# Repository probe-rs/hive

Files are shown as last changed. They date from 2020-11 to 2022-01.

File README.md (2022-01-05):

# hive
Compact and modular Raspberry Pi shield for testing probe-rs

## Navigation
| Directory | Contents |
| --- | --- |
| [component_library](./component_library/) | The global hive project component library for KiCad |
| [concept](./concept/) | Concept files of this project as well as testboards, preliminary part lists etc. |
| [daughterboard](./daughterboard/) | Template of target daughterboard and existing implementations |
| [renders_3dmodels](./renders_3dmodels/) | 3D models and renders of shields |
| [shields](./shields/) | Shields needed to assemble the testing hardware |

# Overview
For more information on the assembly and the testrack itself, please have a look at the [Hive wiki](https://github.com/probe-rs/hive/wiki)

## PCB

###### Probe Shield
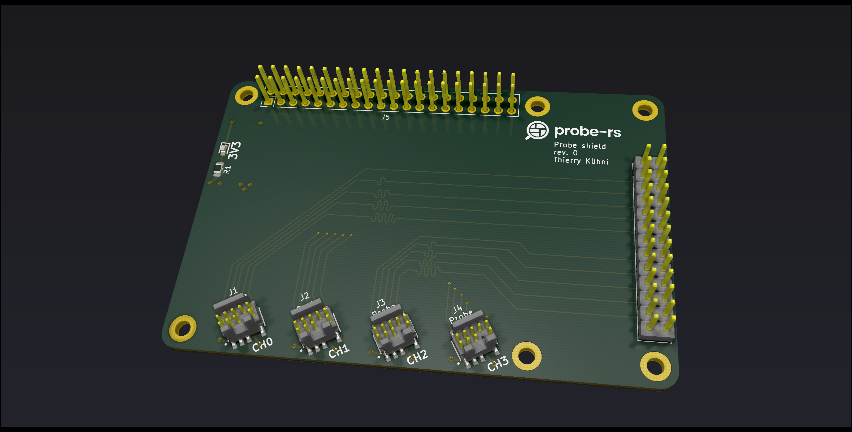
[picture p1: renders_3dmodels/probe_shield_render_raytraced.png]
Probe shield front view

###### Target Stack Shield
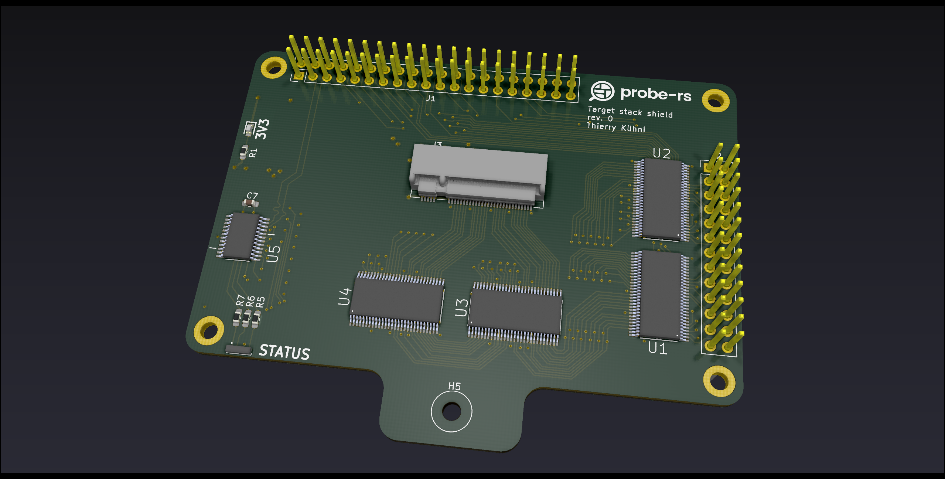
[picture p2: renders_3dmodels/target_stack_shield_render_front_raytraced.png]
Target stack shield front view

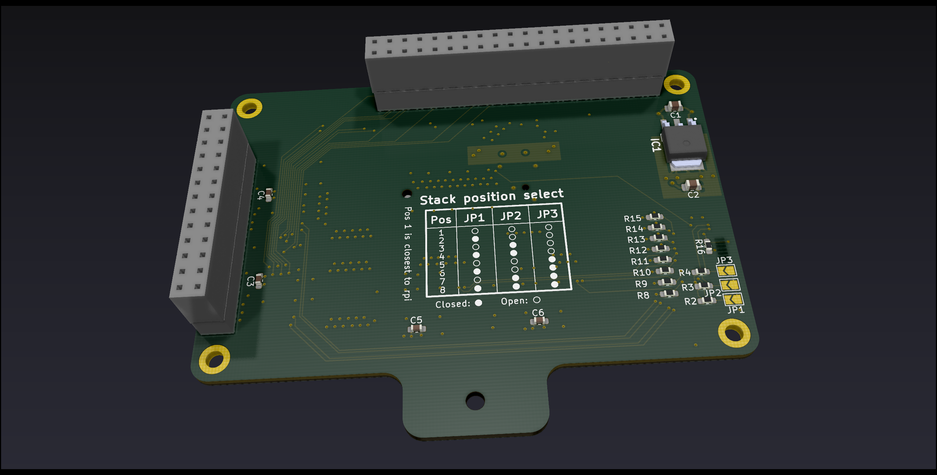
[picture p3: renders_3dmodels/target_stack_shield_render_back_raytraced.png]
Target stack shield back view


## Assembly
The full assembly consists of 1x Raspberry Pi 4 B, 1x Probe shield and up to 8x Target stack shield. Each target stack shield can hold one daughterboard with 4 targets (not included in the pictures below). Optionally you can mount a 3D printed probe holder case to put the probes in.
Full assembly view
Basic assembly front
Basic assembly top

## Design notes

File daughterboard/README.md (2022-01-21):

# Daughterboards
This Folder contains all existing implementations of Hive daughterboards. Generally the MCUs on the daughterboards are sorted by manufacturer or even by series.

If you want to create a new custom daughterboard, please refer to the [wiki page](https://github.com/probe-rs/hive/wiki/Creating-a-custom-Daughterboard) for further instructions.

| Daughterboard | MCUs |
|--|--|
| [ATSAMD_00](./ATSAMD_00/) | ATSAMD10C13A-SSUT, ATSAMD09D14A-MUT, ATSAMD51J18A-A-AU-ND, ATSAMD21E16L-AFT  |
| [ESP32_SIFIVE_00](./ESP32_SIFIVE_00/) | ESP32-S3-WROOM-1-N8R8, ESP32-S2, LoFive-R1 (FE310-G002), ESP32-C3 |
| [LPC_00](./LPC_00/) | LPC845M301JHI33Y, LPC1114FDH28/102:5, LPC55S69JBD64K, LPC1313FBD48/01,15 |
| [NRF_00](./NRF_00/) | BT40E (nRF5340), nRF52832-QFAB-T, NRF52840-USB-DONGLE, NRF51822-QFAC-R7 |
| [STM32_00](./STM32_00/) | STM32G031F4P6, STM32L151C8T6A, STM32F103C8, STM32F401CCU  |

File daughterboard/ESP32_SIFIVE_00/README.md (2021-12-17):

## Daughterboard ESP32_SIFIVE_00
This board features RISC-V and Xtensa cores.

### Targets
The following targets are implemented on this Daughterboard:
| Designation | MCU |
| --- | --- |
| target0 | ESP32-S3-WROOM-1-N8R8 |
| target1 | ESP32-S2 |
| target2 | LOFIVE-R1 (FE310-G002) |
| target3 | ESP32-C3 |

### Partlist
The partlist for this Daughterboard is available [here](https://octopart.com/bom-tool/JTwGMmL3).

### Other
The target3 and target1 devices have separate flash memory, as the currently available cores do not have any embedded flash.

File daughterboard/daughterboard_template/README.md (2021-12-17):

## Daughterboard Template
This is the Daughterboard template readme file. On implementations this text should be replaced by a short description.

More information on how to create a new Daughterboard can be found in the [wiki](https://github.com/probe-rs/hive/wiki/Creating-a-custom-Daughterboard).

### Targets
The following targets are implemented on this Daughterboard:
| Designation | MCU |
| --- | --- |
| target0 | ATSAMD21E16L-AFT |
| target1 | another MCU model |
| target2 | ... |
| target3 | ... |

### Partlist
Add a link to the partlist here. Either a link to the partlist file in the repo or an Octopart BOM.

### Other
If you need to add any more information regarding this specific Daughterboard please do so here.

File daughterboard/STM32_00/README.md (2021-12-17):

## Daughterboard STM32_00
This Daughterboard features several STM32 MCUs.

### Targets
The following targets are implemented on this Daughterboard:
| Designation | MCU |
| --- | --- |
| target0 | STM32G031F4P6 |
| target1 | STM32F401CCU6 |
| target2 | STM32L151C8T6A |
| target3 | STM32F103C8T6 |

### Partlist
The partlist for this Daughterboard is available [here](https://octopart.com/bom-tool/za3WrhSx).

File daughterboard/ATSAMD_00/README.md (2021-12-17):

## ATSAMD_00
A daughterboard which contains a selection of ATSAMD MCUs.

### Targets
The following targets are implemented on this Daughterboard:
| Designation | MCU |
| --- | --- |
| target0 | ATSAMD10C13A-SSUT |
| target1 | ATSAMD09D14A-MUT |
| target2 | ATSAMD51J18A-AU |
| target3 | ATSAMD21E16L-AFT |

### Partlist
The partlist for this Daughterboard is available [here](https://octopart.com/bom-tool/9WbPLhTP).

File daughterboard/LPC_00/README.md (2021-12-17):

## Daughterboard LPC_00
This Daughterboard features several LPC MCUs.

### Targets
The following targets are implemented on this Daughterboard:
| Designation | MCU |
| --- | --- |
| target0 | LPC845M301JHI33Y |
| target1 | LPC1114FDH28/102:5 |
| target2 | LPC55S69JBD64K |
| target3 | LPC1313FBD48/01,15 |

### Partlist
The partlist for this Daughterboard is available [here](https://octopart.com/bom-tool/fNupy8w4).

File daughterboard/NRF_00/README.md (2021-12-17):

## Daughterboard NRF_00
This Daughterboard features several nRF MCUs.

### Targets
The following targets are implemented on this Daughterboard:
| Designation | MCU |
| --- | --- |
| target0 | BT40E (nRF5340) |
| target1 | NRF52832-QFAB-T |
| target2 | NRF52840-DONGLE |
| target3 | NRF51822-QFAC-R7 |

### Partlist
The partlist for this Daughterboard is available [here](https://octopart.com/bom-tool/1QN2uwwk).

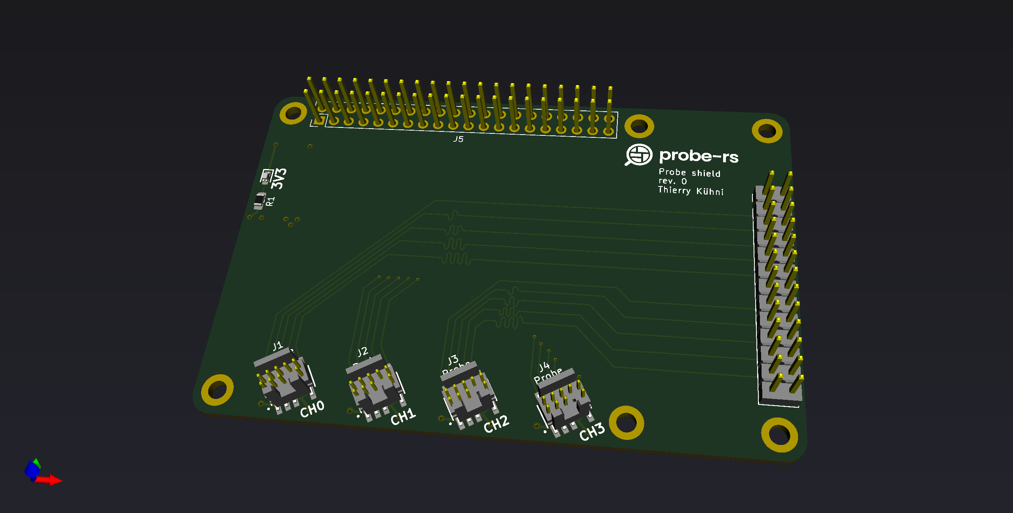
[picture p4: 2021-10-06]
renders_3dmodels/probe_shield_render.png

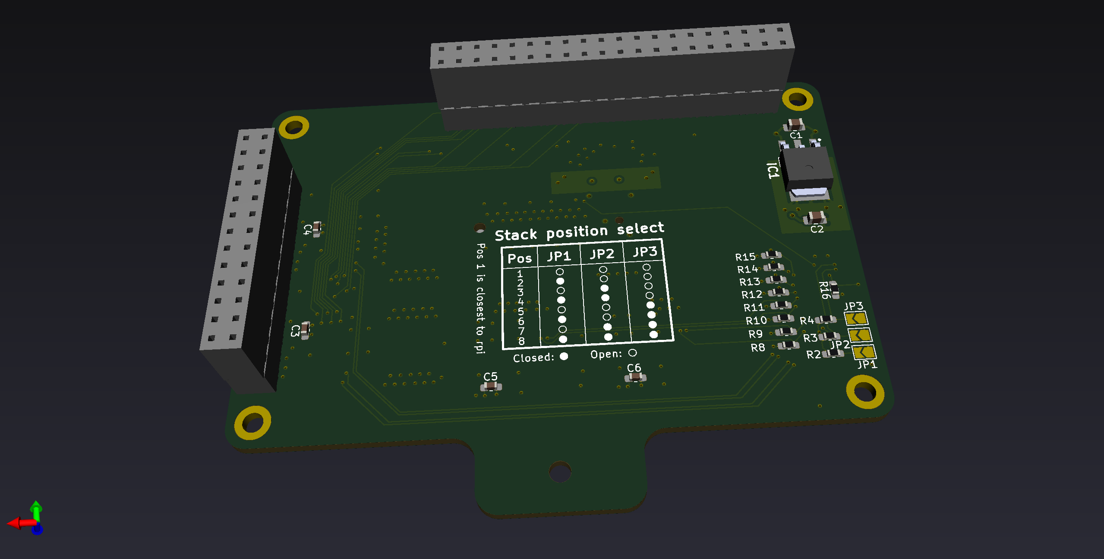
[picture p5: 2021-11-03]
renders_3dmodels/target_stack_shield_render_back.png

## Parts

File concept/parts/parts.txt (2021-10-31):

PCB Pins/Receptacles for Rpi & Probe Bus:
	https://www.samtec.com/
	ESQ-120-34-L/T-D (40Pin)
	ESQ-110-34-L/T-D (20Pin)
	
	SSQ-120-04-L/T-D (40Pin)
	SSQ-110-04-L/T-D (20Pin)
	
	TSM-120-03-F/L-DV (40Pin)
	TSM-110-03-F/L-DV (20Pin)
	with
	SSM-120-F/L-DV (40Pin)
	SSM-110-F/L-DV (20Pin)

Probe bus 23pin receptacle for probe shield:
	TSW-113-07-F/L/G-D

PCIE x4 64pin angled:
	https://www.mouser.ch/ProductDetail/Samtec/PCIE-064-02-F-D-RA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

M2 67pin:
	https://www.mouser.ch/ProductDetail/TE-Connectivity/2199230-3?qs=EQCnRgr4b6HElQOKr5ma1Q%3D%3D
	
ARM 10pin connector:
	with keying: FTSH-105-01-F-DV-007-K
	Cheaper alternative: 20021121-00010T1LF

Status LED:
	https://www.mouser.ch/ProductDetail/Kingbright/APFA2507LSURKSYKZGKC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
	https://www.mouser.ch/ProductDetail/OSRAM-Opto-Semiconductors/KRTB-AILMS1-5B5C-B1B12-0-R18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

Power OK LED:
	https://www.mouser.ch/ProductDetail/Wurth-Elektronik/150060VS75000?qs=LlUlMxKIyB1Q1Bi5mQ%2FKLw%3D%3D
	
IO expander:
	MCP23017
	PCA9535
	PCA9535CPW https://www.mouser.ch/ProductDetail/NXP-Semiconductors/PCA9535CPW118?qs=LOCUfHb8d9scuH4BeiaP2A%3D%3D
	
Digital bus switches:
	SN74CB3Q16245 (2x8Bit)
	SN74CB3T16211 (2x12Bit, 3pins required for switching, 5V to 3.3V level shift if VCC=3.3V) TVSOP-56 or TSSOP-56

Rotary DIP Switch:
	https://www.mouser.ch/ProductDetail/CUI-Devices/RDS-10S-74385-SMT?qs=zW32dvEIR3sfpstXH4BZkQ%3D%3D (10 positions, binary)

LDO 3.3V:
	https://www.mouser.ch/ProductDetail/onsemi/NCP1117DT33T5G?qs=Gev%252BmEvV0ibY9yFNc3ZYyw%3D%3D (1A, 1.2V dropout)
	https://www.mouser.ch/ProductDetail/Diodes-Incorporated/AZ1117CR-33TRG1?qs=FKu9oBikfSlEg7waHw2tMw%3D%3D (800mA, 1.3V dropout)
	
Condensator 10uF:
	https://www.mouser.ch/ProductDetail/Taiyo-Yuden/LMK212ABJ106MG-T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

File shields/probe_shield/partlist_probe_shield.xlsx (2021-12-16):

Reference | Value | Manufacturer Part number | QTY | Mouser Price (CHF) | Digikey Price (CHF) | Mouser Total | Digikey Total
> C1, C2 | Capacitor 10uF | CL21A106KPFNNNF | 2 | 0.13 | 0.15 | 0.26 | 0.3
IC1 | NCP1117DT33T5G | NCP1117DT33T5G | 1 | 0.64 | 0.62 | 0.64 | 0.62
J1 | Probe Channel 0 | FTSH-105-01-F-DV-007-K | 1 | 3.61 | 3.56 | 3.61 | 3.56
J2 | Probe Channel 1 | FTSH-105-01-F-DV-007-K | 1 | 3.61 | 3.56 | 3.61 | 3.56
J3 | Probe Channel 2 | FTSH-105-01-F-DV-007-K | 1 | 3.61 | 3.56 | 3.61 | 3.56
J4 | Probe Channel 3 | FTSH-105-01-F-DV-007-K | 1 | 3.61 | 3.56 | 3.61 | 3.56
J5 | GPIO shield connector 40pin | Adafruit 1979 | 1 | 2.77 | 2.74 | 2.77 | 2.74
J6 | probe shield connector 26pin | TSW-113-07-L-D | 1 | 2.02 | 2.01 | 2.02 | 2.01
LED1 | 3.3V OK (green) | 150060VS75000 | 1 | 0.13 | 0.14 | 0.13 | 0.14
R1 | Resistor 0603 560Ohm |  | 1 | - | -
 |  |  |  |  | Total CHF | 20.26 | 20.05

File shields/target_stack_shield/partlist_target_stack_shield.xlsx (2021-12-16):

Reference | Value | Manufacturer Part number | QTY | Mouser Price (CHF) | Digikey Price (CHF) | Mouser Total | Digikey Total
> C1, C2 | Capacitor 0805 10uF | CL21A106KPFNNNF | 2 | 0.13 | 0.15 | 0.26 | 0.3
> C3-C7 | Capacitor 0603 100nF |  | 5 | - | -
IC1 | NCP1117DT33T5G | NCP1117DT33T5G | 1 | 0.64 | 0.62 | 0.64 | 0.62
J1 | GPIO shield connector 40pin | Adafruit 1979 | 1 | 2.77 | 2.74 | 2.77 | 2.74
J2 | probe shield connector 26pin | Adafruit 1112 | 1 | 1.82 | 1.81 | 1.82 | 1.81
J3 | PCIE M.2 Key B 4.2H | 2199230-3 | 1 | 1.21 | 1.2 | 1.21 | 1.2
LED1 | 3.3V OK (green) | 150060VS75000 | 1 | 0.13 | 0.14 | 0.13 | 0.14
LED2 | KRTB_AILMS1-5B5C-B1B12-0-R18 | KRTB AILMS1-5B5C-B1B12-0-R18 | 1 | 0.38 | 0.38 | 0.38 | 0.38
R1 | Resistor 0603 560Ohm |  | 1 | - | -
> R2-R4, R8-R16 | Resistor 0603 100kOhm |  | 12 | - | -
R5 | Resistor 0603 6.8kOhm |  | 2 | - | -
R6 | Resistor 0603 10kOhm |  | 1 | - | -
> U1-U4 | SN74CB3T16211DGGR | SN74CB3T16211DGGR | 4 | 2.67 | 2.64 | 10.68 | 10.56
U5 | PCA9535CPW,118 |  | 1 | 1.92 | 1.9 | 1.92 | 1.9
 |  |  |  |  | Total CHF | 19.81 | 19.65

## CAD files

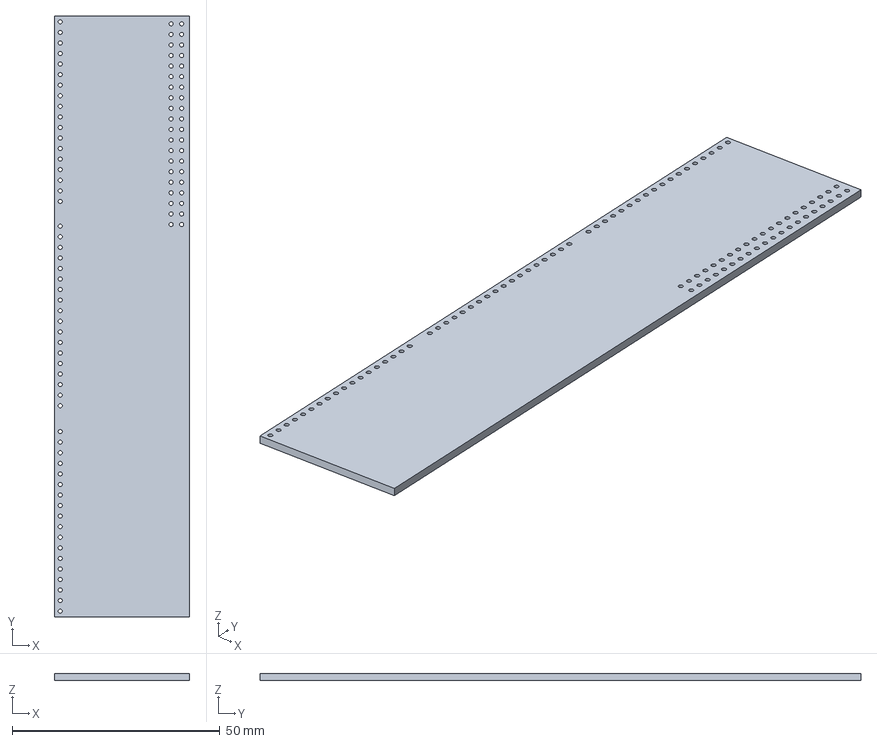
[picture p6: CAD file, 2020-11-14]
3lanes/3lanes/3lanes.step
32.5 x 144.5 x 1.60 mm

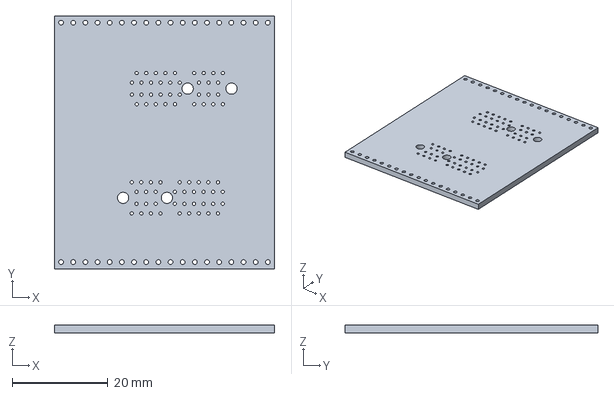
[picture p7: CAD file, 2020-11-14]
8channels/probe-rs-hive.step
46.0 x 52.8 x 1.60 mm

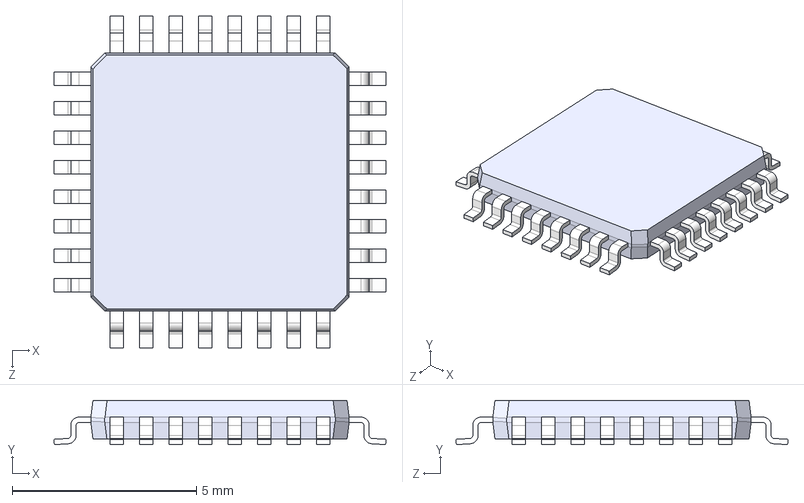
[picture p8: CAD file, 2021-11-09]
daughterboard/ATSAMD_00/component_library/3d_models/ATSAMD21E16L-AFT.step
9.00 x 1.20 x 9.00 mm

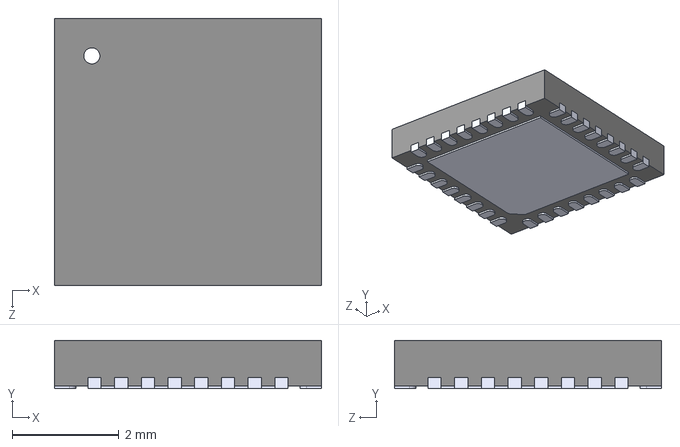
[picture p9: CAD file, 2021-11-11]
daughterboard/ESP32_SIFIVE_00/component_library/3d_models/ESP32-C3FH4.step
5.00 x 0.9 x 5.00 mm

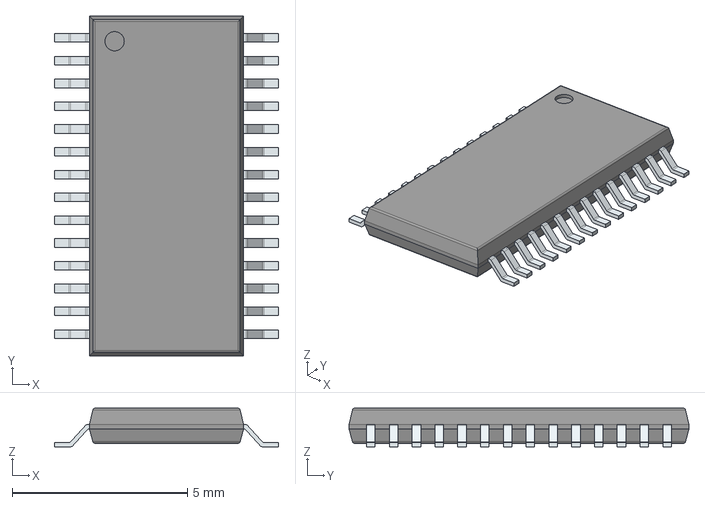
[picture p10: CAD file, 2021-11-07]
daughterboard/LPC_00/component_library/3d_models/LPC1114FDH28_102_5.stp
6.40 x 9.70 x 1.10 mm
PinsArrayLR

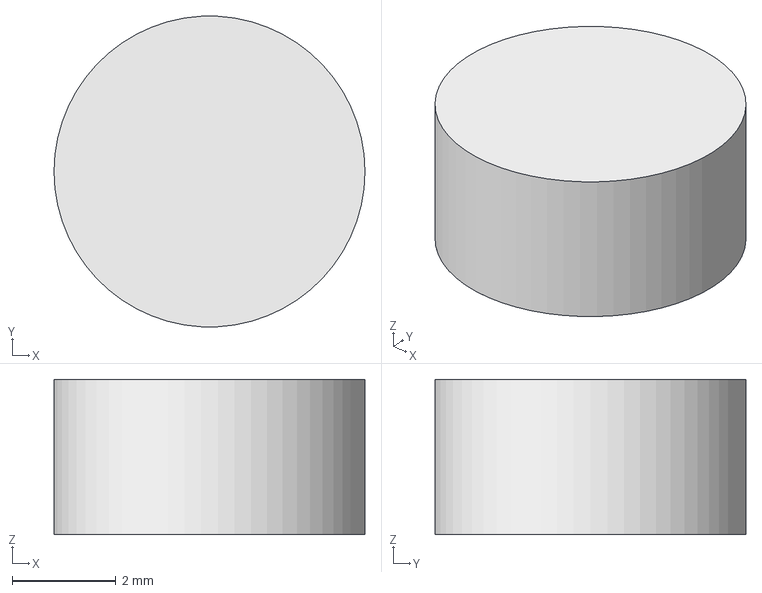
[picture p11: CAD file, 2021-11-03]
renders_3dmodels/Assembly/magnet.FCStd
6.00 x 5.99 x 3.00 mm

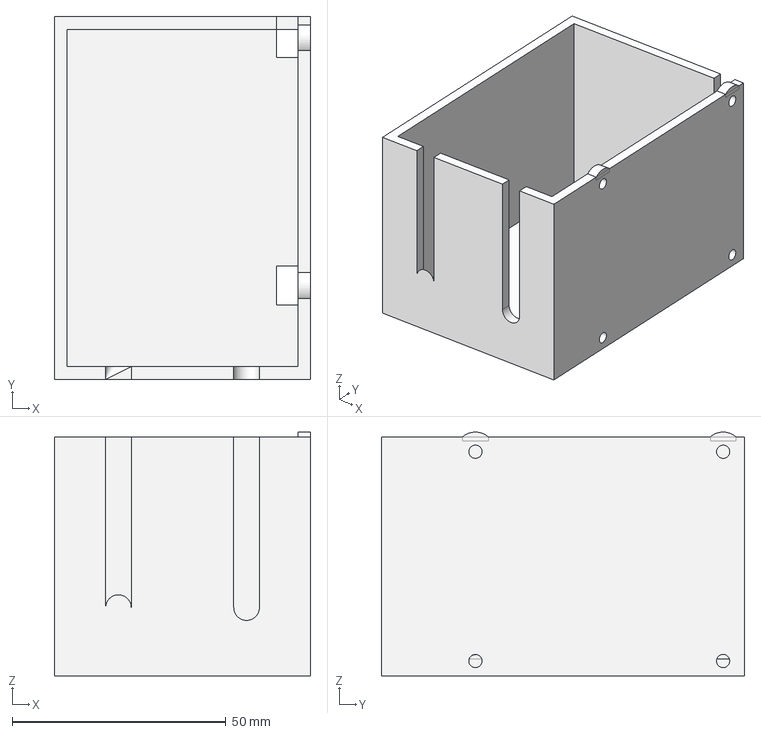
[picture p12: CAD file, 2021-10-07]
renders_3dmodels/Probe_holder/probe_holder_60mm.step
60.0 x 85.0 x 57.1 mm

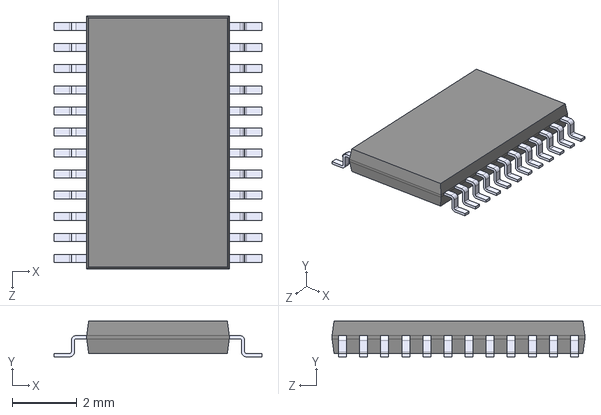
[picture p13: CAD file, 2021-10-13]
component_library/3d_models/PCA9535CPW_118.step
6.40 x 1.10 x 7.80 mm

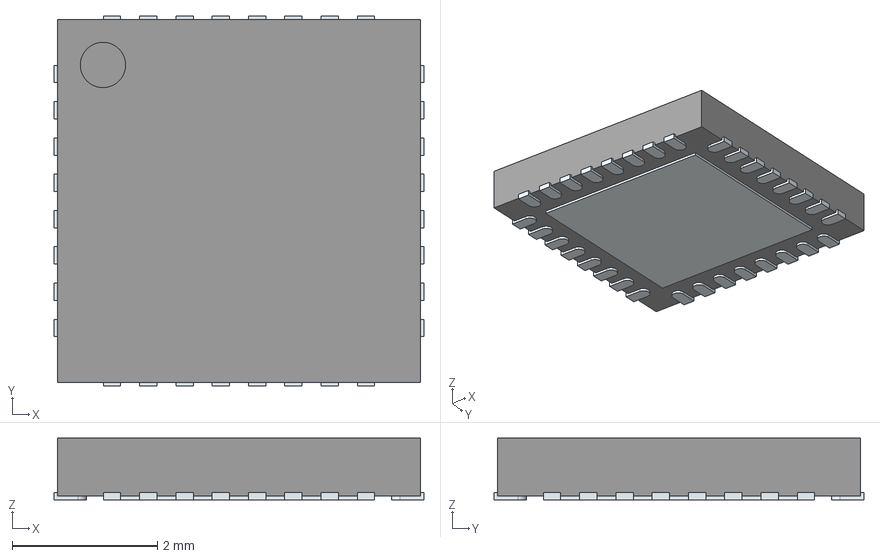
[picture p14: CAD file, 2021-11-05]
daughterboard/LPC_00/component_library/3d_models/LPC845M301JHI33Y.stp
5.10 x 5.10 x 0.85 mm
ThermalPin
PinsArrayLR
PinsArrayTB

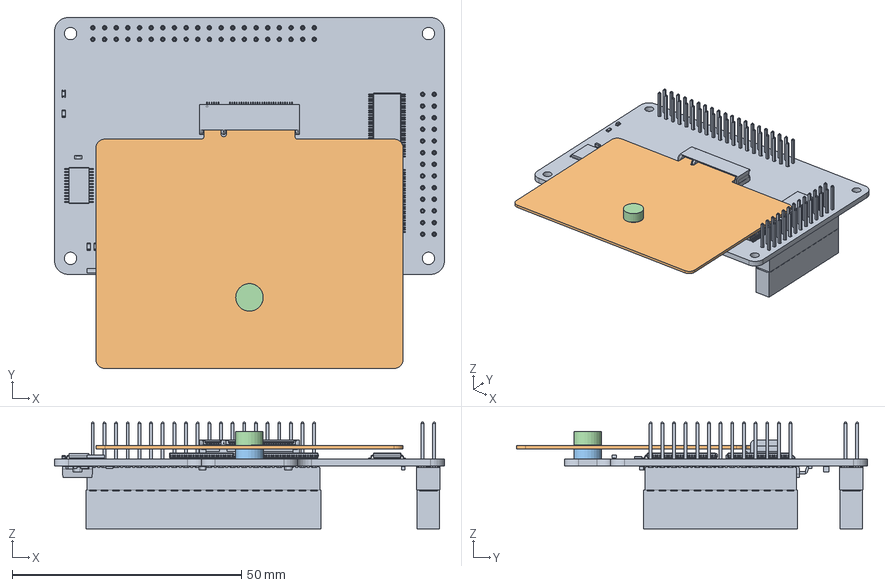
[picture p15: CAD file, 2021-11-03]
renders_3dmodels/Assembly/target_stack_shield_wDaughterboard.FCStd
85.0 x 76.5 x 23.2 mm
target_stack_shield1_001
daughterboard_template1_001
magnet_001
magnet_002

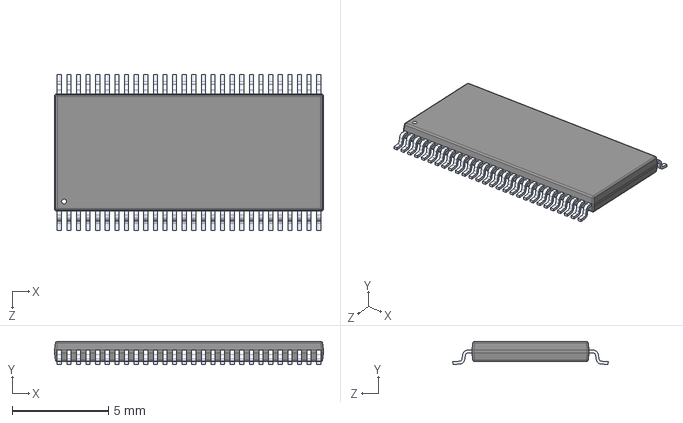
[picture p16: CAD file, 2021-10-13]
component_library/3d_models/SN74CB3T16211DGGR.step
14.0 x 1.20 x 8.10 mm

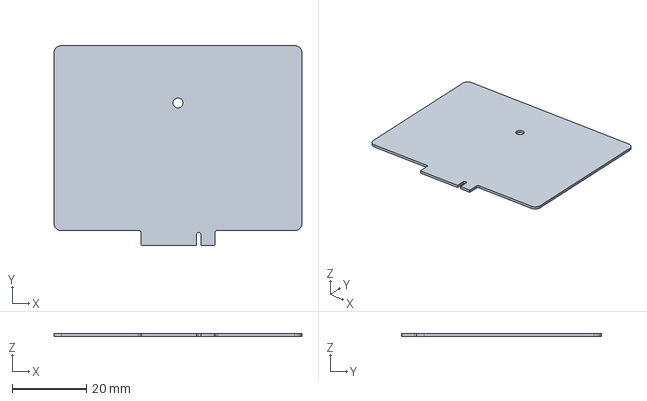
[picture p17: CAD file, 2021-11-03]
renders_3dmodels/Assembly/daughterboard_template.step
67.0 x 54.0 x 0.8 mm

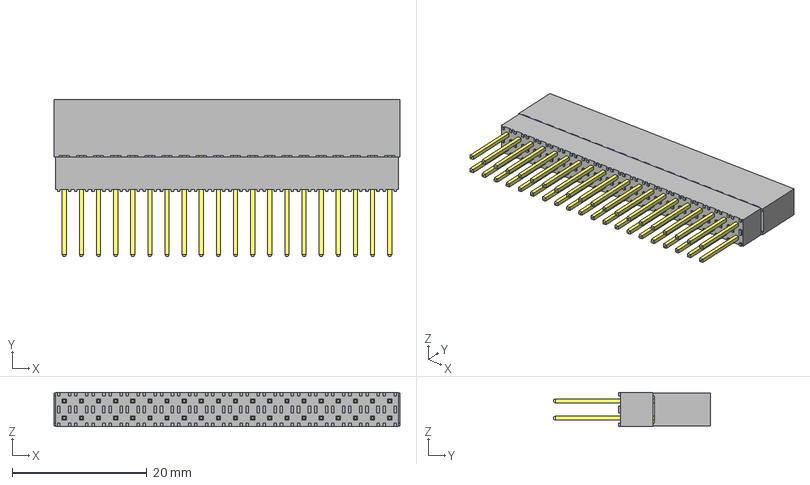
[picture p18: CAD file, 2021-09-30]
component_library/3d_models/ESQ-120-24-L-D.stp
51.3 x 23.2 x 5.08 mm
_ESQ-120-24-L-D_socket
_ESQ-120-24-L-D_pins
_ESQ-120-24-G-D-LL_bpins

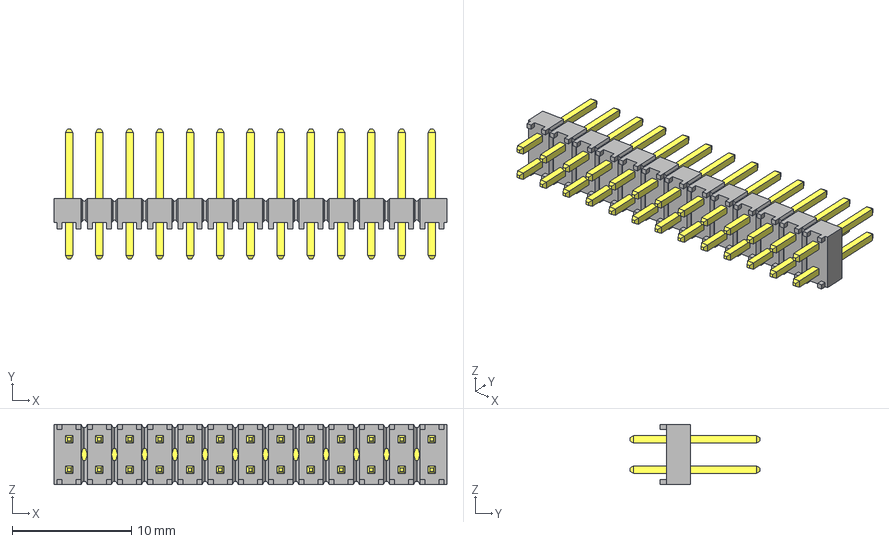
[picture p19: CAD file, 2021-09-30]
component_library/3d_models/TSW-113-07-F-D.stp
33.0 x 10.9 x 5.08 mm
_TSW-113-07-F-D_body
_T-1S6-07-TSW-1-07-13-D

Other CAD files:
renders_3dmodels/Probe_holder/probe_holder.FCStd
renders_3dmodels/Assembly/rpi4b.step
component_library/3d_models/FTSH-105-01-F-DV-007-K.stp
component_library/3d_models/ESQ-113-24-L-D.stp
component_library/3d_models/150060VS75000.stp
component_library/3d_models/2199230-3.step
component_library/3d_models/CUI_DEVICES_RDS-10S-74385-SMT.step
component_library/3d_models/KRTB_AILMS1-5B5C-B1B12-0-R18.stp
component_library/3d_models/NCP1117DT33T5G.STEP
renders_3dmodels/Assembly/m2_5_standoff_16mm.FCStd
renders_3dmodels/Assembly/m2_5_standoff_16mm.step
renders_3dmodels/Assembly/m2_5_standoff_18mm.FCStd
renders_3dmodels/Assembly/m2_5_standoff_18mm.step
renders_3dmodels/Assembly/rpi4b.FCStd

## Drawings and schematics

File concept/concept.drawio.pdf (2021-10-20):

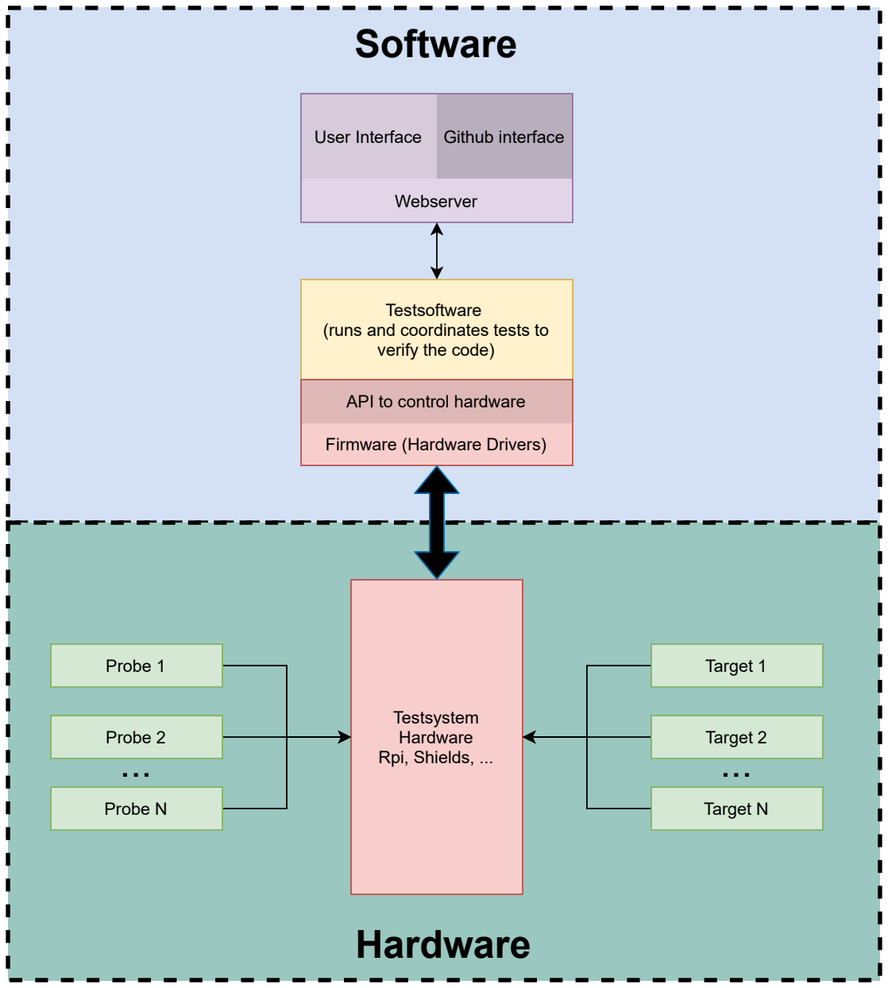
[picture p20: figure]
User Interface Github interface; Webserver; Testsoftware (runs and coordinates tests to verify the code); Firmware (Hardware Drivers); API to control hardware; Testsystem Hardware Rpi, Shields, ...; Probe 1; Probe 2; Probe N; Target 1; Target 2; Target N; Hardware; Software

# Layout

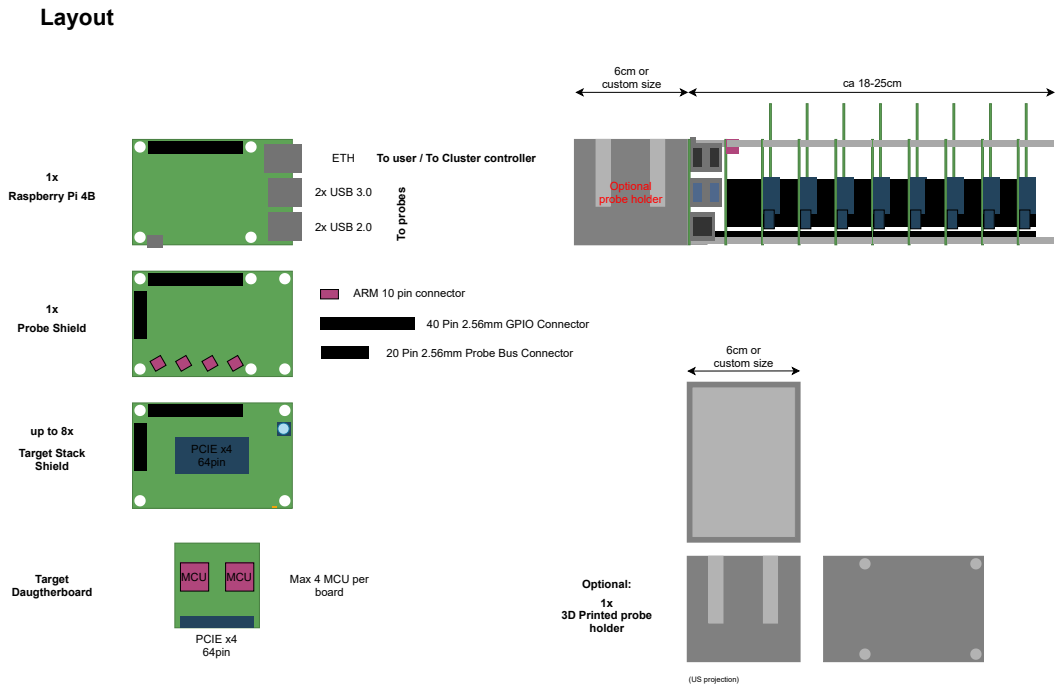
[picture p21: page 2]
PCIE x4 64pin; Raspberry Pi 4B; Probe Shield; Target Stack Shield; 2x USB 3.0; 2x USB 2.0; ETH; To probes; Target Daugtherboard; MCU; Max 4 MCU per; board; 3D Printed probe holder; Optional:; 6cm or custom size; Optional probe holder; (US projection)

To user / To Cluster controller

ARM 10 pin connector

40 Pin 2.56mm GPIO Connector

20 Pin 2.56mm Probe Bus Connector

# Connectors

ESQ-120-34-L/T-D (40Pin)
ESQ-110-34-L/T-D (20Pin)

Possible GPIO shield / Probe shield pass through connectors:

Price: ~8-10CHF
Availability: Non plated, mediocre

SSQ-120-04-L/T-D (40Pin)
SSQ-110-04-L/T-D (20Pin)

Price: ~3-6CHF
Availability: non plated ok

PCB

16.13mm

7.11mm

PCB

8.51mm

14.83mm

Board spacing ca 16mm

TSM-120-03-F/L-DV (40Pin)
TSM-110-03-F/L-DV (20Pin)
with
SSM-120-F/L-DV (40Pin)
SSM-110-F/L-DV (20Pin)

Price: ~9CHF per pair
PCB | Availability: ok

7.37mm

14.48mm

Board spacing ca 17mm

Possible ARM 10pin debug connectors:

FTSH-105-01-F-DV-007-K

Price: ~3-4CHF
Availability: ok

ESQ-120-14-L/T-D (40Pin)
ESQ-110-14-L/T-D (20Pin)

Price: ~4-7CHF
PCB | Availability: Non plated, good

11.5mm

12.19mm

Board spacing ca 16mm

Possible RPI to first shield connectors:

Adafruit 1112

Price: ~2CHF
PCB | Availability: ok

23mm

10mm

Can't be used with SSQ or

TSM/SSM

ESQ-120-14-L/T-D

Price: ~7CHF
PCB | Availability: ok

11.05mm

12.19mm

Can't be used with SSQ or

TSM/SSM

# Daughterboard PCI options

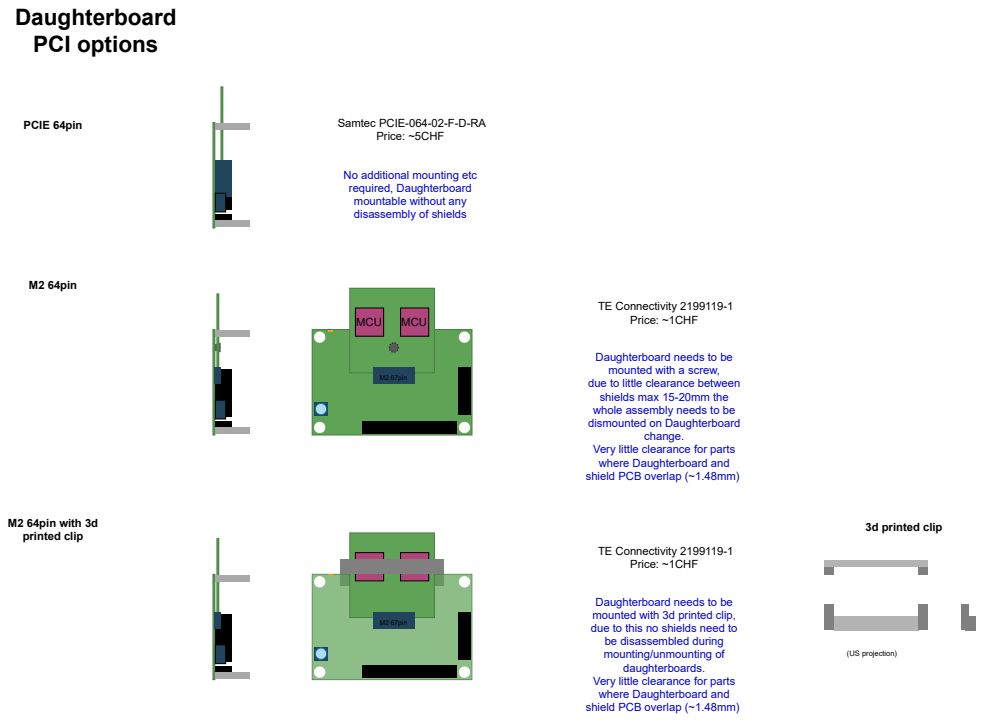
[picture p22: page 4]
PCIE 64pin; Samtec PCIE-064-02-F-D-RA; Price: ~5CHF; M2 64pin; MCU; M2 67pin; TE Connectivity 2199119-1 Price: ~1CHF; change.; M2 64pin with 3d printed clip; (US projection); 3d printed clip

No additional mounting etc
required, Daughterboard
mountable without any
disassembly of shields

Daughterboard needs to be
mounted with a screw,
due to little clearance between
shields max 15-20mm the
whole assembly needs to be
dismounted on Daughterboard

Very little clearance for parts
where Daughterboard and
shield PCB overlap (~1.48mm)

mounted with 3d printed clip,
due to this no shields need to
be disassembled during
mounting/unmounting of
daughterboards.

# Daughterboard PCI options

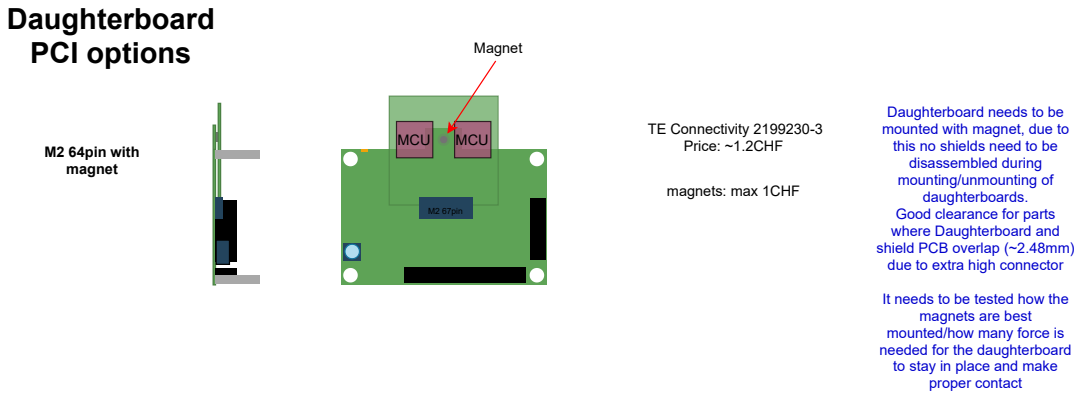
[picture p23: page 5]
M2 64pin with magnet; TE Connectivity 2199230-3; Price: ~1.2CHF MCU; MCU; M2 67pin; Magnet; magnets: max 1CHF

Daughterboard needs to be
mounted with magnet, due to
this no shields need to be
disassembled during
mounting/unmounting of
daughterboards.
Good clearance for parts
where Daughterboard and
shield PCB overlap (~2.48mm)
due to extra high connector

It needs to be tested how the
magnets are best
mounted/how many force is
needed for the daughterboard
to stay in place and make
proper contact

# Target Stack Shield

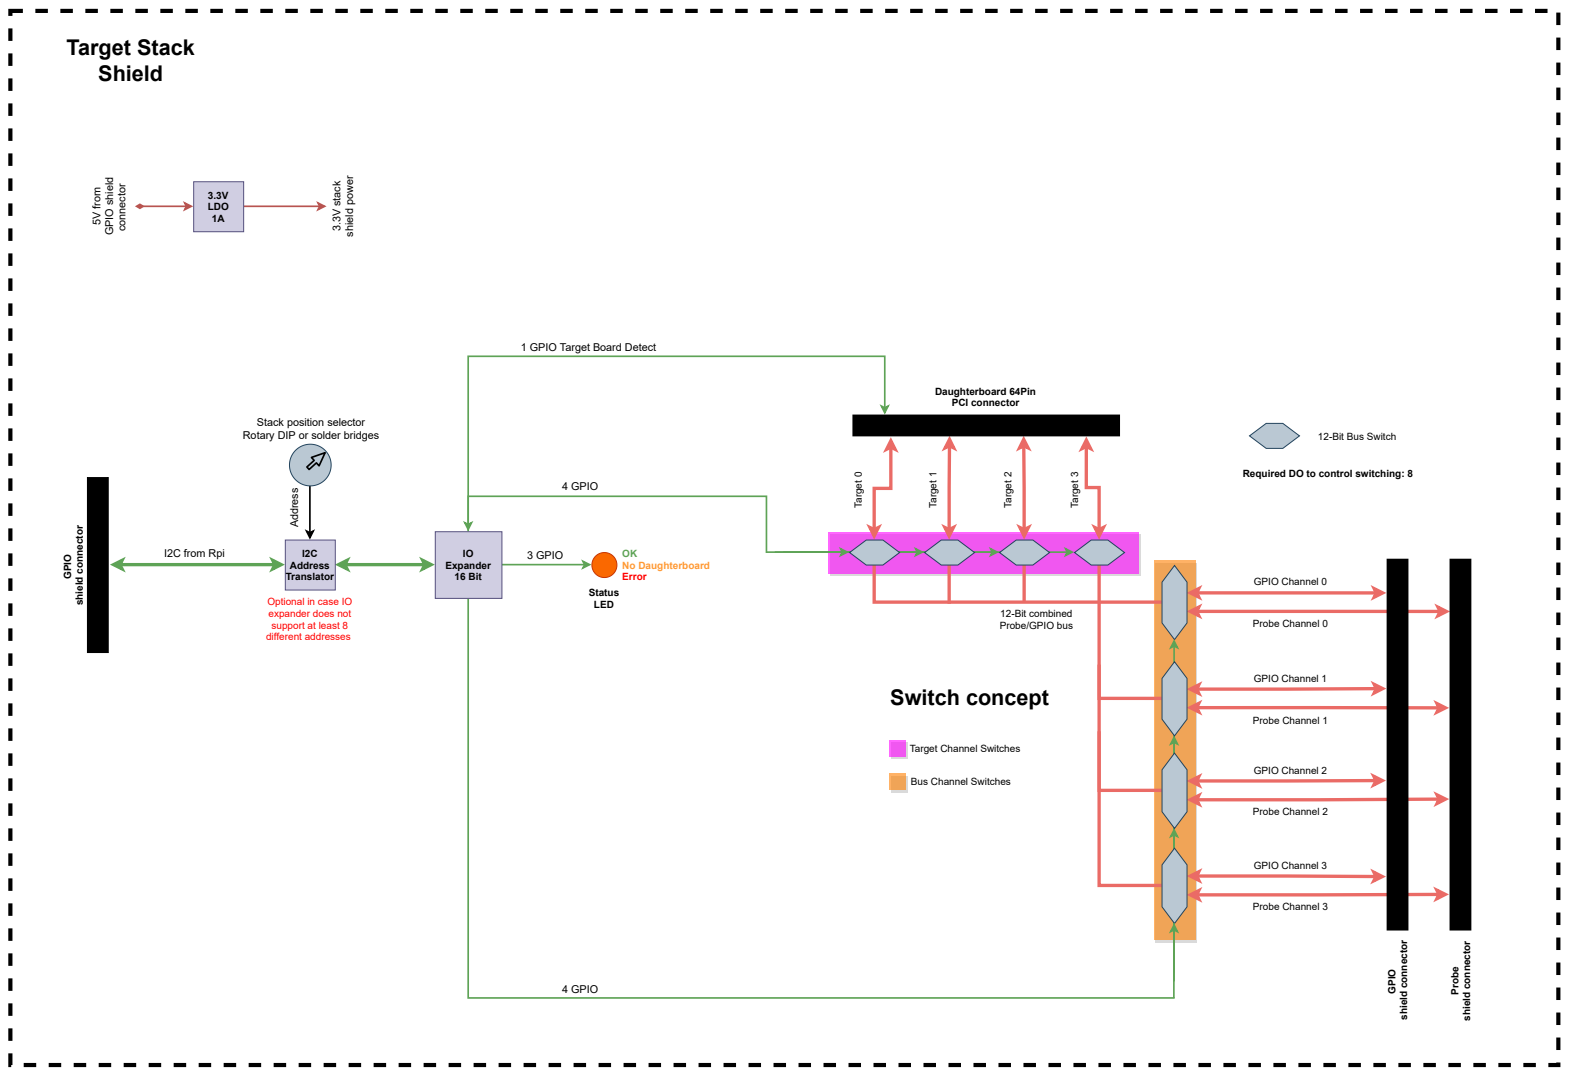
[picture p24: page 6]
I2C from Rpi; Expander 16 Bit; Switch concept; GPIO; shield connector; GPIO Channel 0; GPIO Channel 1; GPIO Channel 2; GPIO Channel 3; Target 0; Target 1; Target 2; Target 3; Daughterboard 64Pin PCI connector; 4 GPIO; I2C Address; Translator; 3.3V LDO; 5V from; GPIO shield; connector; 3.3V stack; shield power; Address; Probe; Probe Channel 0; Probe Channel 1; Probe Channel 2; Probe Channel 3; Status LED; OK No Daughterboard Error; 3 GPIO

1 GPIO Target Board Detect

Stack position selector
Rotary DIP or solder bridges

12-Bit Bus Switch

Required DO to control switching: 8

Optional in case IO
expander does not
support at least 8
different addresses

12-Bit combined
Probe/GPIO bus

Target Channel Switches

Bus Channel Switches
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

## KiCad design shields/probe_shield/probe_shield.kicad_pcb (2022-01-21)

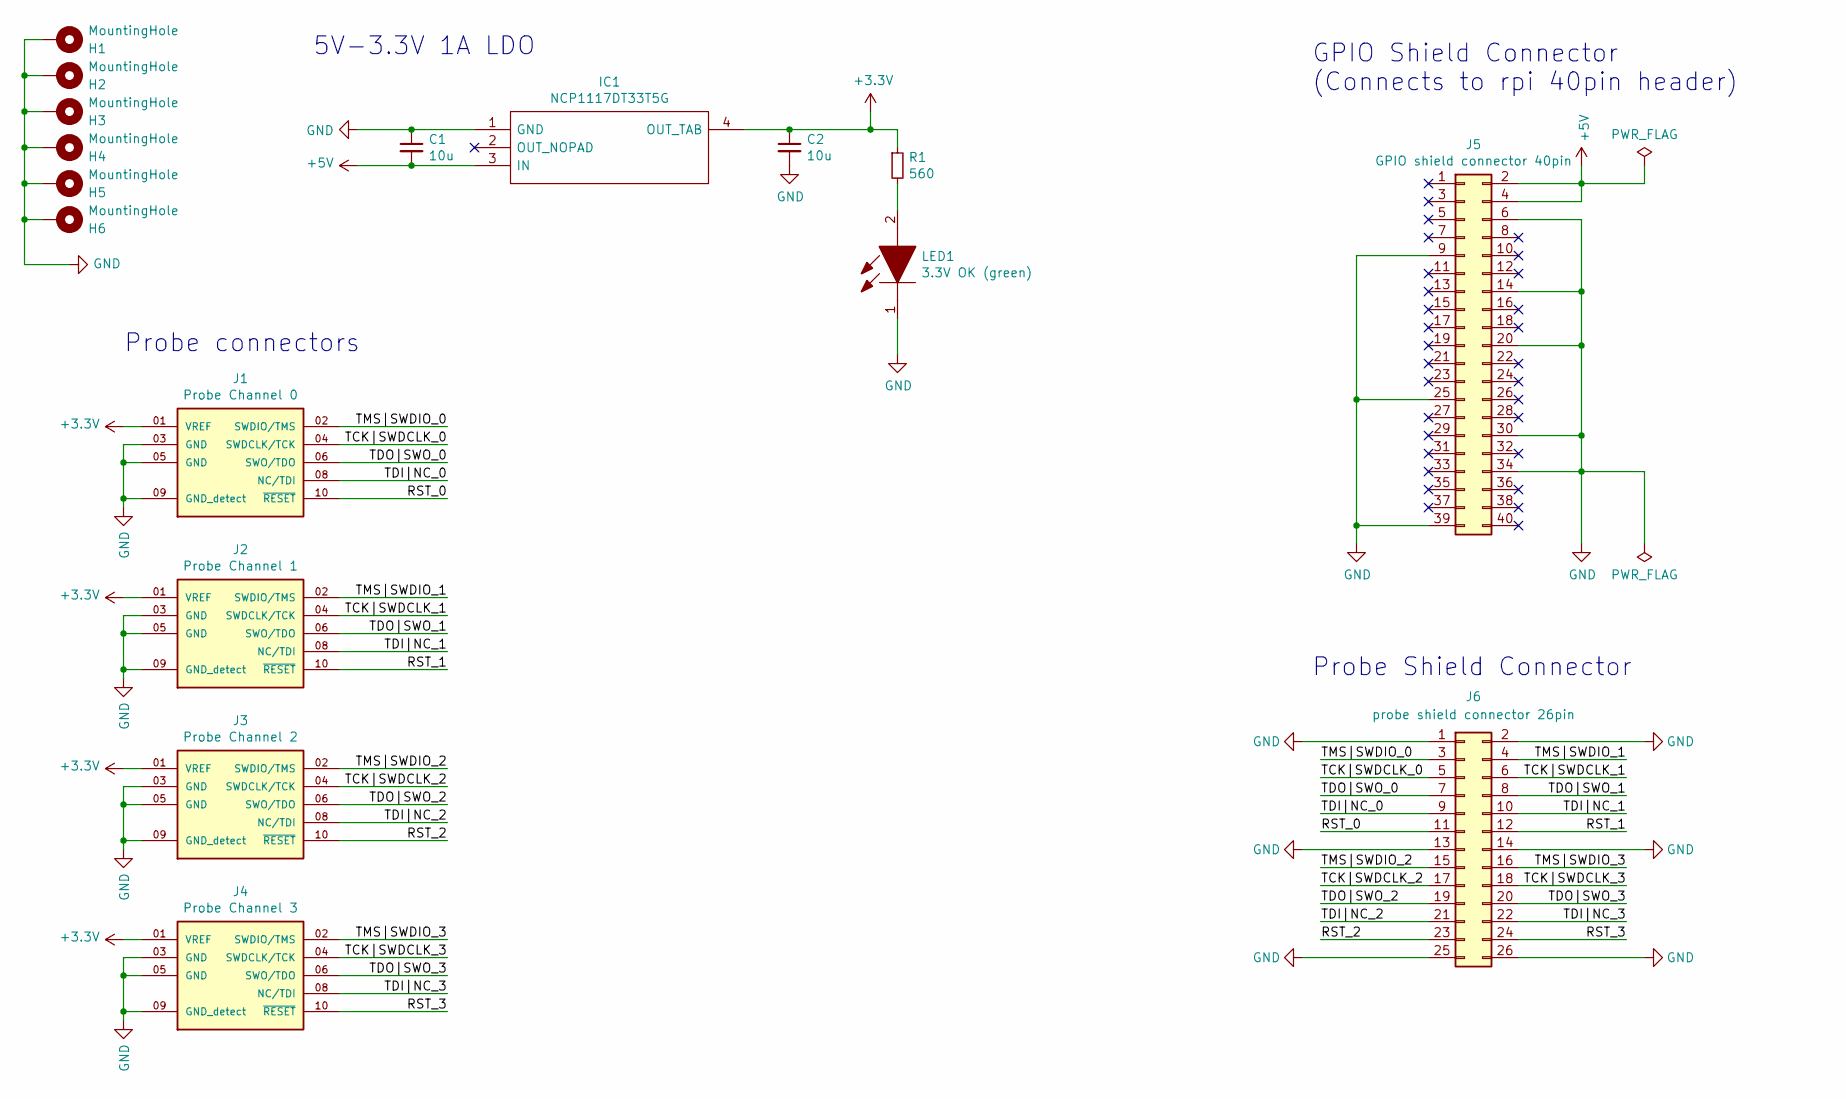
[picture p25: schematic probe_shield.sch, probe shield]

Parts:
C1, C2: 10u; C_0805_2012Metric_Pad1.15x1.40mm_HandSolder; Digikey Price (CHF) 0.15
H1, H2, H3, H4, H5, H6: MountingHole; MountingHole_2.7mm_M2.5_DIN965_Pad
IC1: NCP1117DT33T5G; TO229P990X238-4N; Mouser Part Number 863-NCP1117DT33T5G
J1: Probe Channel 0; SAMTEC_FTSH-105-01-F-DV-007; PARTREV R; Digikey Price (CHF) 3.56
J2: Probe Channel 1; SAMTEC_FTSH-105-01-F-DV-007; PARTREV R; Digikey Price (CHF) 3.56
J3: Probe Channel 2; SAMTEC_FTSH-105-01-F-DV-007; PARTREV R; Digikey Price (CHF) 3.56
J4: Probe Channel 3; SAMTEC_FTSH-105-01-F-DV-007; PARTREV R; Digikey Price (CHF) 3.56
J5: GPIO shield connector 40pin; PinHeader_2x20_P2.54mm_Vertical_gpio_shield; Manufacturer_Part_Number Adafruit 1979; Digikey Price (CHF) 2.74
J6: probe shield connector 26pin; PinHeader_2x13_P2.54mm_Vertical_probe_shield_male; Manufacturer_Part_Number TSW-113-07-L-D; Digikey Price (CHF) 2.01
LED1: 3.3V OK (green); LEDC1608X80N; Mouser Part Number 710-150060VS75000
R1: 560; R_0805_2012Metric_Pad1.15x1.40mm_HandSolder

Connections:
+3V3: C2.1, IC1.4 (OUT_TAB), J1.01 (VREF), J2.01 (VREF), J3.01 (VREF), J4.01 (VREF), R1.1
+5V: C1.2, IC1.3 (IN), J5.2, J5.4
/RST_0: J1.10 (~RESET~), J6.11
/RST_1: J2.10 (~RESET~), J6.12
/RST_2: J3.10 (~RESET~), J6.23
/RST_3: J4.10 (~RESET~), J6.24
/TCK|SWDCLK_0: J1.04 (SWDCLK/TCK), J6.5
/TCK|SWDCLK_1: J2.04 (SWDCLK/TCK), J6.6
/TCK|SWDCLK_2: J3.04 (SWDCLK/TCK), J6.17
/TCK|SWDCLK_3: J4.04 (SWDCLK/TCK), J6.18
/TDI|NC_0: J1.08 (NC/TDI), J6.9
/TDI|NC_1: J2.08 (NC/TDI), J6.10
/TDI|NC_2: J3.08 (NC/TDI), J6.21
/TDI|NC_3: J4.08 (NC/TDI), J6.22
/TDO|SWO_0: J1.06 (SWO/TDO), J6.7
/TDO|SWO_1: J2.06 (SWO/TDO), J6.8
/TDO|SWO_2: J3.06 (SWO/TDO), J6.19
/TDO|SWO_3: J4.06 (SWO/TDO), J6.20
/TMS|SWDIO_0: J1.02 (SWDIO/TMS), J6.3
/TMS|SWDIO_1: J2.02 (SWDIO/TMS), J6.4
/TMS|SWDIO_2: J3.02 (SWDIO/TMS), J6.15
/TMS|SWDIO_3: J4.02 (SWDIO/TMS), J6.16
GND: C1.1, C2.2, H1.1, H2.1, H3.1, H4.1, H5.1, H6.1, IC1.1 (GND), J1.03 (GND), J1.05 (GND), J1.09 (GND_detect), J2.03 (GND), J2.05 (GND), J2.09 (GND_detect), J3.03 (GND), J3.05 (GND), J3.09 (GND_detect), J4.03 (GND), J4.05 (GND), J4.09 (GND_detect), J5.6, J5.9, J5.14, J5.20, J5.25, J5.30, J5.34, J5.39, J6.1, J6.2, J6.13, J6.14, J6.25, J6.26, LED1.1
unnamed: LED1.2, R1.2

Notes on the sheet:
5V-3.3V 1A LDO
Probe connectors
GPIO Shield Connector (Connects to rpi 40pin header)
Probe Shield Connector

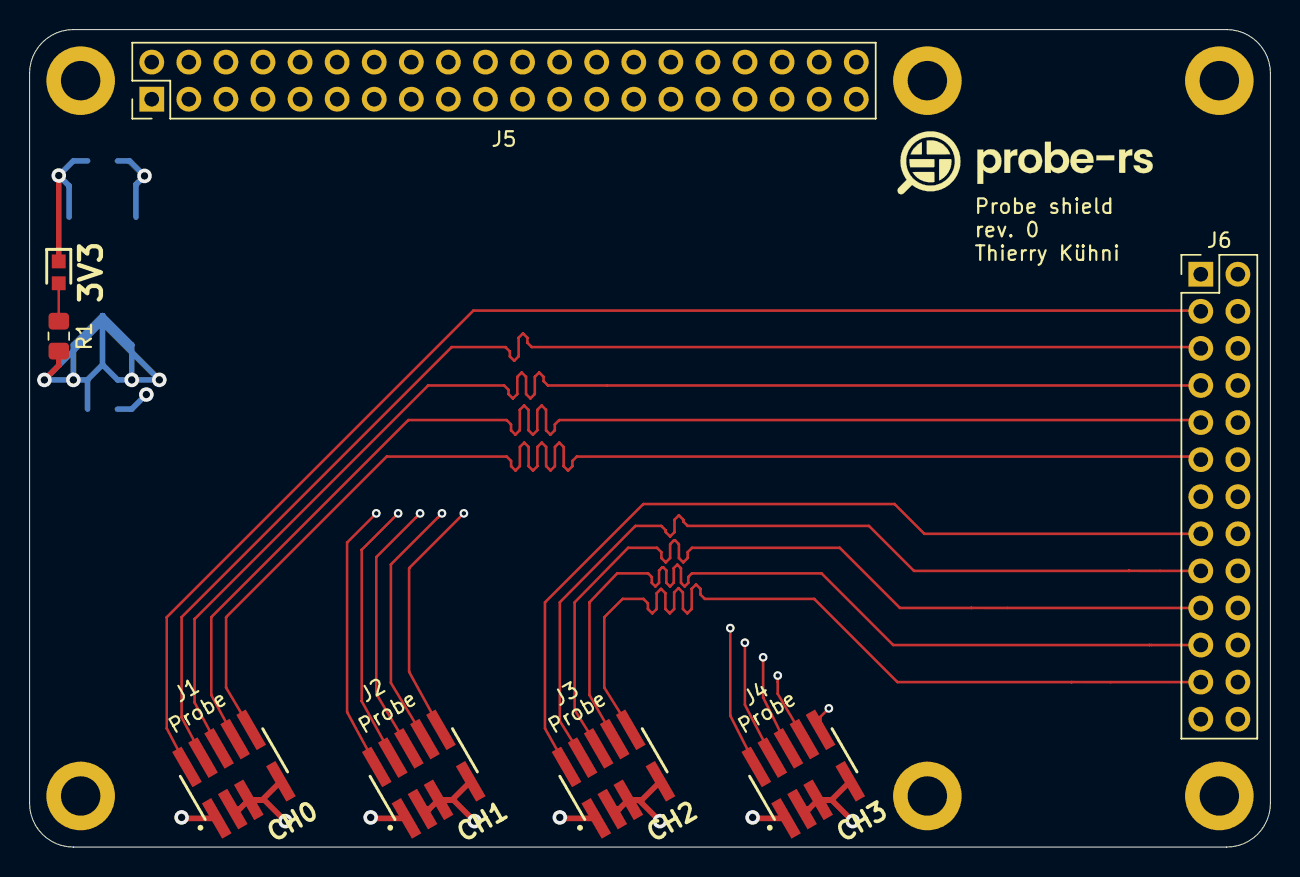
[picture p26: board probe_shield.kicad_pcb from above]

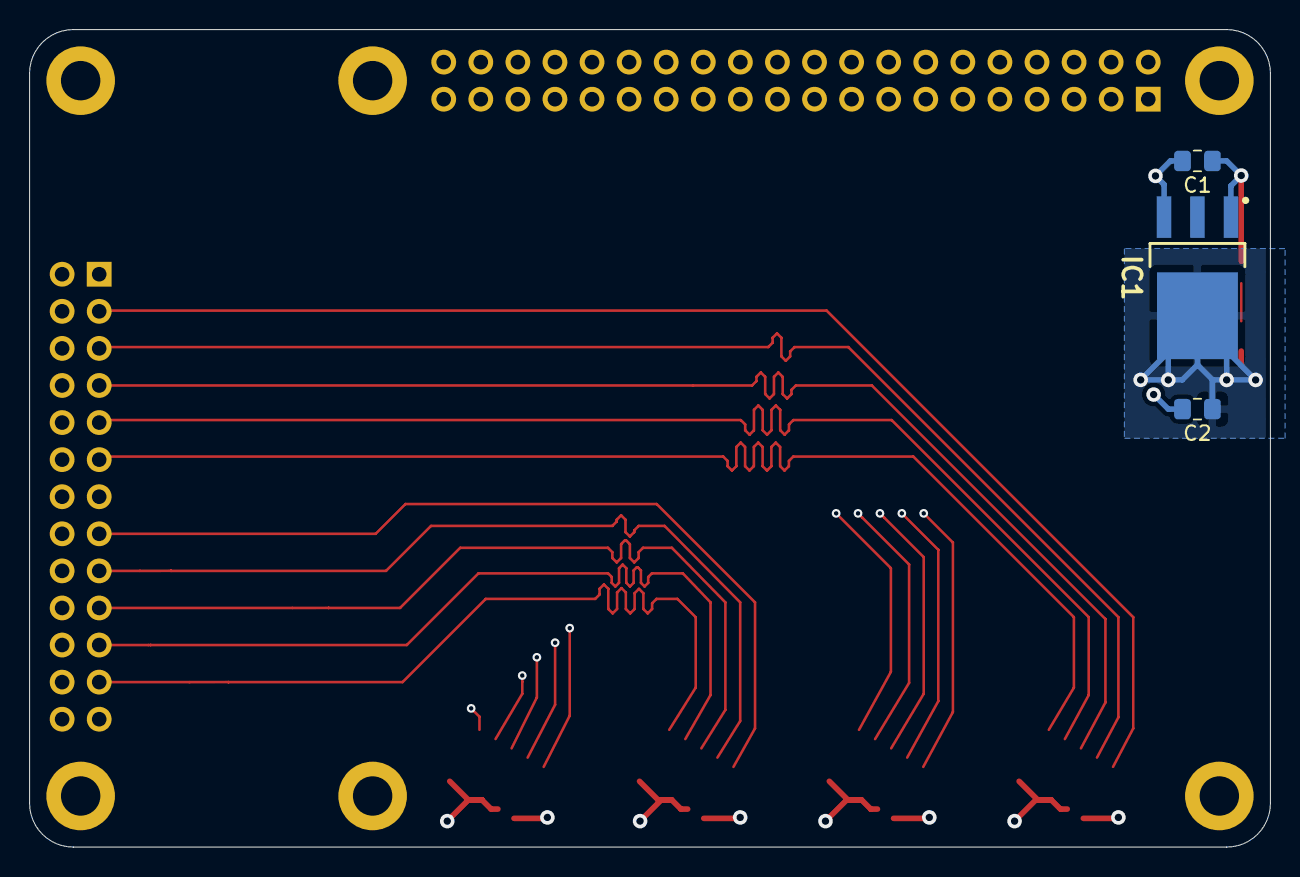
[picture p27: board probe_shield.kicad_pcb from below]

Board: 4 copper layers, 85.0 x 56.0 mm, 17 parts (3 on the bottom side), 24 nets.

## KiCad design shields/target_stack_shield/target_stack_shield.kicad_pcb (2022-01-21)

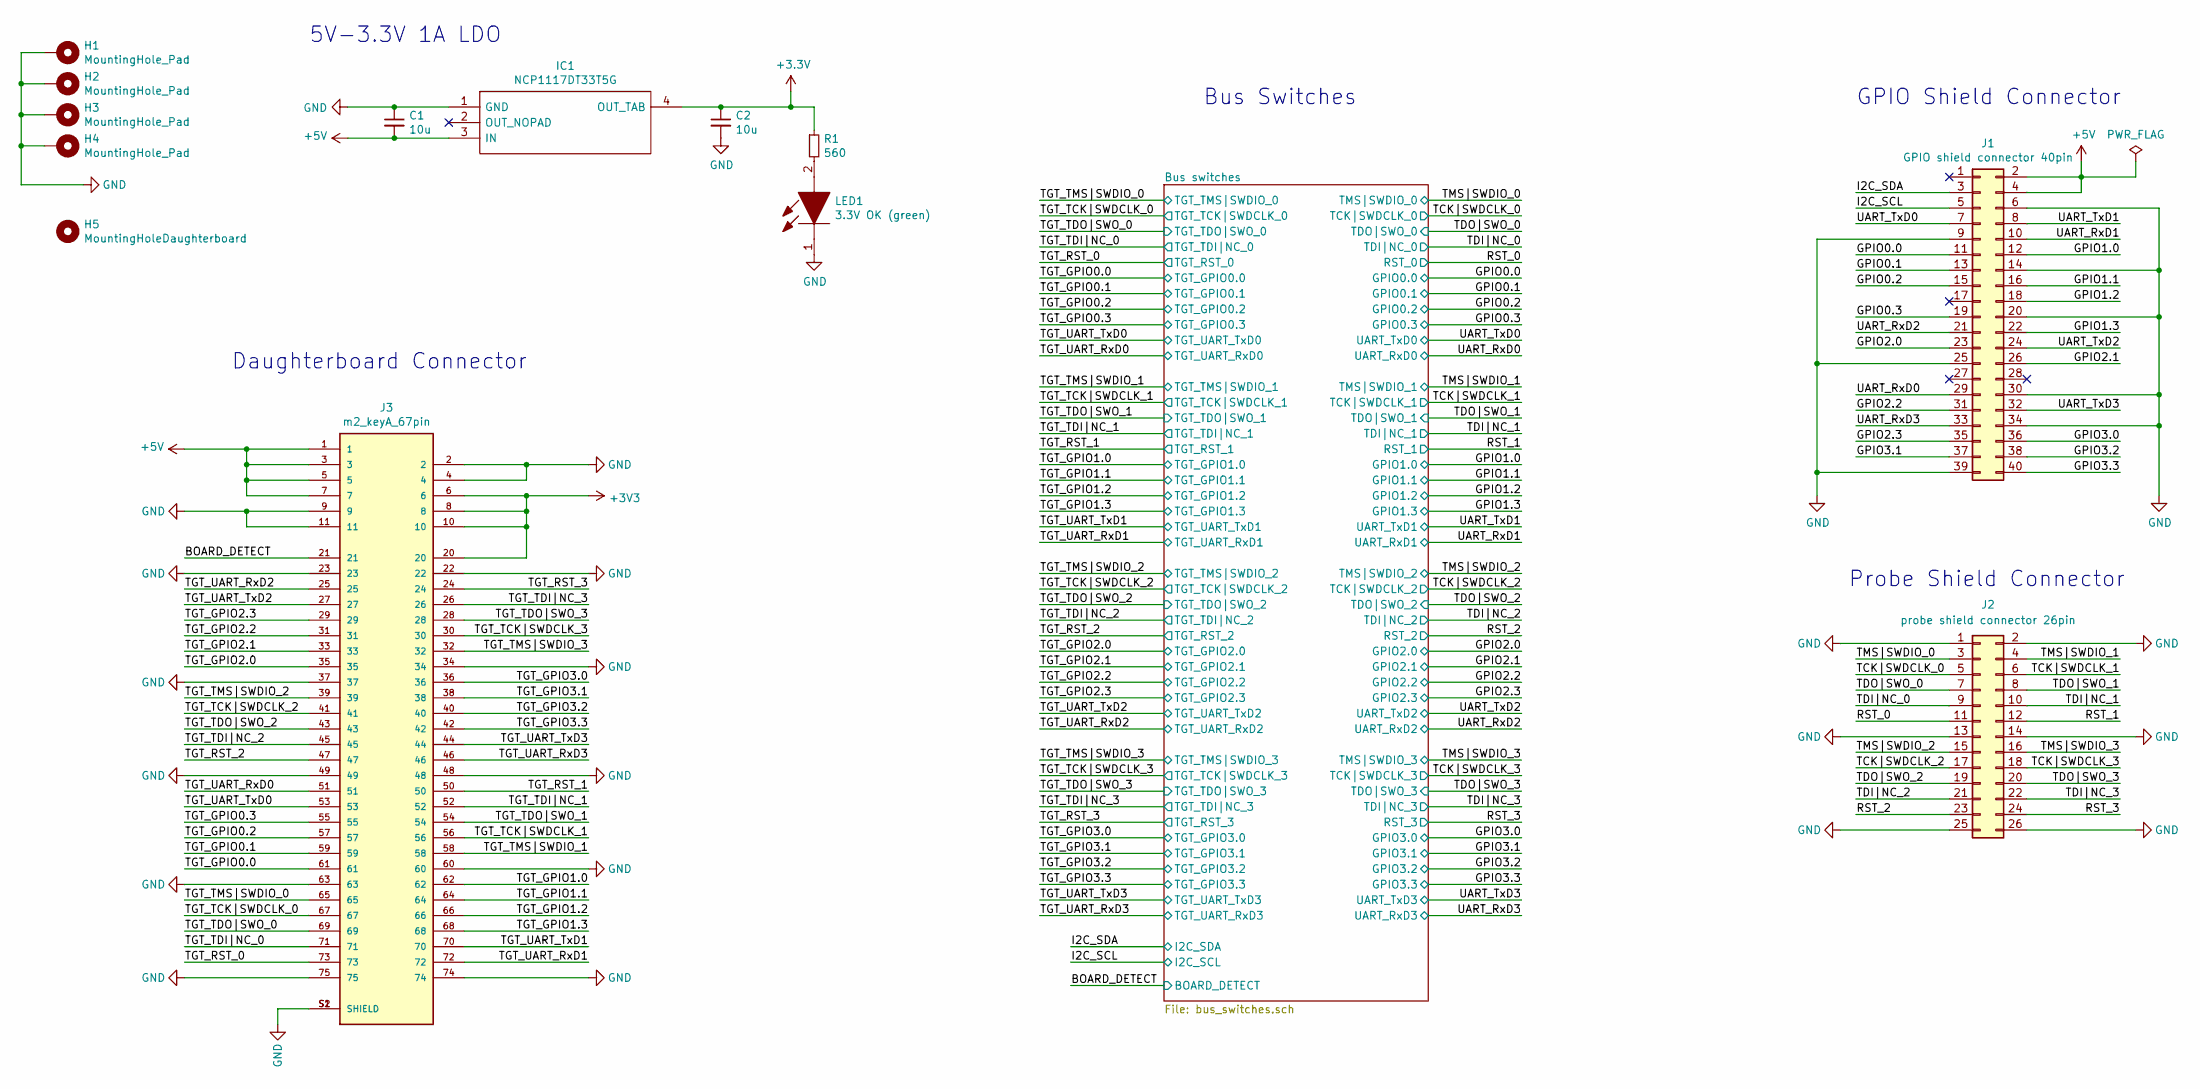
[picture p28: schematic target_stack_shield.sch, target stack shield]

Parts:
C1, C2: 10u; C_0805_2012Metric_Pad1.15x1.40mm_HandSolder; Manufacturer_Part_Number LMK212ABJ106MG-T; Digikey Price (CHF) 0.15
H1, H2, H3, H4: MountingHole_Pad; MountingHole_2.7mm_M2.5_DIN965_Pad
H5: MountingHoleDaughterboard; MountingHole_2.7mm_M2.5
IC1: NCP1117DT33T5G; TO229P990X238-4N; Mouser Part Number 863-NCP1117DT33T5G
J1: GPIO shield connector 40pin; PinHeader_2x20_P2.54mm_Vertical_gpio_shield; Manufacturer_Part_Number Adafruit 1979; Mouser Price (CHF) 2.77
J2: probe shield connector 26pin; PinHeader_2x13_P2.54mm_Vertical_probe_shield; Manufacturer_Part_Number Adafruit 1112; Digikey Price (CHF) 1.81
J3: m2_keyA_67pin; TE_2199230-3
LED1: 3.3V OK (green); LEDC1608X80N; Mouser Part Number 710-150060VS75000
R1: 560; R_0603_1608Metric_Pad1.05x0.95mm_HandSolder

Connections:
+5V: C1.2, IC1.3 (IN), J1.2, J1.4, J3.1, J3.3, J3.5, J3.7
/BOARD_DETECT: J3.21; also elsewhere on the board
/GPIO0.0: J1.11; also elsewhere on the board
/GPIO0.1: J1.13; also elsewhere on the board
/GPIO0.2: J1.15; also elsewhere on the board
/GPIO0.3: J1.19; also elsewhere on the board
/GPIO1.0: J1.12; also elsewhere on the board
/GPIO1.1: J1.16; also elsewhere on the board
/GPIO1.2: J1.18; also elsewhere on the board
/GPIO1.3: J1.22; also elsewhere on the board
/GPIO2.0: J1.23; also elsewhere on the board
/GPIO2.1: J1.26; also elsewhere on the board
/GPIO2.2: J1.31; also elsewhere on the board
/GPIO2.3: J1.35; also elsewhere on the board
/GPIO3.0: J1.36; also elsewhere on the board
/GPIO3.1: J1.37; also elsewhere on the board
/GPIO3.2: J1.38; also elsewhere on the board
/GPIO3.3: J1.40; also elsewhere on the board
/I2C_SCL: J1.5; also elsewhere on the board
/I2C_SDA: J1.3; also elsewhere on the board
/RST_0: J2.11; also elsewhere on the board
/RST_1: J2.12; also elsewhere on the board
/RST_2: J2.23; also elsewhere on the board
/RST_3: J2.24; also elsewhere on the board
/TCK|SWDCLK_0: J2.5; also elsewhere on the board
/TCK|SWDCLK_1: J2.6; also elsewhere on the board
/TCK|SWDCLK_2: J2.17; also elsewhere on the board
/TCK|SWDCLK_3: J2.18; also elsewhere on the board
/TDI|NC_0: J2.9; also elsewhere on the board
/TDI|NC_1: J2.10; also elsewhere on the board
/TDI|NC_2: J2.21; also elsewhere on the board
/TDI|NC_3: J2.22; also elsewhere on the board
/TDO|SWO_0: J2.7; also elsewhere on the board
/TDO|SWO_1: J2.8; also elsewhere on the board
/TDO|SWO_2: J2.19; also elsewhere on the board
/TDO|SWO_3: J2.20; also elsewhere on the board
/TGT_GPIO0.0: J3.61; also elsewhere on the board
/TGT_GPIO0.1: J3.59; also elsewhere on the board
/TGT_GPIO0.2: J3.57; also elsewhere on the board
/TGT_GPIO0.3: J3.55; also elsewhere on the board
/TGT_GPIO1.0: J3.62; also elsewhere on the board
/TGT_GPIO1.1: J3.64; also elsewhere on the board
/TGT_GPIO1.2: J3.66; also elsewhere on the board
/TGT_GPIO1.3: J3.68; also elsewhere on the board
/TGT_GPIO2.0: J3.35; also elsewhere on the board
/TGT_GPIO2.1: J3.33; also elsewhere on the board
/TGT_GPIO2.2: J3.31; also elsewhere on the board
/TGT_GPIO2.3: J3.29; also elsewhere on the board
/TGT_GPIO3.0: J3.36; also elsewhere on the board
/TGT_GPIO3.1: J3.38; also elsewhere on the board
/TGT_GPIO3.2: J3.40; also elsewhere on the board
/TGT_GPIO3.3: J3.42; also elsewhere on the board
/TGT_RST_0: J3.73; also elsewhere on the board
/TGT_RST_1: J3.50; also elsewhere on the board
/TGT_RST_2: J3.47; also elsewhere on the board
/TGT_RST_3: J3.24; also elsewhere on the board
/TGT_TCK|SWDCLK_0: J3.67; also elsewhere on the board
/TGT_TCK|SWDCLK_1: J3.56; also elsewhere on the board
/TGT_TCK|SWDCLK_2: J3.41; also elsewhere on the board
/TGT_TCK|SWDCLK_3: J3.30; also elsewhere on the board
/TGT_TDI|NC_0: J3.71; also elsewhere on the board
/TGT_TDI|NC_1: J3.52; also elsewhere on the board
/TGT_TDI|NC_2: J3.45; also elsewhere on the board
/TGT_TDI|NC_3: J3.26; also elsewhere on the board
/TGT_TDO|SWO_0: J3.69; also elsewhere on the board
/TGT_TDO|SWO_1: J3.54; also elsewhere on the board
/TGT_TDO|SWO_2: J3.43; also elsewhere on the board
/TGT_TDO|SWO_3: J3.28; also elsewhere on the board
/TGT_TMS|SWDIO_0: J3.65; also elsewhere on the board
/TGT_TMS|SWDIO_1: J3.58; also elsewhere on the board
/TGT_TMS|SWDIO_2: J3.39; also elsewhere on the board
/TGT_TMS|SWDIO_3: J3.32; also elsewhere on the board
/TGT_UART_RxD0: J3.51; also elsewhere on the board
/TGT_UART_RxD1: J3.72; also elsewhere on the board
/TGT_UART_RxD2: J3.25; also elsewhere on the board
/TGT_UART_RxD3: J3.46; also elsewhere on the board
/TGT_UART_TxD0: J3.53; also elsewhere on the board
/TGT_UART_TxD1: J3.70; also elsewhere on the board
/TGT_UART_TxD2: J3.27; also elsewhere on the board
/TGT_UART_TxD3: J3.44; also elsewhere on the board
/TMS|SWDIO_0: J2.3; also elsewhere on the board
/TMS|SWDIO_1: J2.4; also elsewhere on the board
/TMS|SWDIO_2: J2.15; also elsewhere on the board
/TMS|SWDIO_3: J2.16; also elsewhere on the board
/UART_RxD0: J1.29; also elsewhere on the board
/UART_RxD1: J1.10; also elsewhere on the board
/UART_RxD2: J1.21; also elsewhere on the board
/UART_RxD3: J1.33; also elsewhere on the board
/UART_TxD0: J1.7; also elsewhere on the board
/UART_TxD1: J1.8; also elsewhere on the board
/UART_TxD2: J1.24; also elsewhere on the board
/UART_TxD3: J1.32; also elsewhere on the board
GND: C1.1, C2.2, H1.1, H2.1, H3.1, H4.1, IC1.1 (GND), J1.6, J1.9, J1.14, J1.20, J1.25, J1.30, J1.34, J1.39, J2.1, J2.2, J2.13, J2.14, J2.25, J2.26, J3.2, J3.4, J3.9, J3.11, J3.22, J3.23, J3.34, J3.37, J3.48, J3.49, J3.60, J3.63, J3.74, J3.75, J3.S1 (SHIELD), J3.S2 (SHIELD), LED1.1; also elsewhere on the board
unnamed: LED1.2, R1.2

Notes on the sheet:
5V-3.3V 1A LDO
GPIO Shield Connector
Probe Shield Connector
Daughterboard Connector
Bus Switches

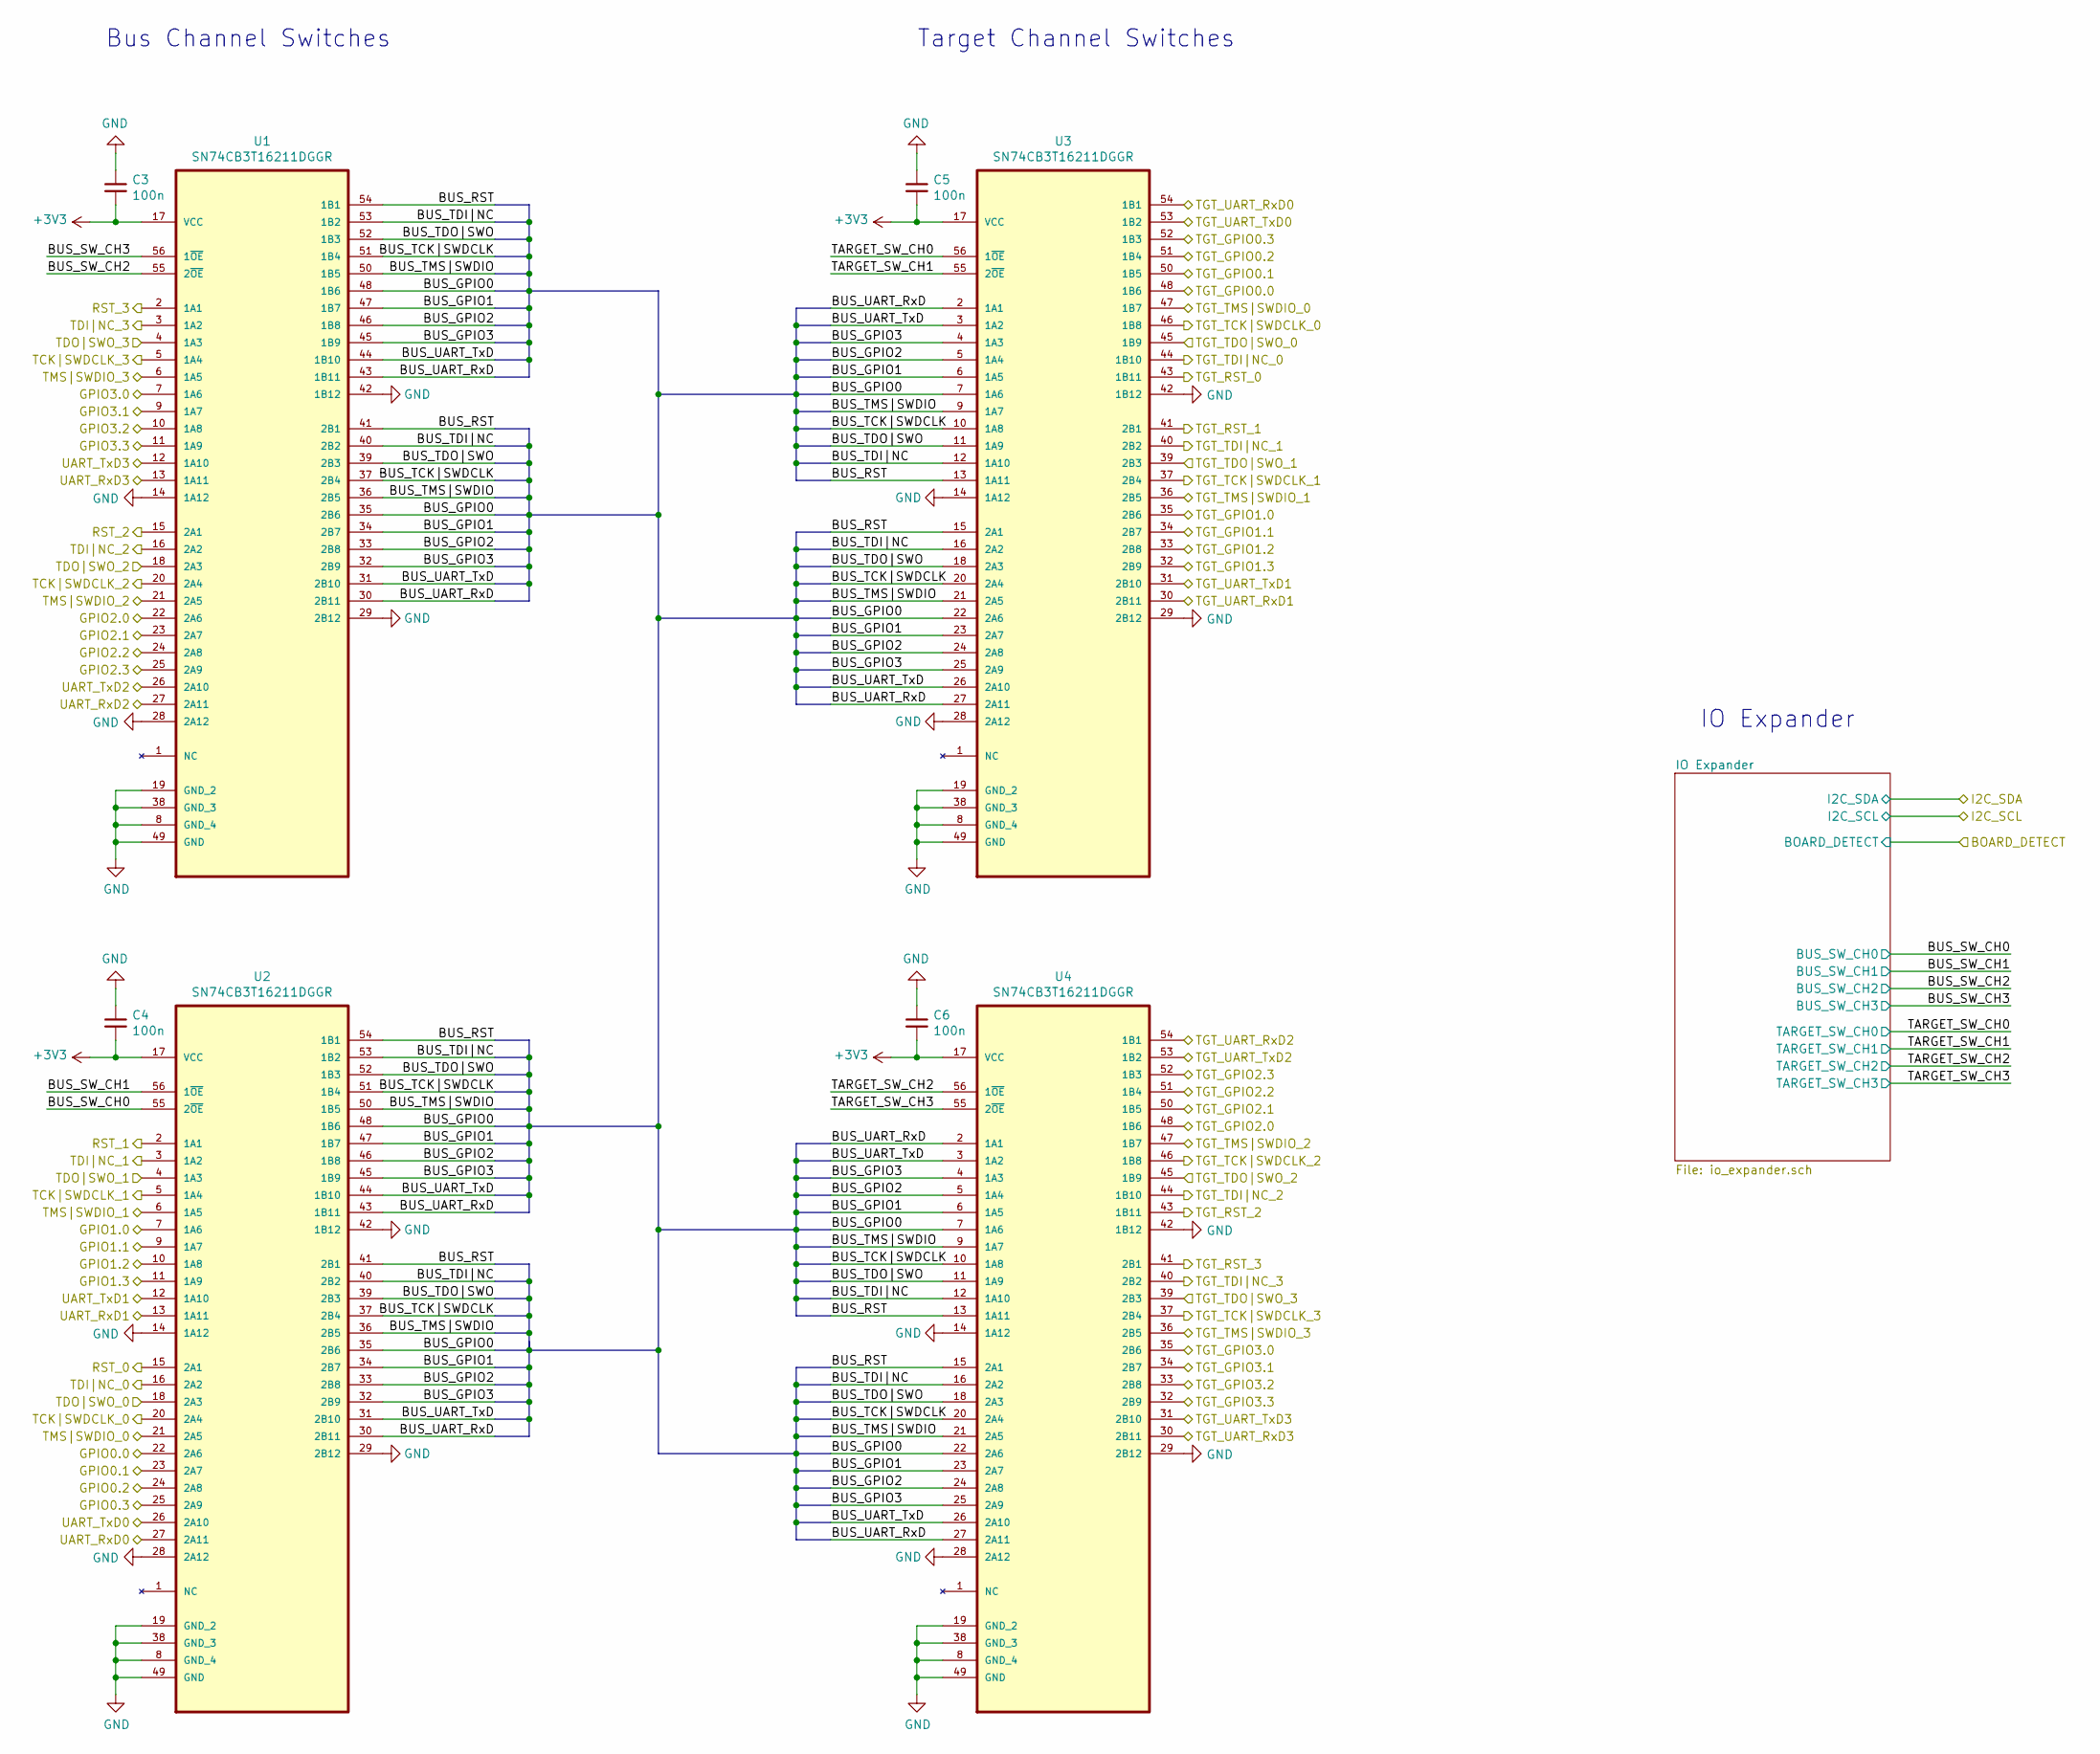
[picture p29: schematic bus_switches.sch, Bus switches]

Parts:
C3, C4, C5, C6: 100n; C_0603_1608Metric_Pad1.05x0.95mm_HandSolder
U1, U2, U3, U4: SN74CB3T16211DGGR; SOP50P810X120-56N; MPN SN74CB3T16211DGGR; Digikey Price (CHF) 2.64

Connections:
/Bus switches/BUS_GPIO0: U1.35 (2B6), U1.48 (1B6), U2.35 (2B6), U2.48 (1B6), U3.7 (1A6), U3.22 (2A6), U4.7 (1A6), U4.22 (2A6)
/Bus switches/BUS_GPIO1: U1.34 (2B7), U1.47 (1B7), U2.34 (2B7), U2.47 (1B7), U3.6 (1A5), U3.23 (2A7), U4.6 (1A5), U4.23 (2A7)
/Bus switches/BUS_GPIO2: U1.33 (2B8), U1.46 (1B8), U2.33 (2B8), U2.46 (1B8), U3.5 (1A4), U3.24 (2A8), U4.5 (1A4), U4.24 (2A8)
/Bus switches/BUS_GPIO3: U1.32 (2B9), U1.45 (1B9), U2.32 (2B9), U2.45 (1B9), U3.4 (1A3), U3.25 (2A9), U4.4 (1A3), U4.25 (2A9)
/Bus switches/BUS_RST: U1.41 (2B1), U1.54 (1B1), U2.41 (2B1), U2.54 (1B1), U3.13 (1A11), U3.15 (2A1), U4.13 (1A11), U4.15 (2A1)
/Bus switches/BUS_SW_CH0: U2.55 (2~OE); also elsewhere on the board
/Bus switches/BUS_SW_CH1: U2.56 (1~OE); also elsewhere on the board
/Bus switches/BUS_SW_CH2: U1.55 (2~OE); also elsewhere on the board
/Bus switches/BUS_SW_CH3: U1.56 (1~OE); also elsewhere on the board
/Bus switches/BUS_TCK|SWDCLK: U1.37 (2B4), U1.51 (1B4), U2.37 (2B4), U2.51 (1B4), U3.10 (1A8), U3.20 (2A4), U4.10 (1A8), U4.20 (2A4)
/Bus switches/BUS_TDI|NC: U1.40 (2B2), U1.53 (1B2), U2.40 (2B2), U2.53 (1B2), U3.12 (1A10), U3.16 (2A2), U4.12 (1A10), U4.16 (2A2)
/Bus switches/BUS_TDO|SWO: U1.39 (2B3), U1.52 (1B3), U2.39 (2B3), U2.52 (1B3), U3.11 (1A9), U3.18 (2A3), U4.11 (1A9), U4.18 (2A3)
/Bus switches/BUS_TMS|SWDIO: U1.36 (2B5), U1.50 (1B5), U2.36 (2B5), U2.50 (1B5), U3.9 (1A7), U3.21 (2A5), U4.9 (1A7), U4.21 (2A5)
/Bus switches/BUS_UART_RxD: U1.30 (2B11), U1.43 (1B11), U2.30 (2B11), U2.43 (1B11), U3.2 (1A1), U3.27 (2A11), U4.2 (1A1), U4.27 (2A11)
/Bus switches/BUS_UART_TxD: U1.31 (2B10), U1.44 (1B10), U2.31 (2B10), U2.44 (1B10), U3.3 (1A2), U3.26 (2A10), U4.3 (1A2), U4.26 (2A10)
/Bus switches/TARGET_SW_CH0: U3.56 (1~OE); also elsewhere on the board
/Bus switches/TARGET_SW_CH1: U3.55 (2~OE); also elsewhere on the board
/Bus switches/TARGET_SW_CH2: U4.56 (1~OE); also elsewhere on the board
/Bus switches/TARGET_SW_CH3: U4.55 (2~OE); also elsewhere on the board
/GPIO0.0: U2.22 (2A6); also elsewhere on the board
/GPIO0.1: U2.23 (2A7); also elsewhere on the board
/GPIO0.2: U2.24 (2A8); also elsewhere on the board
/GPIO0.3: U2.25 (2A9); also elsewhere on the board
/GPIO1.0: U2.7 (1A6); also elsewhere on the board
/GPIO1.1: U2.9 (1A7); also elsewhere on the board
/GPIO1.2: U2.10 (1A8); also elsewhere on the board
/GPIO1.3: U2.11 (1A9); also elsewhere on the board
/GPIO2.0: U1.22 (2A6); also elsewhere on the board
/GPIO2.1: U1.23 (2A7); also elsewhere on the board
/GPIO2.2: U1.24 (2A8); also elsewhere on the board
/GPIO2.3: U1.25 (2A9); also elsewhere on the board
/GPIO3.0: U1.7 (1A6); also elsewhere on the board
/GPIO3.1: U1.9 (1A7); also elsewhere on the board
/GPIO3.2: U1.10 (1A8); also elsewhere on the board
/GPIO3.3: U1.11 (1A9); also elsewhere on the board
/RST_0: U2.15 (2A1); also elsewhere on the board
/RST_1: U2.2 (1A1); also elsewhere on the board
/RST_2: U1.15 (2A1); also elsewhere on the board
/RST_3: U1.2 (1A1); also elsewhere on the board
/TCK|SWDCLK_0: U2.20 (2A4); also elsewhere on the board
/TCK|SWDCLK_1: U2.5 (1A4); also elsewhere on the board
/TCK|SWDCLK_2: U1.20 (2A4); also elsewhere on the board
/TCK|SWDCLK_3: U1.5 (1A4); also elsewhere on the board
/TDI|NC_0: U2.16 (2A2); also elsewhere on the board
/TDI|NC_1: U2.3 (1A2); also elsewhere on the board
/TDI|NC_2: U1.16 (2A2); also elsewhere on the board
/TDI|NC_3: U1.3 (1A2); also elsewhere on the board
/TDO|SWO_0: U2.18 (2A3); also elsewhere on the board
/TDO|SWO_1: U2.4 (1A3); also elsewhere on the board
/TDO|SWO_2: U1.18 (2A3); also elsewhere on the board
/TDO|SWO_3: U1.4 (1A3); also elsewhere on the board
/TGT_GPIO0.0: U3.48 (1B6); also elsewhere on the board
/TGT_GPIO0.1: U3.50 (1B5); also elsewhere on the board
/TGT_GPIO0.2: U3.51 (1B4); also elsewhere on the board
/TGT_GPIO0.3: U3.52 (1B3); also elsewhere on the board
/TGT_GPIO1.0: U3.35 (2B6); also elsewhere on the board
/TGT_GPIO1.1: U3.34 (2B7); also elsewhere on the board
/TGT_GPIO1.2: U3.33 (2B8); also elsewhere on the board
/TGT_GPIO1.3: U3.32 (2B9); also elsewhere on the board
/TGT_GPIO2.0: U4.48 (1B6); also elsewhere on the board
/TGT_GPIO2.1: U4.50 (1B5); also elsewhere on the board
/TGT_GPIO2.2: U4.51 (1B4); also elsewhere on the board
/TGT_GPIO2.3: U4.52 (1B3); also elsewhere on the board
/TGT_GPIO3.0: U4.35 (2B6); also elsewhere on the board
/TGT_GPIO3.1: U4.34 (2B7); also elsewhere on the board
/TGT_GPIO3.2: U4.33 (2B8); also elsewhere on the board
/TGT_GPIO3.3: U4.32 (2B9); also elsewhere on the board
/TGT_RST_0: U3.43 (1B11); also elsewhere on the board
/TGT_RST_1: U3.41 (2B1); also elsewhere on the board
/TGT_RST_2: U4.43 (1B11); also elsewhere on the board
/TGT_RST_3: U4.41 (2B1); also elsewhere on the board
/TGT_TCK|SWDCLK_0: U3.46 (1B8); also elsewhere on the board
/TGT_TCK|SWDCLK_1: U3.37 (2B4); also elsewhere on the board
/TGT_TCK|SWDCLK_2: U4.46 (1B8); also elsewhere on the board
/TGT_TCK|SWDCLK_3: U4.37 (2B4); also elsewhere on the board
/TGT_TDI|NC_0: U3.44 (1B10); also elsewhere on the board
/TGT_TDI|NC_1: U3.40 (2B2); also elsewhere on the board
/TGT_TDI|NC_2: U4.44 (1B10); also elsewhere on the board
/TGT_TDI|NC_3: U4.40 (2B2); also elsewhere on the board
/TGT_TDO|SWO_0: U3.45 (1B9); also elsewhere on the board
/TGT_TDO|SWO_1: U3.39 (2B3); also elsewhere on the board
/TGT_TDO|SWO_2: U4.45 (1B9); also elsewhere on the board
/TGT_TDO|SWO_3: U4.39 (2B3); also elsewhere on the board
/TGT_TMS|SWDIO_0: U3.47 (1B7); also elsewhere on the board
/TGT_TMS|SWDIO_1: U3.36 (2B5); also elsewhere on the board
/TGT_TMS|SWDIO_2: U4.47 (1B7); also elsewhere on the board
/TGT_TMS|SWDIO_3: U4.36 (2B5); also elsewhere on the board
/TGT_UART_RxD0: U3.54 (1B1); also elsewhere on the board
/TGT_UART_RxD1: U3.30 (2B11); also elsewhere on the board
/TGT_UART_RxD2: U4.54 (1B1); also elsewhere on the board
/TGT_UART_RxD3: U4.30 (2B11); also elsewhere on the board
/TGT_UART_TxD0: U3.53 (1B2); also elsewhere on the board
/TGT_UART_TxD1: U3.31 (2B10); also elsewhere on the board
/TGT_UART_TxD2: U4.53 (1B2); also elsewhere on the board
/TGT_UART_TxD3: U4.31 (2B10); also elsewhere on the board
/TMS|SWDIO_0: U2.21 (2A5); also elsewhere on the board
/TMS|SWDIO_1: U2.6 (1A5); also elsewhere on the board
/TMS|SWDIO_2: U1.21 (2A5); also elsewhere on the board
/TMS|SWDIO_3: U1.6 (1A5); also elsewhere on the board
/UART_RxD0: U2.27 (2A11); also elsewhere on the board
/UART_RxD1: U2.13 (1A11); also elsewhere on the board
/UART_RxD2: U1.27 (2A11); also elsewhere on the board
/UART_RxD3: U1.13 (1A11); also elsewhere on the board
/UART_TxD0: U2.26 (2A10); also elsewhere on the board
/UART_TxD1: U2.12 (1A10); also elsewhere on the board
/UART_TxD2: U1.26 (2A10); also elsewhere on the board
/UART_TxD3: U1.12 (1A10); also elsewhere on the board
GND: C3.1, C4.1, C5.1, C6.1, U1.8 (GND_4), U1.14 (1A12), U1.19 (GND_2), U1.28 (2A12), U1.29 (2B12), U1.38 (GND_3), U1.42 (1B12), U1.49 (GND), U2.8 (GND_4), U2.14 (1A12), U2.19 (GND_2), U2.28 (2A12), U2.29 (2B12), U2.38 (GND_3), U2.42 (1B12), U2.49 (GND), U3.8 (GND_4), U3.14 (1A12), U3.19 (GND_2), U3.28 (2A12), U3.29 (2B12), U3.38 (GND_3), U3.42 (1B12), U3.49 (GND), U4.8 (GND_4), U4.14 (1A12), U4.19 (GND_2), U4.28 (2A12), U4.29 (2B12), U4.38 (GND_3), U4.42 (1B12), U4.49 (GND); also elsewhere on the board

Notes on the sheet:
Bus Channel Switches
Target Channel Switches
IO Expander

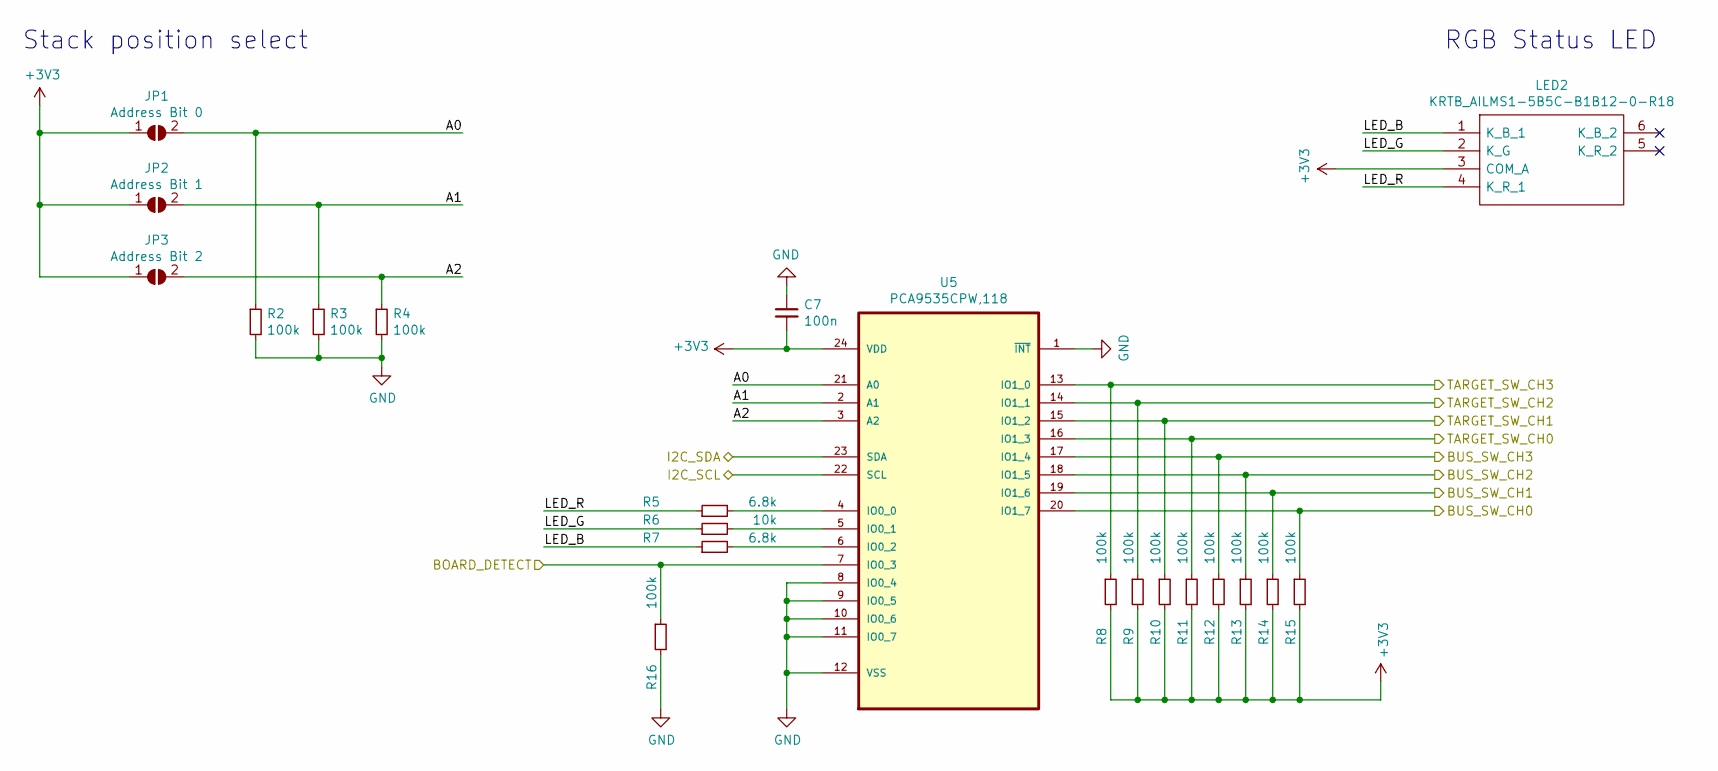
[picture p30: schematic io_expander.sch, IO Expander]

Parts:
C7: 100n; C_0603_1608Metric_Pad1.05x0.95mm_HandSolder
JP1: Address Bit 0; SolderJumper-2_P1.3mm_Open_TrianglePad1.0x1.5mm
JP2: Address Bit 1; SolderJumper-2_P1.3mm_Open_TrianglePad1.0x1.5mm
JP3: Address Bit 2; SolderJumper-2_P1.3mm_Open_TrianglePad1.0x1.5mm
LED2: KRTB_AILMS1-5B5C-B1B12-0-R18; KRTBAILMS15B5CB1B120R18; Mouser Part Number 720-KRTBAILMS1A2872
R2, R3, R4, R8, R9, R10, R11, R12, R13, R14, R15, R16: 100k; R_0603_1608Metric_Pad1.05x0.95mm_HandSolder
R5, R7: 6.8k; R_0603_1608Metric_Pad1.05x0.95mm_HandSolder
R6: 10k; R_0603_1608Metric_Pad1.05x0.95mm_HandSolder
U5: PCA9535CPW,118; SOP65P640X110-24N; MPN PCA9535CPW,118; Digikey Price (CHF) 1.9

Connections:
/BOARD_DETECT: R16.1, U5.7 (IO0_3); also elsewhere on the board
/Bus switches/BUS_SW_CH0: R15.1, U5.20 (IO1_7); also elsewhere on the board
/Bus switches/BUS_SW_CH1: R14.1, U5.19 (IO1_6); also elsewhere on the board
/Bus switches/BUS_SW_CH2: R13.1, U5.18 (IO1_5); also elsewhere on the board
/Bus switches/BUS_SW_CH3: R12.1, U5.17 (IO1_4); also elsewhere on the board
/Bus switches/IO Expander/A0: JP1.2 (B), R2.1, U5.21 (A0)
/Bus switches/IO Expander/A1: JP2.2 (B), R3.1, U5.2 (A1)
/Bus switches/IO Expander/A2: JP3.2 (B), R4.1, U5.3 (A2)
/Bus switches/IO Expander/LED_B: LED2.1 (K_B_1), R7.1
/Bus switches/IO Expander/LED_G: LED2.2 (K_G), R6.1
/Bus switches/IO Expander/LED_R: LED2.4 (K_R_1), R5.1
/Bus switches/TARGET_SW_CH0: R11.1, U5.16 (IO1_3); also elsewhere on the board
/Bus switches/TARGET_SW_CH1: R10.1, U5.15 (IO1_2); also elsewhere on the board
/Bus switches/TARGET_SW_CH2: R9.1, U5.14 (IO1_1); also elsewhere on the board
/Bus switches/TARGET_SW_CH3: R8.1, U5.13 (IO1_0); also elsewhere on the board
/I2C_SCL: U5.22 (SCL); also elsewhere on the board
/I2C_SDA: U5.23 (SDA); also elsewhere on the board
GND: C7.1, R2.2, R3.2, R4.2, R16.2, U5.1 (~INT), U5.8 (IO0_4), U5.9 (IO0_5), U5.10 (IO0_6), U5.11 (IO0_7), U5.12 (VSS); also elsewhere on the board
unnamed: R5.2, U5.4 (IO0_0)
unnamed: R6.2, U5.5 (IO0_1)
unnamed: R7.2, U5.6 (IO0_2)

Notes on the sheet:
Stack position select
RGB Status LED

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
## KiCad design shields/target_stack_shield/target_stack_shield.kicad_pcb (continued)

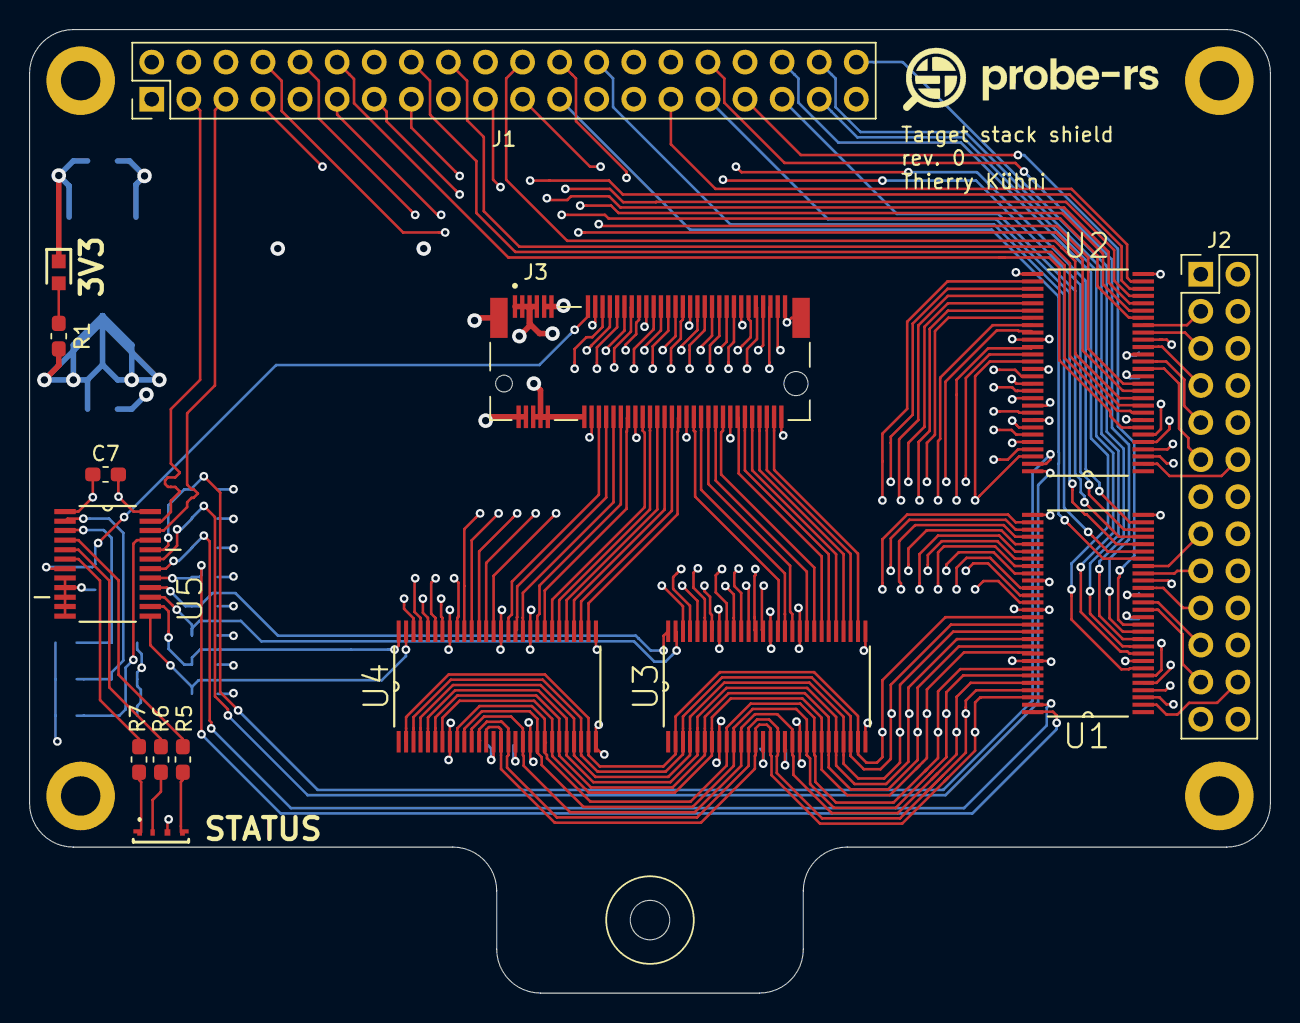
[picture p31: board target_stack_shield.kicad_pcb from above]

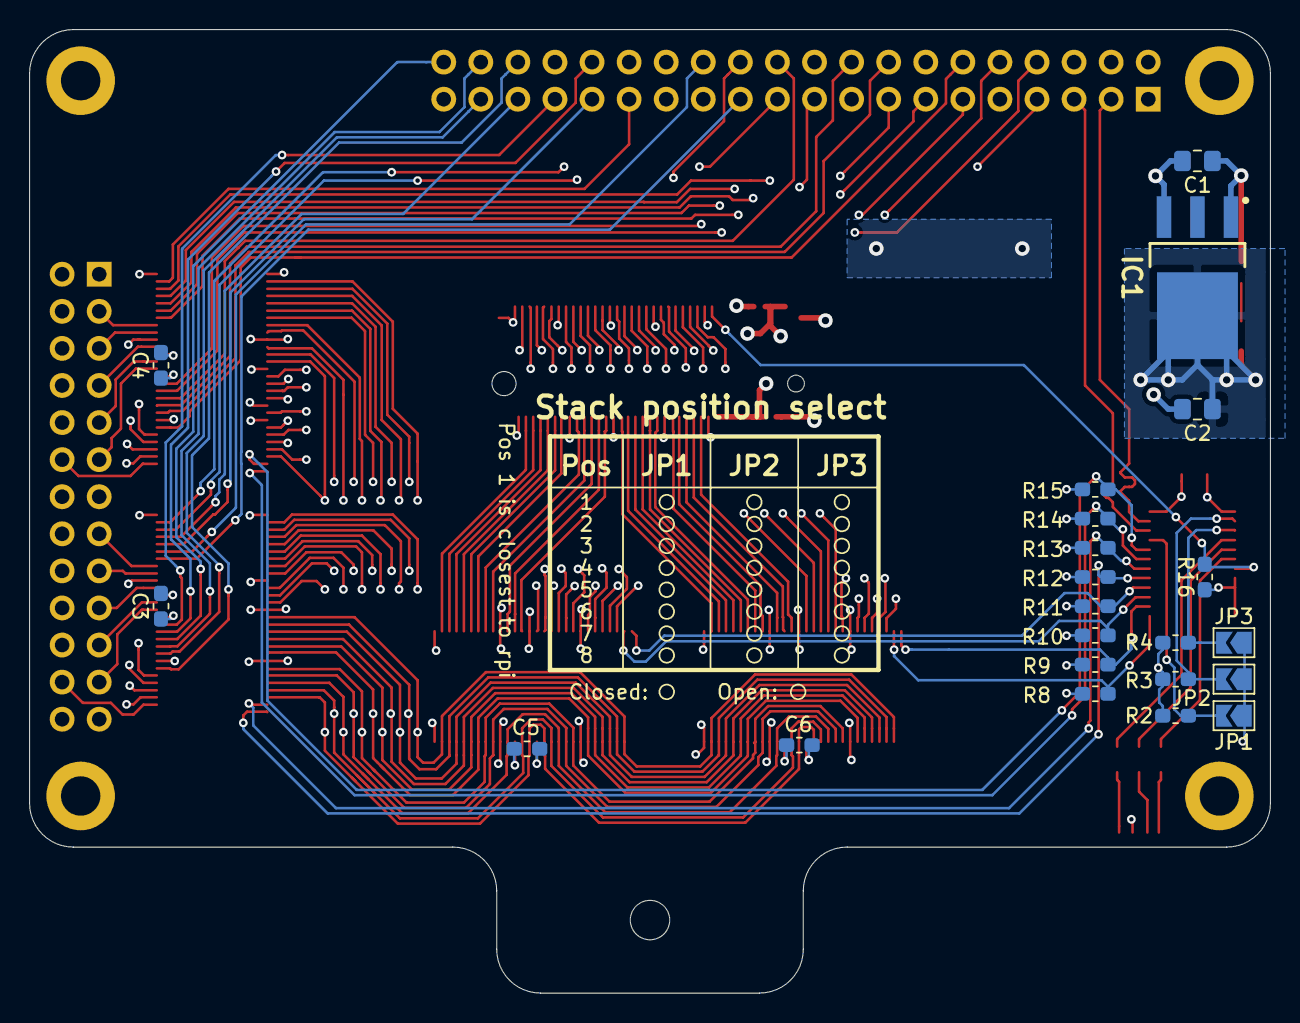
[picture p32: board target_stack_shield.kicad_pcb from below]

Board: 4 copper layers, 85.0 x 66.0 mm, 42 parts (22 on the bottom side), 123 nets.

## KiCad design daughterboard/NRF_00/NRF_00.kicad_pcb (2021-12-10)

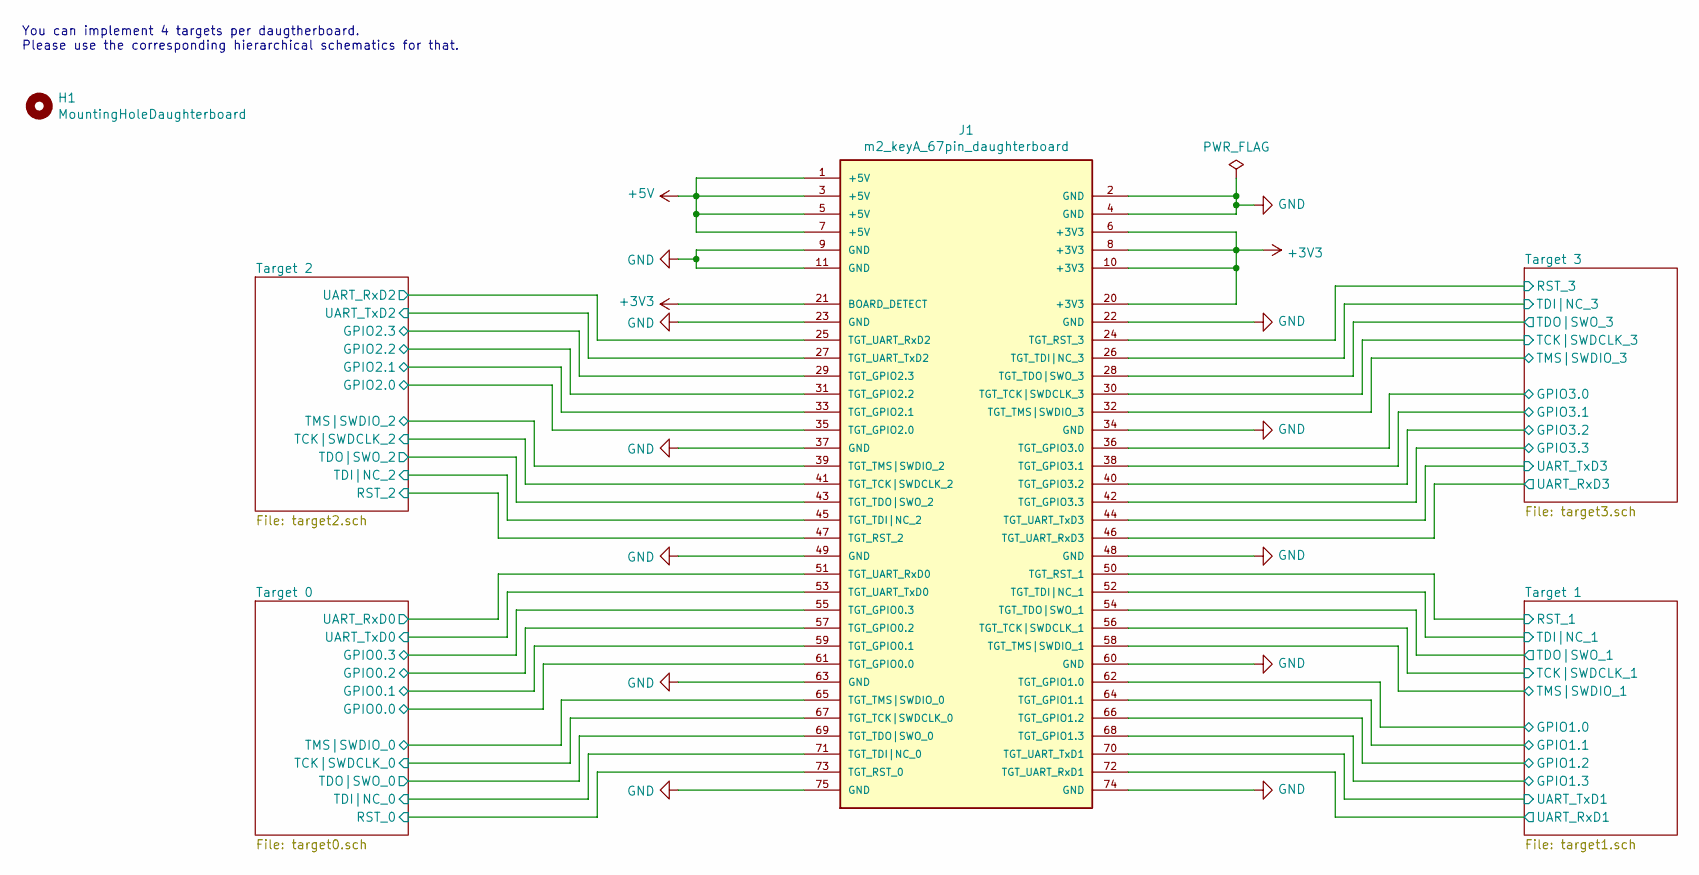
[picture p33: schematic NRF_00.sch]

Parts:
H1: MountingHoleDaughterboard; MountingHole_2.7mm_M2.5
J1: m2_keyA_67pin_daughterboard; m2_keyB

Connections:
+5V: J1.1 (+5V), J1.3 (+5V), J1.5 (+5V), J1.7 (+5V)
/Target 0/GPIO0.0: J1.61 (TGT_GPIO0.0); also elsewhere on the board
/Target 0/GPIO0.1: J1.59 (TGT_GPIO0.1); also elsewhere on the board
/Target 0/GPIO0.2: J1.57 (TGT_GPIO0.2); also elsewhere on the board
/Target 0/GPIO0.3: J1.55 (TGT_GPIO0.3); also elsewhere on the board
/Target 0/RST_0: J1.73 (TGT_RST_0); also elsewhere on the board
/Target 0/TCK|SWDCLK_0: J1.67 (TGT_TCK|SWDCLK_0); also elsewhere on the board
/Target 0/TDI|NC_0: J1.71 (TGT_TDI|NC_0); also elsewhere on the board
/Target 0/TDO|SWO_0: J1.69 (TGT_TDO|SWO_0); also elsewhere on the board
/Target 0/TMS|SWDIO_0: J1.65 (TGT_TMS|SWDIO_0); also elsewhere on the board
/Target 0/UART_RxD0: J1.51 (TGT_UART_RxD0); also elsewhere on the board
/Target 0/UART_TxD0: J1.53 (TGT_UART_TxD0); also elsewhere on the board
/Target 1/GPIO1.0: J1.62 (TGT_GPIO1.0); also elsewhere on the board
/Target 1/GPIO1.1: J1.64 (TGT_GPIO1.1); also elsewhere on the board
/Target 1/GPIO1.2: J1.66 (TGT_GPIO1.2); also elsewhere on the board
/Target 1/GPIO1.3: J1.68 (TGT_GPIO1.3); also elsewhere on the board
/Target 1/RST_1: J1.50 (TGT_RST_1); also elsewhere on the board
/Target 1/TCK|SWDCLK_1: J1.56 (TGT_TCK|SWDCLK_1); also elsewhere on the board
/Target 1/TDI|NC_1: J1.52 (TGT_TDI|NC_1); also elsewhere on the board
/Target 1/TDO|SWO_1: J1.54 (TGT_TDO|SWO_1); also elsewhere on the board
/Target 1/TMS|SWDIO_1: J1.58 (TGT_TMS|SWDIO_1); also elsewhere on the board
/Target 1/UART_RxD1: J1.72 (TGT_UART_RxD1); also elsewhere on the board
/Target 1/UART_TxD1: J1.70 (TGT_UART_TxD1); also elsewhere on the board
/Target 2/GPIO2.0: J1.35 (TGT_GPIO2.0); also elsewhere on the board
/Target 2/GPIO2.1: J1.33 (TGT_GPIO2.1); also elsewhere on the board
/Target 2/GPIO2.2: J1.31 (TGT_GPIO2.2); also elsewhere on the board
/Target 2/GPIO2.3: J1.29 (TGT_GPIO2.3); also elsewhere on the board
/Target 2/RST_2: J1.47 (TGT_RST_2); also elsewhere on the board
/Target 2/TCK|SWDCLK_2: J1.41 (TGT_TCK|SWDCLK_2); also elsewhere on the board
/Target 2/TDI|NC_2: J1.45 (TGT_TDI|NC_2); also elsewhere on the board
/Target 2/TDO|SWO_2: J1.43 (TGT_TDO|SWO_2); also elsewhere on the board
/Target 2/TMS|SWDIO_2: J1.39 (TGT_TMS|SWDIO_2); also elsewhere on the board
/Target 2/UART_RxD2: J1.25 (TGT_UART_RxD2); also elsewhere on the board
/Target 2/UART_TxD2: J1.27 (TGT_UART_TxD2); also elsewhere on the board
/Target 3/GPIO3.0: J1.36 (TGT_GPIO3.0); also elsewhere on the board
/Target 3/GPIO3.1: J1.38 (TGT_GPIO3.1); also elsewhere on the board
/Target 3/GPIO3.2: J1.40 (TGT_GPIO3.2); also elsewhere on the board
/Target 3/GPIO3.3: J1.42 (TGT_GPIO3.3); also elsewhere on the board
/Target 3/RST_3: J1.24 (TGT_RST_3); also elsewhere on the board
/Target 3/TCK|SWDCLK_3: J1.30 (TGT_TCK|SWDCLK_3); also elsewhere on the board
/Target 3/TDI|NC_3: J1.26 (TGT_TDI|NC_3); also elsewhere on the board
/Target 3/TDO|SWO_3: J1.28 (TGT_TDO|SWO_3); also elsewhere on the board
/Target 3/TMS|SWDIO_3: J1.32 (TGT_TMS|SWDIO_3); also elsewhere on the board
/Target 3/UART_RxD3: J1.46 (TGT_UART_RxD3); also elsewhere on the board
/Target 3/UART_TxD3: J1.44 (TGT_UART_TxD3); also elsewhere on the board
GND: J1.2 (GND), J1.4 (GND), J1.9 (GND), J1.11 (GND), J1.22 (GND), J1.23 (GND), J1.34 (GND), J1.37 (GND), J1.48 (GND), J1.49 (GND), J1.60 (GND), J1.63 (GND), J1.74 (GND), J1.75 (GND); also elsewhere on the board

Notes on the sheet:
You can implement 4 targets per daugtherboard. Please use the corresponding hierarchical schematics for that.

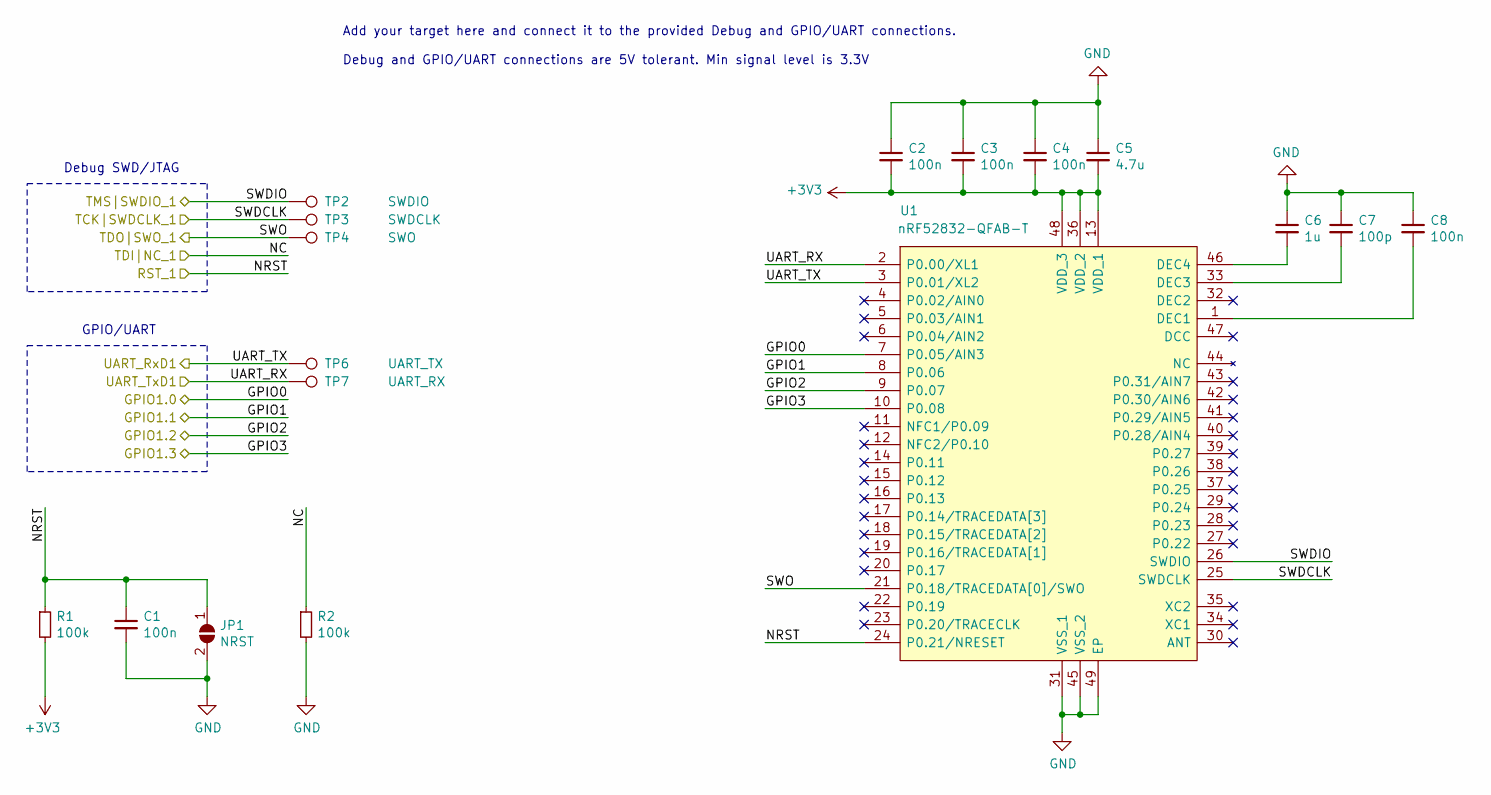
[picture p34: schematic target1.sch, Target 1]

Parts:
C1, C2, C3, C4, C8: 100n; C_0603_1608Metric_Pad1.05x0.95mm_HandSolder
C5: 4.7u; C_0603_1608Metric_Pad1.05x0.95mm_HandSolder
C6: 1u; C_0603_1608Metric_Pad1.05x0.95mm_HandSolder
C7: 100p; C_0603_1608Metric_Pad1.05x0.95mm_HandSolder
JP1: NRST; SolderJumper-2_P1.3mm_Open_TrianglePad1.0x1.5mm
R1, R2: 100k; R_0603_1608Metric_Pad1.05x0.95mm_HandSolder
TP2: SWDIO; TestPoint_Pad_1.0x1.0mm
TP3: SWDCLK; TestPoint_Pad_1.0x1.0mm
TP4: SWO; TestPoint_Pad_1.0x1.0mm
TP6: UART_TX; TestPoint_Pad_1.0x1.0mm
TP7: UART_RX; TestPoint_Pad_1.0x1.0mm
U1: nRF52832-QFAB-T; Mouser Part Number 949-NRF52832-QFAB-T

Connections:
/Target 1/GPIO1.0: U1.7 (P0.05/AIN3); also elsewhere on the board
/Target 1/GPIO1.1: U1.8 (P0.06); also elsewhere on the board
/Target 1/GPIO1.2: U1.9 (P0.07); also elsewhere on the board
/Target 1/GPIO1.3: U1.10 (P0.08); also elsewhere on the board
/Target 1/RST_1: C1.1, JP1.1 (A), R1.1, U1.24 (P0.21/NRESET); also elsewhere on the board
/Target 1/TCK|SWDCLK_1: TP3.1, U1.25 (SWDCLK); also elsewhere on the board
/Target 1/TDI|NC_1: R2.1; also elsewhere on the board
/Target 1/TDO|SWO_1: TP4.1, U1.21 (P0.18/TRACEDATA[0]/SWO); also elsewhere on the board
/Target 1/TMS|SWDIO_1: TP2.1, U1.26 (SWDIO); also elsewhere on the board
/Target 1/UART_RxD1: TP6.1, U1.3 (P0.01/XL2); also elsewhere on the board
/Target 1/UART_TxD1: TP7.1, U1.2 (P0.00/XL1); also elsewhere on the board
GND: C1.2, C2.1, C3.1, C4.1, C5.1, C6.1, C7.1, C8.1, JP1.2 (B), R2.2, U1.31 (VSS_1), U1.45 (VSS_2), U1.49 (EP); also elsewhere on the board
unnamed: C6.2, U1.46 (DEC4)
unnamed: C7.2, U1.33 (DEC3)
unnamed: C8.2, U1.1 (DEC1)

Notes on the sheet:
Debug SWD/JTAG
GPIO/UART
Add your target here and connect it to the provided Debug and GPIO/UART connections. Debug and GPIO/UART connections are 5V tolerant. Min signal level is 3.3V

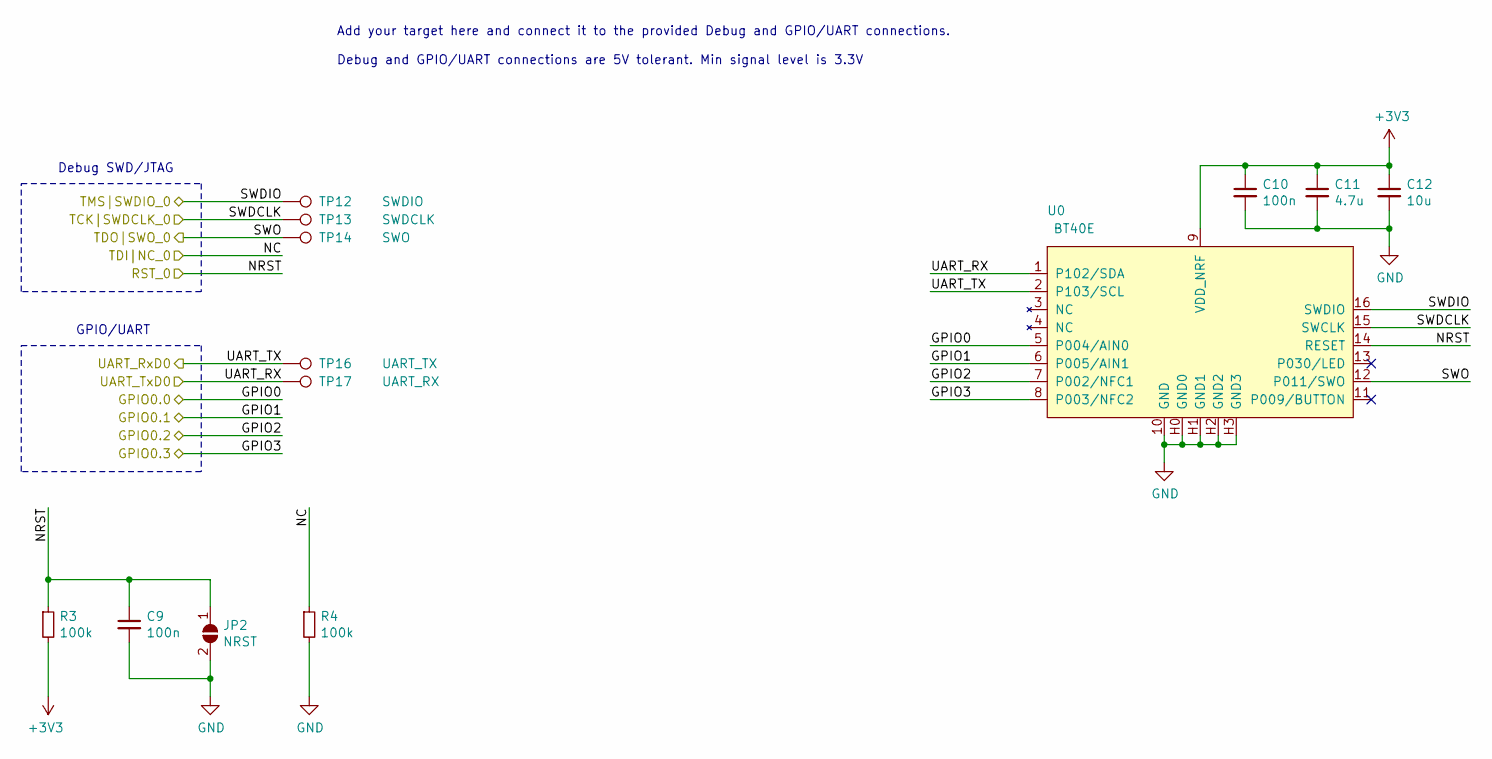
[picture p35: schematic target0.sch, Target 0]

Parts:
C9, C10: 100n; C_0603_1608Metric_Pad1.05x0.95mm_HandSolder
C11: 4.7u; C_0603_1608Metric_Pad1.05x0.95mm_HandSolder
C12: 10u; C_0603_1608Metric_Pad1.05x0.95mm_HandSolder
JP2: NRST; SolderJumper-2_P1.3mm_Open_TrianglePad1.0x1.5mm
R3, R4: 100k; R_0603_1608Metric_Pad1.05x0.95mm_HandSolder
TP12: SWDIO; TestPoint_Pad_1.0x1.0mm
TP13: SWDCLK; TestPoint_Pad_1.0x1.0mm
TP14: SWO; TestPoint_Pad_1.0x1.0mm
TP16: UART_TX; TestPoint_Pad_1.0x1.0mm
TP17: UART_RX; TestPoint_Pad_1.0x1.0mm
U0: BT40E

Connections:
/Target 0/GPIO0.0: U0.5 (P004/AIN0); also elsewhere on the board
/Target 0/GPIO0.1: U0.6 (P005/AIN1); also elsewhere on the board
/Target 0/GPIO0.2: U0.7 (P002/NFC1); also elsewhere on the board
/Target 0/GPIO0.3: U0.8 (P003/NFC2); also elsewhere on the board
/Target 0/RST_0: C9.1, JP2.1 (A), R3.1, U0.14 (RESET); also elsewhere on the board
/Target 0/TCK|SWDCLK_0: TP13.1, U0.15 (SWCLK); also elsewhere on the board
/Target 0/TDI|NC_0: R4.1; also elsewhere on the board
/Target 0/TDO|SWO_0: TP14.1, U0.12 (P011/SWO); also elsewhere on the board
/Target 0/TMS|SWDIO_0: TP12.1, U0.16 (SWDIO); also elsewhere on the board
/Target 0/UART_RxD0: TP16.1, U0.2 (P103/SCL); also elsewhere on the board
/Target 0/UART_TxD0: TP17.1, U0.1 (P102/SDA); also elsewhere on the board
GND: C9.2, C10.2, C11.2, C12.2, JP2.2 (B), R4.2, U0.10 (GND), U0.H0 (GND0), U0.H1 (GND1), U0.H2 (GND2), U0.H3 (GND3); also elsewhere on the board

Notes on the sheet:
Debug SWD/JTAG
GPIO/UART
Add your target here and connect it to the provided Debug and GPIO/UART connections. Debug and GPIO/UART connections are 5V tolerant. Min signal level is 3.3V

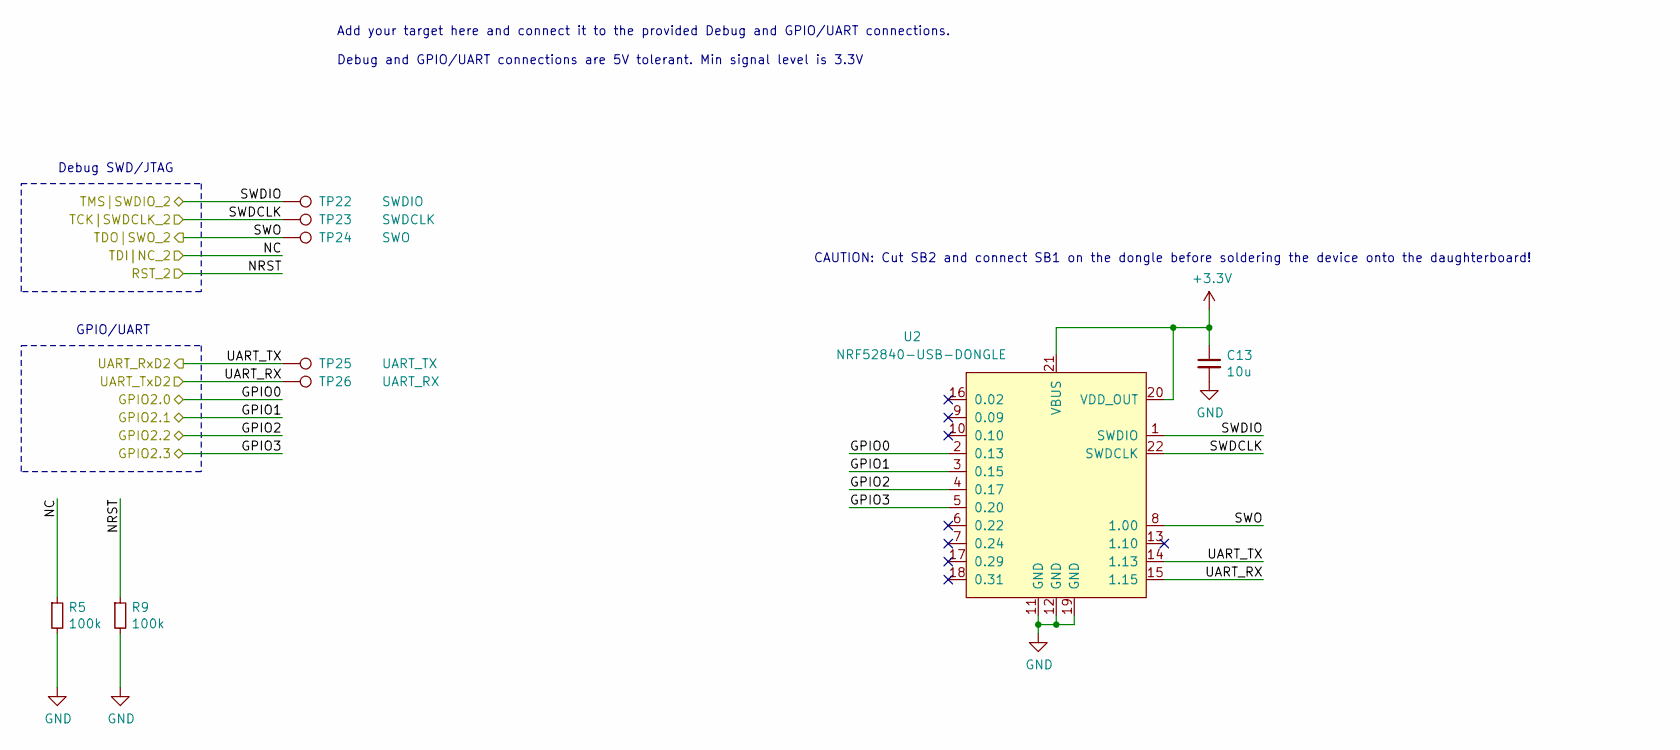
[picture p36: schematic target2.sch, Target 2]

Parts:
C13: 10u; C_0603_1608Metric_Pad1.05x0.95mm_HandSolder
R5, R9: 100k; R_0603_1608Metric_Pad1.05x0.95mm_HandSolder
TP22: SWDIO; TestPoint_Pad_1.0x1.0mm
TP23: SWDCLK; TestPoint_Pad_1.0x1.0mm
TP24: SWO; TestPoint_Pad_1.0x1.0mm
TP25: UART_TX; TestPoint_Pad_1.0x1.0mm
TP26: UART_RX; TestPoint_Pad_1.0x1.0mm
U2: NRF52840-USB-DONGLE

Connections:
/Target 2/GPIO2.0: U2.2 (0.13); also elsewhere on the board
/Target 2/GPIO2.1: U2.3 (0.15); also elsewhere on the board
/Target 2/GPIO2.2: U2.4 (0.17); also elsewhere on the board
/Target 2/GPIO2.3: U2.5 (0.20); also elsewhere on the board
/Target 2/RST_2: R9.1; also elsewhere on the board
/Target 2/TCK|SWDCLK_2: TP23.1, U2.22 (SWDCLK); also elsewhere on the board
/Target 2/TDI|NC_2: R5.1; also elsewhere on the board
/Target 2/TDO|SWO_2: TP24.1, U2.8 (1.00); also elsewhere on the board
/Target 2/TMS|SWDIO_2: TP22.1, U2.1 (SWDIO); also elsewhere on the board
/Target 2/UART_RxD2: TP25.1, U2.14 (1.13); also elsewhere on the board
/Target 2/UART_TxD2: TP26.1, U2.15 (1.15); also elsewhere on the board
GND: C13.2, R5.2, R9.2, U2.11 (GND), U2.12 (GND), U2.19 (GND); also elsewhere on the board

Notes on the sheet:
Debug SWD/JTAG
GPIO/UART
Add your target here and connect it to the provided Debug and GPIO/UART connections. Debug and GPIO/UART connections are 5V tolerant. Min signal level is 3.3V
CAUTION: Cut SB2 and connect SB1 on the dongle before soldering the device onto the daughterboard!


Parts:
C14, C15, C16, C17, C18, C19: 100n; C_0603_1608Metric_Pad1.05x0.95mm_HandSolder
C20: 4.7u; C_0603_1608Metric_Pad1.05x0.95mm_HandSolder
JP3: NRST_DEBUG; SolderJumper-3_P2.0mm_Open_TrianglePad1.0x1.5mm_NumberLabels
R6: 1k; R_0603_1608Metric_Pad1.05x0.95mm_HandSolder
R7, R8: 100k; R_0603_1608Metric_Pad1.05x0.95mm_HandSolder
TP32: SWDCLK; TestPoint_Pad_1.0x1.0mm
TP35: UART_TX; TestPoint_Pad_1.0x1.0mm
TP36: UART_RX; TestPoint_Pad_1.0x1.0mm
U3: NRF51822-QFAC-R7

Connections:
/Target 3/GPIO3.0: U3.19 (P0.13); also elsewhere on the board
/Target 3/GPIO3.1: U3.20 (P0.14); also elsewhere on the board
/Target 3/GPIO3.2: U3.21 (P0.15); also elsewhere on the board
/Target 3/GPIO3.3: U3.22 (P0.16); also elsewhere on the board
/Target 3/RST_3: JP3.1 (A); also elsewhere on the board
/Target 3/TCK|SWDCLK_3: R6.1, TP32.1, U3.24 (SWDCLK); also elsewhere on the board
/Target 3/TDI|NC_3: R7.1; also elsewhere on the board
/Target 3/TDO|SWO_3: R8.1; also elsewhere on the board
/Target 3/TMS|SWDIO_3: JP3.2 (C), U3.23 (SWDIO/~RESET); also elsewhere on the board
/Target 3/UART_RxD3: TP35.1, U3.10 (P0.06); also elsewhere on the board
/Target 3/UART_TxD3: TP36.1, U3.9 (P0.05); also elsewhere on the board
GND: C14.2, C15.1, C16.1, C17.2, C18.2, C19.2, C20.2, JP3.3 (B), R6.2, R7.2, R8.2, U3.13 (VSS1), U3.33 (VSS2), U3.34 (VSS3), U3.49 (EXP); also elsewhere on the board
unnamed: C15.2, U3.39 (DEC1)
unnamed: C16.2, U3.29 (DEC2)

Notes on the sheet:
Debug SWD/JTAG
GPIO/UART
Add your target here and connect it to the provided Debug and GPIO/UART connections. Debug and GPIO/UART connections are 5V tolerant. Min signal level is 3.3V

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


Board: 4 copper layers, 67.0 x 54.0 mm, 56 parts (32 on the bottom side), 52 nets.

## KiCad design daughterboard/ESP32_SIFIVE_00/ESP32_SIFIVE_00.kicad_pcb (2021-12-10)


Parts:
H1: MountingHoleDaughterboard; MountingHole_2.7mm_M2.5
J1: m2_keyA_67pin_daughterboard; m2_keyB

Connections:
+3V3: J1.6 (+3V3), J1.8 (+3V3), J1.10 (+3V3), J1.20 (+3V3), J1.21 (BOARD_DETECT); also elsewhere on the board
+5V: J1.1 (+5V), J1.3 (+5V), J1.5 (+5V), J1.7 (+5V); also elsewhere on the board
/Target 0/GPIO0.0: J1.61 (TGT_GPIO0.0); also elsewhere on the board
/Target 0/GPIO0.1: J1.59 (TGT_GPIO0.1); also elsewhere on the board
/Target 0/GPIO0.2: J1.57 (TGT_GPIO0.2); also elsewhere on the board
/Target 0/GPIO0.3: J1.55 (TGT_GPIO0.3); also elsewhere on the board
/Target 0/RST_0: J1.73 (TGT_RST_0); also elsewhere on the board
/Target 0/TCK|SWDCLK_0: J1.67 (TGT_TCK|SWDCLK_0); also elsewhere on the board
/Target 0/TDI|NC_0: J1.71 (TGT_TDI|NC_0); also elsewhere on the board
/Target 0/TDO|SWO_0: J1.69 (TGT_TDO|SWO_0); also elsewhere on the board
/Target 0/TMS|SWDIO_0: J1.65 (TGT_TMS|SWDIO_0); also elsewhere on the board
/Target 0/UART_RxD0: J1.51 (TGT_UART_RxD0); also elsewhere on the board
/Target 0/UART_TxD0: J1.53 (TGT_UART_TxD0); also elsewhere on the board
/Target 1/GPIO1.0: J1.62 (TGT_GPIO1.0); also elsewhere on the board
/Target 1/GPIO1.1: J1.64 (TGT_GPIO1.1); also elsewhere on the board
/Target 1/GPIO1.2: J1.66 (TGT_GPIO1.2); also elsewhere on the board
/Target 1/GPIO1.3: J1.68 (TGT_GPIO1.3); also elsewhere on the board
/Target 1/RST_1: J1.50 (TGT_RST_1); also elsewhere on the board
/Target 1/TCK|SWDCLK_1: J1.56 (TGT_TCK|SWDCLK_1); also elsewhere on the board
/Target 1/TDI|NC_1: J1.52 (TGT_TDI|NC_1); also elsewhere on the board
/Target 1/TDO|SWO_1: J1.54 (TGT_TDO|SWO_1); also elsewhere on the board
/Target 1/TMS|SWDIO_1: J1.58 (TGT_TMS|SWDIO_1); also elsewhere on the board
/Target 1/UART_RxD1: J1.72 (TGT_UART_RxD1); also elsewhere on the board
/Target 1/UART_TxD1: J1.70 (TGT_UART_TxD1); also elsewhere on the board
/Target 2/GPIO2.0: J1.35 (TGT_GPIO2.0); also elsewhere on the board
/Target 2/GPIO2.1: J1.33 (TGT_GPIO2.1); also elsewhere on the board
/Target 2/GPIO2.2: J1.31 (TGT_GPIO2.2); also elsewhere on the board
/Target 2/GPIO2.3: J1.29 (TGT_GPIO2.3); also elsewhere on the board
/Target 2/RST_2: J1.47 (TGT_RST_2); also elsewhere on the board
/Target 2/TCK|SWDCLK_2: J1.41 (TGT_TCK|SWDCLK_2); also elsewhere on the board
/Target 2/TDI|NC_2: J1.45 (TGT_TDI|NC_2); also elsewhere on the board
/Target 2/TDO|SWO_2: J1.43 (TGT_TDO|SWO_2); also elsewhere on the board
/Target 2/TMS|SWDIO_2: J1.39 (TGT_TMS|SWDIO_2); also elsewhere on the board
/Target 2/UART_RxD2: J1.25 (TGT_UART_RxD2); also elsewhere on the board
/Target 2/UART_TxD2: J1.27 (TGT_UART_TxD2); also elsewhere on the board
/Target 3/GPIO3.0: J1.36 (TGT_GPIO3.0); also elsewhere on the board
/Target 3/GPIO3.1: J1.38 (TGT_GPIO3.1); also elsewhere on the board
/Target 3/GPIO3.2: J1.40 (TGT_GPIO3.2); also elsewhere on the board
/Target 3/GPIO3.3: J1.42 (TGT_GPIO3.3); also elsewhere on the board
/Target 3/RST_3: J1.24 (TGT_RST_3); also elsewhere on the board
/Target 3/TCK|SWDCLK_3: J1.30 (TGT_TCK|SWDCLK_3); also elsewhere on the board
/Target 3/TDI|NC_3: J1.26 (TGT_TDI|NC_3); also elsewhere on the board
/Target 3/TDO|SWO_3: J1.28 (TGT_TDO|SWO_3); also elsewhere on the board
/Target 3/TMS|SWDIO_3: J1.32 (TGT_TMS|SWDIO_3); also elsewhere on the board
/Target 3/UART_RxD3: J1.46 (TGT_UART_RxD3); also elsewhere on the board
/Target 3/UART_TxD3: J1.44 (TGT_UART_TxD3); also elsewhere on the board
GND: J1.2 (GND), J1.4 (GND), J1.9 (GND), J1.11 (GND), J1.22 (GND), J1.23 (GND), J1.34 (GND), J1.37 (GND), J1.48 (GND), J1.49 (GND), J1.60 (GND), J1.63 (GND), J1.74 (GND), J1.75 (GND); also elsewhere on the board

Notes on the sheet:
You can implement 4 targets per daugtherboard. Please use the corresponding hierarchical schematics for that.

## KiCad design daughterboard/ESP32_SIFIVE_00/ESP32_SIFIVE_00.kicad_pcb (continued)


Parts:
C1, C3, C6, C7, C8, C9, C10, C11, C12: 100n; C_0603_1608Metric_Pad1.05x0.95mm_HandSolder
C2, C5: 1u; C_0603_1608Metric_Pad1.05x0.95mm_HandSolder
C4: 10u; C_0603_1608Metric_Pad1.05x0.95mm_HandSolder
IC1: W25X40CLSNIG; Mouser Part Number 454-W25X40CLSNIG
JP1: BOOT; SolderJumper-2_P1.3mm_Open_TrianglePad1.0x1.5mm
JP2: NRST; SolderJumper-2_P1.3mm_Open_TrianglePad1.0x1.5mm
R1, R5, R6, R7: 100k; R_0603_1608Metric_Pad1.05x0.95mm_HandSolder
R2, R3, R4: 10k; R_0603_1608Metric_Pad1.05x0.95mm_HandSolder
TP1: TMS; TestPoint_Pad_1.0x1.0mm
TP2: TCK; TestPoint_Pad_1.0x1.0mm
TP3: TDO; TestPoint_Pad_1.0x1.0mm
TP4: TDI; TestPoint_Pad_1.0x1.0mm
TP6: UART_TX; TestPoint_Pad_1.0x1.0mm
TP7: UART_RX; TestPoint_Pad_1.0x1.0mm
U1: ESP32-S2; MANUFACTURER_PART_NUMBE ESP32-S2

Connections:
+3V3: C4.1, C5.1, C6.1, C7.1, C8.1, C9.1, C10.1, C11.1, C12.1, R1.2, R2.2, R5.1, U1.1 (VDDA@0), U1.3 (VDD3P3@0), U1.4 (VDD3P3@1), U1.20 (VDD3P3_RTC), U1.27 (VDD3P3_RTC_IO), U1.45 (VDD3P3_CPU), U1.51 (VDDA@1), U1.54 (VDDA@2); also elsewhere on the board
/Target 1/BOOT: JP1.2 (B), R5.2, U1.5 (IO0)
/Target 1/CLK: IC1.6 (CLK), U1.34 (SPICLK)
/Target 1/CS: IC1.1 (/CS), R4.1, U1.33 (SPICS0)
/Target 1/DI: IC1.5 (DI(IO0)), U1.36 (SPID)
/Target 1/DO: IC1.2 (DO(IO1)), U1.35 (SPIQ)
/Target 1/GPIO1.0: U1.15 (IO10); also elsewhere on the board
/Target 1/GPIO1.1: U1.16 (IO11); also elsewhere on the board
/Target 1/GPIO1.2: U1.17 (IO12); also elsewhere on the board
/Target 1/GPIO1.3: U1.18 (IO13); also elsewhere on the board
/Target 1/HOLD: IC1.7 (/HOLD), U1.31 (SPIHD)
/Target 1/RST_1: C1.1, JP2.1 (A), R1.1, U1.56 (CHIP_PU); also elsewhere on the board
/Target 1/TCK|SWDCLK_1: R3.1, TP2.1, U1.43 (MTCK); also elsewhere on the board
/Target 1/TDI|NC_1: TP4.1, U1.46 (MTDI); also elsewhere on the board
/Target 1/TDO|SWO_1: TP3.1, U1.44 (MTD0); also elsewhere on the board
/Target 1/TMS|SWDIO_1: R2.1, TP1.1, U1.47 (MTMS); also elsewhere on the board
/Target 1/UART_RxD1: TP6.1, U1.48 (U0TXD); also elsewhere on the board
/Target 1/UART_TxD1: TP7.1, U1.49 (U0RXD); also elsewhere on the board
/Target 1/VDD_SPI: C2.1, C3.1, IC1.8 (VCC), R4.2, U1.30 (VDD_SPI)
/Target 1/WP: IC1.3 (/WP), U1.32 (SPIWP)
GND: C1.2, C2.2, C3.2, C4.2, C5.2, C6.2, C7.2, C8.2, C9.2, C10.2, C11.2, C12.2, IC1.4 (GND), JP1.1 (A), JP2.2 (B), R3.2, R6.1, R7.1, U1.57 (GND@0); also elsewhere on the board
unnamed: R6.2, U1.55 (IO46)
unnamed: R7.2, U1.50 (IO45)

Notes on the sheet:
Debug SWD/JTAG
GPIO/UART
Add your target here and connect it to the provided Debug and GPIO/UART connections. Debug and GPIO/UART connections are 5V tolerant. Min signal level is 3.3V
External Flash 512kB


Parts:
C13: 100n; C_0603_1608Metric_Pad1.05x0.95mm_HandSolder
C14: 10u; C_0603_1608Metric_Pad1.05x0.95mm_HandSolder
JP3: NRST; SolderJumper-2_P1.3mm_Open_TrianglePad1.0x1.5mm
R8: 100k; R_0603_1608Metric_Pad1.05x0.95mm_HandSolder
R9, R10: 10k; R_0603_1608Metric_Pad1.05x0.95mm_HandSolder
TP12: TMS; TestPoint_Pad_1.0x1.0mm
TP13: TCK; TestPoint_Pad_1.0x1.0mm
TP14: TDO; TestPoint_Pad_1.0x1.0mm
TP15: TDI; TestPoint_Pad_1.0x1.0mm
TP17: UART_TX; TestPoint_Pad_1.0x1.0mm
TP18: UART_RX; TestPoint_Pad_1.0x1.0mm
U0: ESP32-S3-WROOM-1-N8R8; XCVR_ESP32-S3-WROOM-1-N8R8; PARTREV v0.6

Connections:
+3V3: C14.1, R8.2, R9.2, U0.2 (3V3); also elsewhere on the board
/Target 0/GPIO0.0: U0.4 (IO4); also elsewhere on the board
/Target 0/GPIO0.1: U0.5 (IO5); also elsewhere on the board
/Target 0/GPIO0.2: U0.6 (IO6); also elsewhere on the board
/Target 0/GPIO0.3: U0.7 (IO7); also elsewhere on the board
/Target 0/RST_0: C13.1, JP3.1 (A), R8.1, U0.3 (EN); also elsewhere on the board
/Target 0/TCK|SWDCLK_0: R10.1, TP13.1, U0.32 (IO39); also elsewhere on the board
/Target 0/TDI|NC_0: TP15.1, U0.34 (IO41); also elsewhere on the board
/Target 0/TDO|SWO_0: TP14.1, U0.33 (IO40); also elsewhere on the board
/Target 0/TMS|SWDIO_0: R9.1, TP12.1, U0.35 (IO42); also elsewhere on the board
/Target 0/UART_RxD0: TP17.1, U0.37 (TXD0); also elsewhere on the board
/Target 0/UART_TxD0: TP18.1, U0.36 (RXD0); also elsewhere on the board
GND: C13.2, C14.2, JP3.2 (B), R10.2, U0.1 (GND), U0.40 (GND), U0.41_1 (GND), U0.41_2 (GND), U0.41_3 (GND), U0.41_4 (GND), U0.41_5 (GND), U0.41_6 (GND), U0.41_7 (GND), U0.41_8 (GND), U0.41_9 (GND); also elsewhere on the board

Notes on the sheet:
Debug SWD/JTAG
GPIO/UART
Add your target here and connect it to the provided Debug and GPIO/UART connections. Debug and GPIO/UART connections are 5V tolerant. Min signal level is 3.3V


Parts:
C15: 10u; C_0603_1608Metric_Pad1.05x0.95mm_HandSolder
R11, R12: 10k; R_0603_1608Metric_Pad1.05x0.95mm_HandSolder
TP23: TMS; TestPoint_Pad_1.0x1.0mm
TP24: TCK; TestPoint_Pad_1.0x1.0mm
TP25: TDO; TestPoint_Pad_1.0x1.0mm
TP26: TDI; TestPoint_Pad_1.0x1.0mm
TP28: UART_TX; TestPoint_Pad_1.0x1.0mm
TP29: UART_RX; TestPoint_Pad_1.0x1.0mm
U2: LoFive-R1

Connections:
+3V3: R11.2; also elsewhere on the board
+5V: C15.1, U2.1 (+5V); also elsewhere on the board
/Target 2/GPIO2.0: U2.24 (GPIO_20/PWM1.0); also elsewhere on the board
/Target 2/GPIO2.1: U2.25 (GPIO_21/PWM1.2); also elsewhere on the board
/Target 2/GPIO2.2: U2.26 (GPIO_22/PWM1.3); also elsewhere on the board
/Target 2/GPIO2.3: U2.27 (GPIO_23); also elsewhere on the board
/Target 2/RST_2: U2.4 (JTAG_TRST_N); also elsewhere on the board
/Target 2/TCK|SWDCLK_2: R12.1, TP24.1, U2.5 (JTAG_TCK); also elsewhere on the board
/Target 2/TDI|NC_2: TP26.1, U2.8 (JTAG_TDI); also elsewhere on the board
/Target 2/TDO|SWO_2: TP25.1, U2.6 (JTAG_TDO); also elsewhere on the board
/Target 2/TMS|SWDIO_2: R11.1, TP23.1, U2.7 (JTAG_TMS); also elsewhere on the board
/Target 2/UART_RxD2: TP28.1, U2.21 (GPIO_17/UART0.TX); also elsewhere on the board
/Target 2/UART_TxD2: TP29.1, U2.20 (GPIO_16/UART0.RX); also elsewhere on the board
GND: C15.2, R12.2, U2.2 (GND), U2.28 (GND); also elsewhere on the board

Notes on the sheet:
Debug SWD/JTAG
GPIO/UART
Add your target here and connect it to the provided Debug and GPIO/UART connections. Debug and GPIO/UART connections are 5V tolerant. Min signal level is 3.3V


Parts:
C16, C18, C21, C22, C23, C24, C25: 100n; C_0603_1608Metric_Pad1.05x0.95mm_HandSolder
C17, C20: 1u; C_0603_1608Metric_Pad1.05x0.95mm_HandSolder
C19: 10u; C_0603_1608Metric_Pad1.05x0.95mm_HandSolder
IC2: W25X40CLSNIG; Mouser Part Number 454-W25X40CLSNIG
JP4: NRST; SolderJumper-2_P1.3mm_Open_TrianglePad1.0x1.5mm
JP5: BOOT; SolderJumper-2_P1.3mm_Open_TrianglePad1.0x1.5mm
R13, R17, R18, R19: 100k; R_0603_1608Metric_Pad1.05x0.95mm_HandSolder
R14, R15, R16: 10k; R_0603_1608Metric_Pad1.05x0.95mm_HandSolder
TP34: TMS; TestPoint_Pad_1.0x1.0mm
TP35: TCK; TestPoint_Pad_1.0x1.0mm
TP36: TDO; TestPoint_Pad_1.0x1.0mm
TP37: TDI; TestPoint_Pad_1.0x1.0mm
TP39: UART_TX; TestPoint_Pad_1.0x1.0mm
TP40: UART_RX; TestPoint_Pad_1.0x1.0mm
U3: ESP32-C3; PARTREV V1.0

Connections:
+3V3: C19.1, C20.1, C21.1, C22.1, C23.1, C24.1, C25.1, R13.2, R14.2, R17.1, R18.1, U3.2 (VDD3P3), U3.3 (VDD3P3), U3.11 (VDD3P3_RTC), U3.17 (VDD3P3_CPU), U3.31 (VDDA), U3.32 (VDDA); also elsewhere on the board
/Target 3/BOOT: JP5.2 (B), R18.2, U3.15 (GPIO9)
/Target 3/CLK: IC2.6 (CLK), U3.22 (SPICLK)
/Target 3/CS: IC2.1 (/CS), R16.1, U3.21 (SPICS0)
/Target 3/DI: IC2.5 (DI(IO0)), U3.23 (SPID)
/Target 3/DO: IC2.2 (DO(IO1)), U3.24 (SPIQ)
/Target 3/GPIO3.0: U3.6 (GPIO2); also elsewhere on the board
/Target 3/GPIO3.1: U3.8 (GPIO3); also elsewhere on the board
/Target 3/GPIO3.2: U3.25 (GPIO18); also elsewhere on the board
/Target 3/GPIO3.3: U3.26 (GPIO19); also elsewhere on the board
/Target 3/HOLD: IC2.7 (/HOLD), U3.19 (SPIHD)
/Target 3/RST_3: C16.1, JP4.1 (A), R13.1, U3.7 (CHIP_EN); also elsewhere on the board
/Target 3/TCK|SWDCLK_3: R15.1, TP35.1, U3.12 (MTCK); also elsewhere on the board
/Target 3/TDI|NC_3: TP37.1, U3.10 (MTDI); also elsewhere on the board
/Target 3/TDO|SWO_3: TP36.1, U3.13 (MTDO); also elsewhere on the board
/Target 3/TMS|SWDIO_3: R14.1, TP34.1, U3.9 (MTMS); also elsewhere on the board
/Target 3/UART_RxD3: TP39.1, U3.28 (U0TXD); also elsewhere on the board
/Target 3/UART_TxD3: TP40.1, U3.27 (U0RXD); also elsewhere on the board
/Target 3/VDD_SPI: C17.1, C18.1, IC2.8 (VCC), R16.2, U3.18 (VDD_SPI)
/Target 3/WP: IC2.3 (/WP), U3.20 (SPIWP)
GND: C16.2, C17.2, C18.2, C19.2, C20.2, C21.2, C22.2, C23.2, C24.2, C25.2, IC2.4 (GND), JP4.2 (B), JP5.1 (A), R15.2, R19.1, U3.33 (GND); also elsewhere on the board
unnamed: R17.2, U3.14 (GPIO8)
unnamed: R19.2, U3.16 (GPIO10)

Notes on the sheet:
Debug SWD/JTAG
GPIO/UART
Add your target here and connect it to the provided Debug and GPIO/UART connections. Debug and GPIO/UART connections are 5V tolerant. Min signal level is 3.3V
External Flash 512kB



Board: 4 copper layers, 67.0 x 54.0 mm, 81 parts (56 on the bottom side), 67 nets.

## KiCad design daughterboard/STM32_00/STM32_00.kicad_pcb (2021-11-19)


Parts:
H1: MountingHoleDaughterboard; MountingHole_2.7mm_M2.5
J1: m2_keyA_67pin_daughterboard; m2_keyB

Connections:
+3V3: J1.6 (+3V3), J1.8 (+3V3), J1.10 (+3V3), J1.20 (+3V3), J1.21 (BOARD_DETECT); also elsewhere on the board
+5V: J1.1 (+5V), J1.3 (+5V), J1.5 (+5V), J1.7 (+5V)
/Target 0/GPIO0.0: J1.61 (TGT_GPIO0.0); also elsewhere on the board
/Target 0/GPIO0.1: J1.59 (TGT_GPIO0.1); also elsewhere on the board
/Target 0/GPIO0.2: J1.57 (TGT_GPIO0.2); also elsewhere on the board
/Target 0/GPIO0.3: J1.55 (TGT_GPIO0.3); also elsewhere on the board
/Target 0/RST_0: J1.73 (TGT_RST_0); also elsewhere on the board
/Target 0/TCK|SWDCLK_0: J1.67 (TGT_TCK|SWDCLK_0); also elsewhere on the board
/Target 0/TDI|NC_0: J1.71 (TGT_TDI|NC_0); also elsewhere on the board
/Target 0/TDO|SWO_0: J1.69 (TGT_TDO|SWO_0); also elsewhere on the board
/Target 0/TMS|SWDIO_0: J1.65 (TGT_TMS|SWDIO_0); also elsewhere on the board
/Target 0/UART_RxD0: J1.51 (TGT_UART_RxD0); also elsewhere on the board
/Target 0/UART_TxD0: J1.53 (TGT_UART_TxD0); also elsewhere on the board
/Target 1/GPIO1.0: J1.62 (TGT_GPIO1.0); also elsewhere on the board
/Target 1/GPIO1.1: J1.64 (TGT_GPIO1.1); also elsewhere on the board
/Target 1/GPIO1.2: J1.66 (TGT_GPIO1.2); also elsewhere on the board
/Target 1/GPIO1.3: J1.68 (TGT_GPIO1.3); also elsewhere on the board
/Target 1/RST_1: J1.50 (TGT_RST_1); also elsewhere on the board
/Target 1/TCK|SWDCLK_1: J1.56 (TGT_TCK|SWDCLK_1); also elsewhere on the board
/Target 1/TDI|NC_1: J1.52 (TGT_TDI|NC_1); also elsewhere on the board
/Target 1/TDO|SWO_1: J1.54 (TGT_TDO|SWO_1); also elsewhere on the board
/Target 1/TMS|SWDIO_1: J1.58 (TGT_TMS|SWDIO_1); also elsewhere on the board
/Target 1/UART_RxD1: J1.72 (TGT_UART_RxD1); also elsewhere on the board
/Target 1/UART_TxD1: J1.70 (TGT_UART_TxD1); also elsewhere on the board
/Target 2/GPIO2.0: J1.35 (TGT_GPIO2.0); also elsewhere on the board
/Target 2/GPIO2.1: J1.33 (TGT_GPIO2.1); also elsewhere on the board
/Target 2/GPIO2.2: J1.31 (TGT_GPIO2.2); also elsewhere on the board
/Target 2/GPIO2.3: J1.29 (TGT_GPIO2.3); also elsewhere on the board
/Target 2/RST_2: J1.47 (TGT_RST_2); also elsewhere on the board
/Target 2/TCK|SWDCLK_2: J1.41 (TGT_TCK|SWDCLK_2); also elsewhere on the board
/Target 2/TDI|NC_2: J1.45 (TGT_TDI|NC_2); also elsewhere on the board
/Target 2/TDO|SWO_2: J1.43 (TGT_TDO|SWO_2); also elsewhere on the board
/Target 2/TMS|SWDIO_2: J1.39 (TGT_TMS|SWDIO_2); also elsewhere on the board
/Target 2/UART_RxD2: J1.25 (TGT_UART_RxD2); also elsewhere on the board
/Target 2/UART_TxD2: J1.27 (TGT_UART_TxD2); also elsewhere on the board
/Target 3/GPIO3.0: J1.36 (TGT_GPIO3.0); also elsewhere on the board
/Target 3/GPIO3.1: J1.38 (TGT_GPIO3.1); also elsewhere on the board
/Target 3/GPIO3.2: J1.40 (TGT_GPIO3.2); also elsewhere on the board
/Target 3/GPIO3.3: J1.42 (TGT_GPIO3.3); also elsewhere on the board
/Target 3/RST_3: J1.24 (TGT_RST_3); also elsewhere on the board
/Target 3/TCK|SWDCLK_3: J1.30 (TGT_TCK|SWDCLK_3); also elsewhere on the board
/Target 3/TDI|NC_3: J1.26 (TGT_TDI|NC_3); also elsewhere on the board
/Target 3/TDO|SWO_3: J1.28 (TGT_TDO|SWO_3); also elsewhere on the board
/Target 3/TMS|SWDIO_3: J1.32 (TGT_TMS|SWDIO_3); also elsewhere on the board
/Target 3/UART_RxD3: J1.46 (TGT_UART_RxD3); also elsewhere on the board
/Target 3/UART_TxD3: J1.44 (TGT_UART_TxD3); also elsewhere on the board
GND: J1.2 (GND), J1.4 (GND), J1.9 (GND), J1.11 (GND), J1.22 (GND), J1.23 (GND), J1.34 (GND), J1.37 (GND), J1.48 (GND), J1.49 (GND), J1.60 (GND), J1.63 (GND), J1.74 (GND), J1.75 (GND); also elsewhere on the board

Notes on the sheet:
You can implement 4 targets per daugtherboard. Please use the corresponding hierarchical schematics for that.


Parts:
C1, C4, C5, C6, C7: 100n; C_0603_1608Metric_Pad1.05x0.95mm_HandSolder
C2, C3: 4.7u; C_0603_1608Metric_Pad1.05x0.95mm_HandSolder
JP1: NRST1; SolderJumper-2_P1.3mm_Open_TrianglePad1.0x1.5mm
JP2: NJRST1; SolderJumper-2_P1.3mm_Open_TrianglePad1.0x1.5mm
R1: 100k; R_0603_1608Metric_Pad1.05x0.95mm_HandSolder
TP1: JTMS-SWDIO; TestPoint_Pad_1.0x1.0mm
TP2: JTCK-SWCLK; TestPoint_Pad_1.0x1.0mm
TP3: JTDO-SWO; TestPoint_Pad_1.0x1.0mm
TP4: JTDI; TestPoint_Pad_1.0x1.0mm
TP6: USART1_TX; TestPoint_Pad_1.0x1.0mm
TP7: USART1_RX; TestPoint_Pad_1.0x1.0mm
U1: STM32F401CCUx; QFN-48-1EP_7x7mm_P0.5mm_EP5.6x5.6mm

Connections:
+3V3: C3.1, C4.1, C5.1, C6.1, C7.1, U1.1 (VBAT), U1.9 (VREF+), U1.24 (VDD), U1.36 (VDD), U1.48 (VDD); also elsewhere on the board
/Target 1/GPIO1.0: U1.10 (PA0); also elsewhere on the board
/Target 1/GPIO1.1: U1.11 (PA1); also elsewhere on the board
/Target 1/GPIO1.2: U1.12 (PA2); also elsewhere on the board
/Target 1/GPIO1.3: U1.13 (PA3); also elsewhere on the board
/Target 1/RST_1: C1.1, JP1.2 (B), U1.7 (NRST); also elsewhere on the board
/Target 1/TCK|SWDCLK_1: TP2.1, U1.37 (PA14); also elsewhere on the board
/Target 1/TDI|NC_1: TP4.1, U1.38 (PA15); also elsewhere on the board
/Target 1/TDO|SWO_1: TP3.1, U1.39 (PB3); also elsewhere on the board
/Target 1/TMS|SWDIO_1: TP1.1, U1.34 (PA13); also elsewhere on the board
/Target 1/UART_RxD1: TP6.1, U1.30 (PA9); also elsewhere on the board
/Target 1/UART_TxD1: TP7.1, U1.31 (PA10); also elsewhere on the board
GND: C1.2, C2.1, C3.2, C4.2, C5.2, C6.2, C7.2, JP1.1 (A), JP2.1 (A), R1.2, U1.2 (PC13), U1.3 (PC14), U1.4 (PC15), U1.5 (PH0), U1.6 (PH1), U1.8 (VSSA), U1.14 (PA4), U1.15 (PA5), U1.16 (PA6), U1.17 (PA7), U1.18 (PB0), U1.19 (PB1), U1.20 (PB2), U1.21 (PB10), U1.23 (VSS), U1.25 (PB12), U1.26 (PB13), U1.27 (PB14), U1.28 (PB15), U1.29 (PA8), U1.32 (PA11), U1.33 (PA12), U1.35 (VSS), U1.41 (PB5), U1.42 (PB6), U1.43 (PB7), U1.45 (PB8), U1.46 (PB9), U1.47 (VSS), U1.49 (VSS); also elsewhere on the board
unnamed: C2.2, U1.22 (VCAP1)
unnamed: JP2.2 (B), U1.40 (PB4)
unnamed: R1.1, U1.44 (BOOT0)

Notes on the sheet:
Debug SWD/JTAG
GPIO/UART
Add your target here and connect it to the provided Debug and GPIO/UART connections. Debug and GPIO/UART connections are 5V tolerant. Min signal level is 3.3V

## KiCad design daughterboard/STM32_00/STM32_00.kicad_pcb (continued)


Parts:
C9, C10: 100n; C_0603_1608Metric_Pad1.05x0.95mm_HandSolder
C11: 4.7u; C_0603_1608Metric_Pad1.05x0.95mm_HandSolder
JP3: NRST0; SolderJumper-2_P1.3mm_Open_TrianglePad1.0x1.5mm
R2, R3: 100k; R_0603_1608Metric_Pad1.05x0.95mm_HandSolder
TP12: SWDIO; TestPoint_Pad_1.0x1.0mm
TP13: SWCLK; TestPoint_Pad_1.0x1.0mm
TP16: USART1_TX; TestPoint_Pad_1.0x1.0mm
TP17: USART1_RX; TestPoint_Pad_1.0x1.0mm
U0: STM32G031F4P6; SOP65P640X120-20N

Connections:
+3V3: C10.1, C11.1, U0.4 (VDD/VDDA); also elsewhere on the board
/Target 0/GPIO0.0: U0.7 (PA0); also elsewhere on the board
/Target 0/GPIO0.1: U0.8 (PA1); also elsewhere on the board
/Target 0/GPIO0.2: U0.9 (PA2); also elsewhere on the board
/Target 0/GPIO0.3: U0.10 (PA3); also elsewhere on the board
/Target 0/RST_0: C9.1, JP3.2 (B), U0.6 (PF2-NRST); also elsewhere on the board
/Target 0/TCK|SWDCLK_0: TP13.1, U0.19 (PA15/PA14-BOOT0); also elsewhere on the board
/Target 0/TDI|NC_0: R3.1; also elsewhere on the board
/Target 0/TDO|SWO_0: R2.1; also elsewhere on the board
/Target 0/TMS|SWDIO_0: TP12.1, U0.18 (PA13); also elsewhere on the board
/Target 0/UART_RxD0: TP16.1, U0.20 (PB3/PB4/PB5/PB6); also elsewhere on the board
/Target 0/UART_TxD0: TP17.1, U0.1 (PB7/PB8); also elsewhere on the board
GND: C9.2, C10.2, C11.2, JP3.1 (A), R2.2, R3.2, U0.2 (PB9/PC14-OSC32_IN), U0.3 (PC15-OSC32_OUT), U0.5 (VSS/VSSA), U0.11 (PA4), U0.12 (PA5), U0.13 (PA6), U0.14 (PA7), U0.15 (PB0/PB1/PB2/PA8), U0.16 (PA11[PA9]), U0.17 (PA12[PA10]); also elsewhere on the board

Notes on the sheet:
Debug SWD/JTAG
GPIO/UART
Add your target here and connect it to the provided Debug and GPIO/UART connections. Debug and GPIO/UART connections are 5V tolerant. Min signal level is 3.3V
Not connected


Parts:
C12, C14, C15, C16: 100n; C_0603_1608Metric_Pad1.05x0.95mm_HandSolder
C13: 10u; C_0603_1608Metric_Pad1.05x0.95mm_HandSolder
JP4: NRST2; SolderJumper-2_P1.3mm_Open_TrianglePad1.0x1.5mm
JP5: NJRST2; SolderJumper-2_P1.3mm_Open_TrianglePad1.0x1.5mm
R4: 100k; R_0603_1608Metric_Pad1.05x0.95mm_HandSolder
TP22: JTMS-SWDIO; TestPoint_Pad_1.0x1.0mm
TP23: JTCK-SWCLK; TestPoint_Pad_1.0x1.0mm
TP24: JTDO-SWO; TestPoint_Pad_1.0x1.0mm
TP25: JTDI; TestPoint_Pad_1.0x1.0mm
TP27: USART1_TX; TestPoint_Pad_1.0x1.0mm
TP28: USART1_RX; TestPoint_Pad_1.0x1.0mm
U2: STM32L151C8TxA; LQFP-48_7x7mm_P0.5mm

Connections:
+3V3: C13.1, C14.1, C15.1, C16.1, U2.9 (VDDA), U2.24 (VDD), U2.36 (VDD), U2.48 (VDD); also elsewhere on the board
/Target 2/GPIO2.0: U2.10 (PA0); also elsewhere on the board
/Target 2/GPIO2.1: U2.11 (PA1); also elsewhere on the board
/Target 2/GPIO2.2: U2.12 (PA2); also elsewhere on the board
/Target 2/GPIO2.3: U2.13 (PA3); also elsewhere on the board
/Target 2/RST_2: C12.1, JP4.2 (B), U2.7 (NRST); also elsewhere on the board
/Target 2/TCK|SWDCLK_2: TP23.1, U2.37 (PA14); also elsewhere on the board
/Target 2/TDI|NC_2: TP25.1, U2.38 (PA15); also elsewhere on the board
/Target 2/TDO|SWO_2: TP24.1, U2.39 (PB3); also elsewhere on the board
/Target 2/TMS|SWDIO_2: TP22.1, U2.34 (PA13); also elsewhere on the board
/Target 2/UART_RxD2: TP27.1, U2.30 (PA9); also elsewhere on the board
/Target 2/UART_TxD2: TP28.1, U2.31 (PA10); also elsewhere on the board
GND: C12.2, C13.2, C14.2, C15.2, C16.2, JP4.1 (A), JP5.1 (A), R4.2, U2.2 (PC13), U2.3 (PC14), U2.4 (PC15), U2.5 (PH0), U2.6 (PH1), U2.8 (VSSA), U2.14 (PA4), U2.15 (PA5), U2.16 (PA6), U2.17 (PA7), U2.18 (PB0), U2.19 (PB1), U2.20 (PB2), U2.21 (PB10), U2.22 (PB11), U2.23 (VSS), U2.25 (PB12), U2.26 (PB13), U2.27 (PB14), U2.28 (PB15), U2.29 (PA8), U2.32 (PA11), U2.33 (PA12), U2.35 (VSS), U2.41 (PB5), U2.42 (PB6), U2.43 (PB7), U2.45 (PB8), U2.46 (PB9), U2.47 (VSS); also elsewhere on the board
unnamed: JP5.2 (B), U2.40 (PB4)
unnamed: R4.1, U2.44 (BOOT0)

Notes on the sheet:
Debug SWD/JTAG
GPIO/UART
Add your target here and connect it to the provided Debug and GPIO/UART connections. Debug and GPIO/UART connections are 5V tolerant. Min signal level is 3.3V


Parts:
C18, C20, C21, C22, C23: 100n; C_0603_1608Metric_Pad1.05x0.95mm_HandSolder
C19: 4.7u; C_0603_1608Metric_Pad1.05x0.95mm_HandSolder
JP6: NRST3; SolderJumper-2_P1.3mm_Open_TrianglePad1.0x1.5mm
JP7: NJRST3; SolderJumper-2_P1.3mm_Open_TrianglePad1.0x1.5mm
R5: 100k; R_0603_1608Metric_Pad1.05x0.95mm_HandSolder
TP33: JTMS-SWDIO; TestPoint_Pad_1.0x1.0mm
TP34: JTCK-SWCLK; TestPoint_Pad_1.0x1.0mm
TP35: JTDO-SWO; TestPoint_Pad_1.0x1.0mm
TP36: JTDI; TestPoint_Pad_1.0x1.0mm
TP38: USART1_TX; TestPoint_Pad_1.0x1.0mm
TP39: USART1_RX; TestPoint_Pad_1.0x1.0mm
U3: STM32F103C8Tx; LQFP-48_7x7mm_P0.5mm

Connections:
+3V3: C19.1, C20.1, C21.1, C22.1, C23.1, U3.1 (VBAT), U3.9 (VDDA), U3.24 (VDD), U3.36 (VDD), U3.48 (VDD); also elsewhere on the board
/Target 3/GPIO3.0: U3.10 (PA0); also elsewhere on the board
/Target 3/GPIO3.1: U3.11 (PA1); also elsewhere on the board
/Target 3/GPIO3.2: U3.12 (PA2); also elsewhere on the board
/Target 3/GPIO3.3: U3.13 (PA3); also elsewhere on the board
/Target 3/RST_3: C18.1, JP6.2 (B), U3.7 (NRST); also elsewhere on the board
/Target 3/TCK|SWDCLK_3: TP34.1, U3.37 (PA14); also elsewhere on the board
/Target 3/TDI|NC_3: TP36.1, U3.38 (PA15); also elsewhere on the board
/Target 3/TDO|SWO_3: TP35.1, U3.39 (PB3); also elsewhere on the board
/Target 3/TMS|SWDIO_3: TP33.1, U3.34 (PA13); also elsewhere on the board
/Target 3/UART_RxD3: TP38.1, U3.30 (PA9); also elsewhere on the board
/Target 3/UART_TxD3: TP39.1, U3.31 (PA10); also elsewhere on the board
GND: C18.2, C19.2, C20.2, C21.2, C22.2, C23.2, JP6.1 (A), JP7.1 (A), R5.2, U3.2 (PC13), U3.3 (PC14), U3.4 (PC15), U3.5 (PD0), U3.6 (PD1), U3.8 (VSSA), U3.14 (PA4), U3.15 (PA5), U3.16 (PA6), U3.17 (PA7), U3.18 (PB0), U3.19 (PB1), U3.20 (PB2), U3.21 (PB10), U3.22 (PB11), U3.23 (VSS), U3.25 (PB12), U3.26 (PB13), U3.27 (PB14), U3.28 (PB15), U3.29 (PA8), U3.32 (PA11), U3.33 (PA12), U3.35 (VSS), U3.41 (PB5), U3.42 (PB6), U3.43 (PB7), U3.45 (PB8), U3.46 (PB9), U3.47 (VSS); also elsewhere on the board
unnamed: JP7.2 (B), U3.40 (PB4)
unnamed: R5.1, U3.44 (BOOT0)

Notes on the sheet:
Debug SWD/JTAG
GPIO/UART
Add your target here and connect it to the provided Debug and GPIO/UART connections. Debug and GPIO/UART connections are 5V tolerant. Min signal level is 3.3V



Board: 4 copper layers, 67.0 x 54.0 mm, 61 parts (33 on the bottom side), 54 nets.

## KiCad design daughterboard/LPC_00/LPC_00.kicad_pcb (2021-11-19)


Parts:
H1: MountingHoleDaughterboard; MountingHole_2.7mm_M2.5
J1: m2_keyA_67pin_daughterboard; m2_keyB

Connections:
+3V3: J1.6 (+3V3), J1.8 (+3V3), J1.10 (+3V3), J1.20 (+3V3), J1.21 (BOARD_DETECT); also elsewhere on the board
+5V: J1.1 (+5V), J1.3 (+5V), J1.5 (+5V), J1.7 (+5V)
/Target 0/GPIO0.0: J1.61 (TGT_GPIO0.0); also elsewhere on the board
/Target 0/GPIO0.1: J1.59 (TGT_GPIO0.1); also elsewhere on the board
/Target 0/GPIO0.2: J1.57 (TGT_GPIO0.2); also elsewhere on the board
/Target 0/GPIO0.3: J1.55 (TGT_GPIO0.3); also elsewhere on the board
/Target 0/RST_0: J1.73 (TGT_RST_0); also elsewhere on the board
/Target 0/TCK|SWDCLK_0: J1.67 (TGT_TCK|SWDCLK_0); also elsewhere on the board
/Target 0/TDI|NC_0: J1.71 (TGT_TDI|NC_0); also elsewhere on the board
/Target 0/TDO|SWO_0: J1.69 (TGT_TDO|SWO_0); also elsewhere on the board
/Target 0/TMS|SWDIO_0: J1.65 (TGT_TMS|SWDIO_0); also elsewhere on the board
/Target 0/UART_RxD0: J1.51 (TGT_UART_RxD0); also elsewhere on the board
/Target 0/UART_TxD0: J1.53 (TGT_UART_TxD0); also elsewhere on the board
/Target 1/GPIO1.0: J1.62 (TGT_GPIO1.0); also elsewhere on the board
/Target 1/GPIO1.1: J1.64 (TGT_GPIO1.1); also elsewhere on the board
/Target 1/GPIO1.2: J1.66 (TGT_GPIO1.2); also elsewhere on the board
/Target 1/GPIO1.3: J1.68 (TGT_GPIO1.3); also elsewhere on the board
/Target 1/RST_1: J1.50 (TGT_RST_1); also elsewhere on the board
/Target 1/TCK|SWDCLK_1: J1.56 (TGT_TCK|SWDCLK_1); also elsewhere on the board
/Target 1/TDI|NC_1: J1.52 (TGT_TDI|NC_1); also elsewhere on the board
/Target 1/TDO|SWO_1: J1.54 (TGT_TDO|SWO_1); also elsewhere on the board
/Target 1/TMS|SWDIO_1: J1.58 (TGT_TMS|SWDIO_1); also elsewhere on the board
/Target 1/UART_RxD1: J1.72 (TGT_UART_RxD1); also elsewhere on the board
/Target 1/UART_TxD1: J1.70 (TGT_UART_TxD1); also elsewhere on the board
/Target 2/GPIO2.0: J1.35 (TGT_GPIO2.0); also elsewhere on the board
/Target 2/GPIO2.1: J1.33 (TGT_GPIO2.1); also elsewhere on the board
/Target 2/GPIO2.2: J1.31 (TGT_GPIO2.2); also elsewhere on the board
/Target 2/GPIO2.3: J1.29 (TGT_GPIO2.3); also elsewhere on the board
/Target 2/RST_2: J1.47 (TGT_RST_2); also elsewhere on the board
/Target 2/TCK|SWDCLK_2: J1.41 (TGT_TCK|SWDCLK_2); also elsewhere on the board
/Target 2/TDI|NC_2: J1.45 (TGT_TDI|NC_2); also elsewhere on the board
/Target 2/TDO|SWO_2: J1.43 (TGT_TDO|SWO_2); also elsewhere on the board
/Target 2/TMS|SWDIO_2: J1.39 (TGT_TMS|SWDIO_2); also elsewhere on the board
/Target 2/UART_RxD2: J1.25 (TGT_UART_RxD2); also elsewhere on the board
/Target 2/UART_TxD2: J1.27 (TGT_UART_TxD2); also elsewhere on the board
/Target 3/GPIO3.0: J1.36 (TGT_GPIO3.0); also elsewhere on the board
/Target 3/GPIO3.1: J1.38 (TGT_GPIO3.1); also elsewhere on the board
/Target 3/GPIO3.2: J1.40 (TGT_GPIO3.2); also elsewhere on the board
/Target 3/GPIO3.3: J1.42 (TGT_GPIO3.3); also elsewhere on the board
/Target 3/RST_3: J1.24 (TGT_RST_3); also elsewhere on the board
/Target 3/TCK|SWDCLK_3: J1.30 (TGT_TCK|SWDCLK_3); also elsewhere on the board
/Target 3/TDI|NC_3: J1.26 (TGT_TDI|NC_3); also elsewhere on the board
/Target 3/TDO|SWO_3: J1.28 (TGT_TDO|SWO_3); also elsewhere on the board
/Target 3/TMS|SWDIO_3: J1.32 (TGT_TMS|SWDIO_3); also elsewhere on the board
/Target 3/UART_RxD3: J1.46 (TGT_UART_RxD3); also elsewhere on the board
/Target 3/UART_TxD3: J1.44 (TGT_UART_TxD3); also elsewhere on the board
GND: J1.2 (GND), J1.4 (GND), J1.9 (GND), J1.11 (GND), J1.22 (GND), J1.23 (GND), J1.34 (GND), J1.37 (GND), J1.48 (GND), J1.49 (GND), J1.60 (GND), J1.63 (GND), J1.74 (GND), J1.75 (GND); also elsewhere on the board

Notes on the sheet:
You can implement 4 targets per daugtherboard. Please use the corresponding hierarchical schematics for that.


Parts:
C1: 4.7u; C_0603_1608Metric_Pad1.05x0.95mm_HandSolder
C2, C3: 100n; C_0603_1608Metric_Pad1.05x0.95mm_HandSolder
JP1: NRST; SolderJumper-2_P1.3mm_Open_TrianglePad1.0x1.5mm
R1, R2, R3: 100k; R_0603_1608Metric_Pad1.05x0.95mm_HandSolder
TP1: SWDIO; TestPoint_Pad_1.0x1.0mm
TP2: SWCLK; TestPoint_Pad_1.0x1.0mm
TP5: USART_TX; TestPoint_Pad_1.0x1.0mm
TP6: USART_RX; TestPoint_Pad_1.0x1.0mm
U1: LPC1114FDH28_102_5; LPC1114FDH28_1025; Mouser Part Number 771-LPC1114FDH28/102

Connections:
+3V3: C1.1, C2.1, C3.1, R1.2, U1.7 (VDDA), U1.21 (VDD); also elsewhere on the board
/Target 1/GPIO1.0: U1.24 (PIO0_1/CLKOUT/CT32B0_MAT2); also elsewhere on the board
/Target 1/GPIO1.1: U1.25 (PIO0_2/SSEL0/CT16B0_CAP0); also elsewhere on the board
/Target 1/GPIO1.2: U1.26 (PIO0_3); also elsewhere on the board
/Target 1/GPIO1.3: U1.27 (PIO0_4/SCL); also elsewhere on the board
/Target 1/RST_1: JP1.1 (A), R1.1, U1.23 (~RESET~/PIO0_0); also elsewhere on the board
/Target 1/TCK|SWDCLK_1: TP2.1, U1.3 (SWCLK/PIO0_10/SCK0/CT16B0_MAT2); also elsewhere on the board
/Target 1/TDI|NC_1: R2.1; also elsewhere on the board
/Target 1/TDO|SWO_1: R3.1; also elsewhere on the board
/Target 1/TMS|SWDIO_1: TP1.1, U1.12 (SWDIO/PIO1_3/AD4/CT32B1_MAT2); also elsewhere on the board
/Target 1/UART_RxD1: TP5.1, U1.16 (PIO1_7/TXD/CT32B0_MAT1); also elsewhere on the board
/Target 1/UART_TxD1: TP6.1, U1.15 (PIO1_6/RXD/CT32B0_MAT0); also elsewhere on the board
GND: C1.2, C2.2, C3.2, JP1.2 (B), R2.2, R3.2, U1.8 (VSSA), U1.20 (XTALIN), U1.22 (VSS); also elsewhere on the board

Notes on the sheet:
Debug SWD/JTAG
GPIO/UART
Add your target here and connect it to the provided Debug and GPIO/UART connections. Debug and GPIO/UART connections are 5V tolerant. Min signal level is 3.3V


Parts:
C4: 4.7u; C_0603_1608Metric_Pad1.05x0.95mm_HandSolder
C5, C6: 100n; C_0603_1608Metric_Pad1.05x0.95mm_HandSolder
JP2: NRST; SolderJumper-2_P1.3mm_Open_TrianglePad1.0x1.5mm
JP3: NJRST; SolderJumper-2_P1.3mm_Open_TrianglePad1.0x1.5mm
R4: 100k; R_0603_1608Metric_Pad1.05x0.95mm_HandSolder
R5, R6: 10k; R_0603_1608Metric_Pad1.05x0.95mm_HandSolder
TP11: SWDIO-TMS; TestPoint_Pad_1.0x1.0mm
TP12: SWCLK-TCLK; TestPoint_Pad_1.0x1.0mm
TP13: TDO; TestPoint_Pad_1.0x1.0mm
TP14: TDI; TestPoint_Pad_1.0x1.0mm
TP16: USART_TX; TestPoint_Pad_1.0x1.0mm
TP17: USART_RX; TestPoint_Pad_1.0x1.0mm
U0: LPC845M301JHI33Y; Mouser Part Number 771-LPC845M301JHI33Y

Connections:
+3V3: C4.1, C5.1, C6.1, R4.2, R5.2, U0.19 (VDD), U0.21 (VREFP); also elsewhere on the board
/Target 0/GPIO0.0: U0.11 (PIO0_27); also elsewhere on the board
/Target 0/GPIO0.1: U0.12 (PIO0_26); also elsewhere on the board
/Target 0/GPIO0.2: U0.13 (PIO0_25); also elsewhere on the board
/Target 0/GPIO0.3: U0.14 (PIO0_24); also elsewhere on the board
/Target 0/RST_0: JP2.1 (A), R4.1, U0.3 (PIO0_5/~RESET); also elsewhere on the board
/Target 0/TCK|SWDCLK_0: R6.1, TP12.1, U0.6 (SWCLK/PIO0_3/TCK); also elsewhere on the board
/Target 0/TDI|NC_0: TP14.1, U0.16 (PIO0_1/ACMP_I2/CLKINTDI); also elsewhere on the board
/Target 0/TDO|SWO_0: TP13.1, U0.24 (PIO0_0/ACMP_I1/TDO); also elsewhere on the board
/Target 0/TMS|SWDIO_0: R5.1, TP11.1, U0.7 (SWDIO/PIO0_2/TMS); also elsewhere on the board
/Target 0/UART_RxD0: TP16.1, U0.1 (PIO0_13/ADC_10); also elsewhere on the board
/Target 0/UART_TxD0: TP17.1, U0.2 (PIO0_12); also elsewhere on the board
GND: C4.2, C5.2, C6.2, JP2.2 (B), JP3.2 (B), R6.2, U0.20 (VREFN), U0.33 (VSS); also elsewhere on the board
unnamed: JP3.1 (A), U0.4 (PIO0_4/ADC_11/~TRST~/~WAKEUP)

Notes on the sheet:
Debug SWD/JTAG
GPIO/UART
Add your target here and connect it to the provided Debug and GPIO/UART connections. Debug and GPIO/UART connections are 5V tolerant. Min signal level is 3.3V

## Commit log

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2020-11-14 pretty much done with routing
    [3lanes.kicad_pcb, 3lanes.sch, 3lanes.step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]
2020-11-14 Fix DRC
    [probe-rs-hive.kicad_pcb]
2020-11-14 Add 3d model and structure diagram
    [PCI-E x1.stp, probe-rs-hive.kicad_pcb]
2020-11-14 Make PCB connections sturdier by making the PCB extend under the connectors
    [3lanes.kicad_pcb, probe-rs-hive.kicad_pcb]
2020-11-14 Add a line buffer/multiplexer to RST
    [3lanes.iam, 8channels.iam, hive.iam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]
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2020-11-15 Add caps & get rid of the jumpers & add two more GND lanes to the connector & remove two OE select signals
    [8channels.kicad_pcb, 8channels.sch]
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2020-11-21 Now with LDO per 8 channel board
    [8channels.kicad_pcb, 8channels.sch]
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2020-11-21 Silk fix
    [8channels.kicad_pcb, 8lanes.kicad_pcb]
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2020-11-21 Add a daughterboard template
    [daughterboard_template.kicad_pcb, daughterboard_template.sch]
2020-11-21 Use an angled connector
    [8channels.iam, 8channels.kicad_pcb, 8lanes.kicad_pcb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]
2020-11-22 Update the 3d assembly
    [hive.iam]
2020-11-22 More distance between lanes
    [8lanes.kicad_pcb]
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2021-09-18 replaced STDC14 with ARM 10pin
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2021-09-22 added component library & testboard schematics
    [NCP1117DT33T5G.STEP, testboard.kicad_pcb, testboard.sch]
2021-09-22 started design of testboard
    [PCA9535CPW_118.step, SN74CB3T16211DGGR.step, testboard.sch]
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2021-09-23 added projects for probe&target shields
    [probe_shield.kicad_pcb, probe_shield.sch, target_stack_shield.kicad_pcb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]
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2021-09-24 Testboard layout edits to comply to manufacturer
    [testboard.kicad_pcb]
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2021-09-25 finished probe shield schematics
    [probe_shield.sch]
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2021-09-25 added power LED + corrections on probe shield schematics
    [150060VS75000.stp, probe_shield.sch]
2021-09-25 started with target stack shield schematics
    [bus_switches.sch, io_expander.sch, target_stack_shield.sch]
2021-09-26 further work on target stack shield schematics
    [KRTB_AILMS1-5B5C-B1B12-0-R18.stp, bus_switches.sch, io_expander.sch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]
2021-09-29 schematic updates, start of probe shield layout
    [probe_shield.kicad_pcb, probe_shield.sch, target_stack_shield-OLD.kicad_pcb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]
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2021-09-30 implemented changes according to feedback, finished target shield schematics
    [bus_switches.sch, io_expander.sch, probe_shield.sch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]
2021-09-30 further work on probe shield layout
    [probe_shield.kicad_pcb]
2021-09-30 added probe male connector, added 3d models and footprints for shield connectors
    [ESQ-113-24-L-D.stp, ESQ-120-24-L-D.stp, FTSH-105-01-F-DV-007-K.stp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]
2021-10-01 updated testboard schematics to new symbols
    [testboard.sch]
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2021-10-01 probe shield 3d model update
    [probe_shield.kicad_pcb, probe_shield.sch]
2021-10-04 work on target stack shield layout
    [bus_switches.sch, io_expander.sch, target_stack_shield.kicad_pcb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]
2021-10-05 Further work on layout
    [bus_switches.sch, io_expander.sch, target_stack_shield.kicad_pcb]
2021-10-06 finished target stack shield layout
    [bus_switches.sch, target_stack_shield.kicad_pcb, target_stack_shield.sch]
2021-10-06 updates on silkscreen, added 3d renders
    [probe_shield.kicad_pcb, target_stack_shield-OLD.kicad_pcb, target_stack_shield.kicad_pcb]
2021-10-06 fixed broken silkscreen
    [target_stack_shield.kicad_pcb]
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2021-10-07 Added 3d assembly and probe holder 3D model
    [m2_5_standoff_16mm.FCStd, m2_5_standoff_16mm.step, m2_5_standoff_18mm.FCStd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]
2021-10-11 started with daughterboard template
    [daughterboard_template.kicad_pcb, daughterboard_template.sch]
2021-10-12 added preliminary daughterboard template
    [daughterboard_template.kicad_pcb, daughterboard_template.sch, target0.sch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]
2021-10-12 started with daughterboard template layout
    [daughterboard_template.sch, target0.sch, target1.sch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]
2021-10-13 finished daughterboard template layout
    [daughterboard_template.kicad_pcb, daughterboard_template.step, target_stack_shield.kicad_pcb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]
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2021-10-16 added partlist and prices
    [bus_switches.sch, io_expander.sch, partlist_probe_shield.xlsx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]
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2021-10-31 changed PCIE 64 to M.2 Key B connector
    [2199230-3.step, daughterboard_template.kicad_pcb, daughterboard_template.sch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]
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2021-11-03 added M2.5 Daughterboard backup mounting solution
    [daughterboard_template.kicad_pcb, daughterboard_template.sch, daughterboard_template.step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]
2021-11-04 added project library to daughterboard template + minor pcb adjustments
    [daughterboard_template.kicad_pcb, target_stack_shield.kicad_pcb]
2021-11-05 minor adjustments to daughterboard template, added STM32 daughterboard schematics
    [STM32_00.kicad_pcb, STM32_00.sch, target0.sch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]
2021-11-05 started with LPC daughterboard
    [LPC845M301JHI33Y.stp, LPC_00.kicad_pcb, LPC_00.sch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]
2021-11-07 finished LPC Daughterboard schematics
    [LPC1114FDH28_102_5.stp, target0.sch, target1.sch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]
2021-11-07 minor fix to daughterboard template
    [target0.sch, target1.sch, target2.sch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]
2021-11-07 started with ATSAMD daughterboard schematics
    [ATSAMD_00.kicad_pcb, ATSAMD_00.sch, target0.sch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]
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2021-11-18 small corrections to layout
    [probe_shield.kicad_pcb, target_stack_shield.kicad_pcb]
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2021-12-10 fixed NRF51822 footprint soldermask, fixed SilÃkscreen of ESP32_SIFIVE daughterboard
    [ESP32_SIFIVE_00.kicad_pcb, NRF_00.kicad_pcb]
2021-12-16 updated LED resistor values, updated partlists, minor change to daughterboard template
    [partlist_probe_shield.xlsx, partlist_target_stack_shield.xlsx, probe_shield.sch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]
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2022-01-21 enhanced mechanical PCB drawings of stack shields and daughterboard template
    [daughterboard_template.kicad_pcb, probe_shield.kicad_pcb, target_stack_shield.kicad_pcb]

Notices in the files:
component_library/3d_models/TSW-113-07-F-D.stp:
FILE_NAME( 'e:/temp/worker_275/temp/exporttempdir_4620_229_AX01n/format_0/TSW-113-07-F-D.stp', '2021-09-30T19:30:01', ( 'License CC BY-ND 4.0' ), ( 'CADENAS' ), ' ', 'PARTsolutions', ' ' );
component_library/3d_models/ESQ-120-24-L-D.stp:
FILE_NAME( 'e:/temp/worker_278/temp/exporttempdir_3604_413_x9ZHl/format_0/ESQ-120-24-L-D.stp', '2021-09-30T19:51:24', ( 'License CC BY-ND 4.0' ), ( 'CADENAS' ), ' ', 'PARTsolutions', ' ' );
